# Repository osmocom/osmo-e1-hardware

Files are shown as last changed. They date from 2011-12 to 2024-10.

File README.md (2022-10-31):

osmo-e1-hardware - Collection of various E1/TDM hardware projects
=================================================================

This repository contains a variety of different projects related to
E1/TDM hardware interfaces

* `icE1usb` (fully-fledged USB E1 interface adapter)
* `osmo-e1-tracer` (fully integrated passive raw bitstream tracer)
* `osmo-e1-tap` (passive high-impedance E1/T1 tap)
* `osmo-e1-xcvr` (E1 LIU + magnetics)
  https://osmocom.org/projects/e1-t1-adapter/wiki/Osmo-e1-xcvr

icE1usb
-------

The Osmocom icE1usb project is an open source hardware, gateware and firmware
project implementing a USB-attached interface for E1 circuits.  Use this
if you want to implement a system speaking to an E1 circuit, such as
* a GSM BSC (using [OsmoBSC](https://osmocom.org/projects/osmobsc/wiki)) talking Abis/E1 to a GSM Base station,
* using [osmo-gbproxy](https://osmocom.org/projects/osmo-gbproxy/wiki/Osmo-gbproxy) to convert classing Gb/E1 to Gb/IP
* talking to legacy ISDN PRI equipment such as PBX, RAS servers, etc.
* connecting legacy ISDN PRI equipment such as PBX, RAS servers, etc. to
  the [OCTOI comminity TDMoIP network](https://osmocom.org/projects/octoi/wiki)

Depending on your USB host controller, it supports one or two E1
circuits. Most host controllers can only support one E1 circuit.

In order to provide a stable E1 clock reference, it contains a GPS disciplined oscillator.

See <https://osmocom.org/projects/e1-t1-adapter/wiki/IcE1usb> for more details.

Fully assembled units can be purchased at the [sysmocom
webshop](https://shop.sysmocom.de/Osmocom-icE1usb-E1-interface-for-USB/icE1usb-kit)

Check the `hardware/icE1usb`, `firmware/ice40-riscv/icE1usb` directories in this repository.

The host software is provided either
* via [osmo-e1d](https://osmocom.org/projects/osmo-e1d/wiki), or
* via the [icE1usb DAHDI driver](https://gitea.osmocom.org/retronetworking/dahdi-linux)

osmo-e1-tracer
--------------

This is a fully integrated design that allows you to obtain bi-directional high-impedance
bitstream E1 traces.  It features an iCE40 FPGA with USB + E1 cores from Sylvain Munaut,
as well as two E1 LIUs.

See <https://osmocom.org/projects/e1-t1-adapter/wiki/E1_tracer> for more details.

Fully assembled units can be purchased made-to-order from
[sysmocom](https://sysmocom.de).

Check the `hardware/e1-tracer`, `firmware/ice40-riscv/e1-tracer` and `software/e1-tracer`
directories in this repository.

osmo-e1-xcvr
------------

This was  a simple hardware project that aims to generate a reusable module
for interfacing E1/T1/J1 lines from various custom FPGA/CPLD/microcontroller
projects.  Consider it part of an earlier R&D setup before icE1usb and
osmo-e1-tracer were around.

The board contains transformers, the analog circuitry, the LIU (line interface
unit), an oscillator as well as an integrated transceiver chip.

It exposes the control interface (SPI) as well as the decoded synchronous
Rx/Tx bitstreams each on a 2x5pin header.

Framer, Multiplexer, HDLC decoder or anything like that is out-of-scope for
now.  The idea really is to provide an interface as low-level as possible.

One of the ideas is to create a "soft E1" interface, where the Rx/Tx bitstreams
are interfaced with the SSC of an AT91SAM3S and subsequently passed into a PC
via USB.  The 2Mbps signal is very low-bandwidth, so that a pure software
implementation should be absolutely no problem for todays computing power.

See <https://osmocom.org/projects/e1-t1-adapter/wiki/Osmo-e1-xcvr> for more details

Check the `hardware/e1-xcvr` directory in this repository.

osmo-e1-tap
-----------

This is a small passive board that allows you to perform high-impedance tracing on an E1
or T1 line.

Fully assembled units can be purchased at the [sysmocom
webshop](https://shop.sysmocom.de/E1-T1-tap-adapter/e1-tap).

Check the `hardware/e1-tap` directory in this repository.

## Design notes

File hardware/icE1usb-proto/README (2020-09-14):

icE1usb-proto: Early prototype (PMOD based)
===========================================

Files are hosted here for archival purposes only.

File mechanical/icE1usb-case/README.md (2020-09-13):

icE1usb case design
===================

The PCB has been specifically designed to fit into the SZOMK AK-C-B-37 with
silicone rings and custom end panels.

The design for the end panel can be found here in standard DXF format,
along with the various manufactured revisions and a change log.

Designs are (C) 2020 Sylvain Munaut and released under CC-BY-SA 4.0.

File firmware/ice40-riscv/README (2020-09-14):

Firmware for iCE40 based board
==============================

The icE1usb, icE1usb-proto and e1-tracer boards are running very similar
gateware, all based around a PicoRV32 RISC-V softcore supported by custom
hardware cores to deal with USB and E1.

License
-------

Files in here are licended either under GPLv3 or LGPLv3 depending on the
specific file. Refer to the notice at the top of each file.

Full text for both licenses is included next to this README.

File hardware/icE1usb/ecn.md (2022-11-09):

Electrical Engineering Change Notes
===================================

Revision 0.0
------------

### Description

First revision

### Manufactured

Boards ordered from Aisler on August 12th 2020.
Gerbers used are in the repo.

### Issues noticed

* The E1 TX pulse were very weak. Probably would have worked but to rise the pulse amplitude
  to 1.5 V, the series resistance were lowered to 27R. (Original iCEbreaker proto had 33R on
  the icebreaker + 47R on the PMOD. The bitsy proto only had the 47R)

### Notes

* Kicad files were not kept since it's the same schematic and layout as rev 0.1
  with some value changed and all boards were either built with new values or reworked.

Revision 0.1
------------

### Description

This revision is mostly just to keep a record of the changes that were applied
directly on the r0.0 prototypes and how they were assembled.

### Changes compared to previous revisions

* E1 TX side resistors changed to 27R (from 82R)

* Consequently all other uses of 82R were updated
    * PLL filter switched to use 120R
    * Series resistor for clock switched to 27R (which is probably better)

* Connection from GND to USB shield changed to 91k (from 1k5)

* All 47R networks were swapped for 33R. 
    * New value was picked so that including the UP5k drive impedance (~20R),
      it matches 50R more closely for USB
    * Other places where it's used don't matter much.
    * E1 LED current is dominated by 595 output impedance anyway.
    * 33R is just as fine for serial termination/EMI isolation for GPS signals.

* Some silkscreen label was added on the PCB

### Manufactured

Rev 0.0 PCBs were used and assembled / reworked to match this revision.
Two boards in total: one for @LaF0rge and one for @tnt.

### Issues noticed / remaining

* Flash footprint is wrong. The selected flash is not using the "wide" variant of SO8.

* The NT/TE selection pin-header is completely wrong

* The lightpipe is a bit loose. Turns out the holes came out 10% oversized out of Aisler :/
  Dimensions left as the manufacturer ones and hope that the prod are closer to nominal.

* The E1 bias configuration should probably have been reversed with the `bias_fixed`
  assigned to the `_n` side. This way the variable bias would have been lower and the common
  mode voltage closer to what the comparator expect for LVDS.

  This however would break compatibility with the proto which is a waste and has no real-world
  impact. The common-mode voltage change is minimal and comparator work fine where it is. And
  even if it was an issue we could put the variable bias lower and flip the input polarity in
  the bitstream.

Revision 1.0
------------

### Description

Production version, sent to manufacturer for production.

### Changes compared to previous revisions

* Silkscreen updated

* Flash footprint updated to narrow SO8 (150mil)

* Rewired the NT/TE header properly

* Changed RF trackwidth to 0.175 mm to account for production stackup

* Changed board outline to cater to connectors being more outward
    * Extended by 0.5 mm on front/back but only in the center part of the PCB
      to avoid interfering wih the silicone ring
    * Reworked the 'tabs'
    * Adjusted the expected end panel position lines to account for 1 mm silicone thickness

* Adjust positions of connectors / ... 
    * Moved RGB led & lightpipe outward by 500u
    * Moved Serial connector outward by 500u
    * Moved USB outward by 500u
    * Moved GPIO RJ45 outward by 500u
    * Moved dual-RJ45 outward by 500u
    * Moved button outward by 750u

* As a result of those moves some minor adjustments were made
    * Copper fills extended by 500u on the left side + reworked upper corner
    * Copper fills extended by 500u on the right side
    * To avoid the small protrusions in the planes, vias in the RX CT bias were moved inward

* Rerouted 1v2 on the bottom to add more distance from GND vias. Also widened the
  T junction to one of the via to 0.6 mm

### Manufactured

* 52 units ( 26 panels ) were manufactured in Aug/Sep 2020 and all came back in perfect working
  order.

### Issues noticed

* PCB is slightly loose in the case because the case we used were slightly over size.
    * The "side tabs" could be made slightly larger (and possibly slight round curve) to
      have a bit more friction.
    * The "front/back" edge part that touches the silicone ring could be made a bit longer
      to compress the silicone a bit.
    * Those 2 would be very slight changes, like ~ 0.1mm on each side, still have to account
      for possible tolerance in the cases that could be smaller than nominal !

* The I2C connection to the GPS conflicts with usage for the extension port. Turns out the
  chinese GPS module act as a master on those lines.
  See https://projects.osmocom.org/issues/5664 for details of the issue.

### Notes

* Adding series resistor for `gps_reset_n` and `gps_pps` was considered, but deemed not necessary.
    * Traces are short, always close to ground plane and we have no strong RF/EMI emitter onboard.
    * `gps_pps` is generated by the module itself, so any fast edge is coming from the module.
    * `gps_reset_n` is static.

* Adding a capacitor between `tx_hi` and `tx_lo` (after the series resistor) was also an option.
  Testing showed it didn't really change / improve the pulse shape and simulation showed increased
  peak current (and thus stress on the UP5k drivers). I considered adding a DNP footprint but area
  was a bit cramped and some more work would have been needed for something that would most likely
  stay unpopulated.

* A thought that occured to me to improve pulse shape is to use an external buffered gate (those
  sot-23/sc-67 single/double gate buffer ICs) and possibly putting it in parallel :

```
From  -----,----------,--\/\/\/--->  To TX
FPGA        \        /     R         Magnetics
             \__|\__/
	        |/
```

  This would take strain off the FPGA driver, provide more current and the  delay of the gate
  might actually help make the pulse shape more correct.

Revision 1.1
------------

### Description

Updated production version with minor fixes and a few adaptations for further production runs
by sysmocom.

### Changes compared to previous revisions

* Updated to kicad 6 format
* Renumbered schematic pages
* Added NO jumpers on the I2C lines to GPS module
* Added fiducials
* Silkscreen updated

### Manufactured

* 105 units manufactured by sysmocom at the end of 2022.

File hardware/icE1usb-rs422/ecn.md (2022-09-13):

Electrical Engineering Change Notes
===================================

Revision 0.1
------------

### Description

First revision

### Manufactured

Boards ordered from Aisler on August 15th 2022.
Sent directly the Kicad files. See r0.1/ directory.

### Issues noticed

* Missing I2C pull-ups on the isolated side.

* The pinout for the external RJ45 is completely wrong.

* The 1k across 12V dissipates 144 mW. It's above the rating for
  the jelly-bean 0603 resistors I originally used and it also
  gets quite warm.

* The 120R termination resistors also can dissipate quite a bit
  of power. Technicaly up to 6V across leading to 300 mW !
  In our case, it's more like 3V so it's only 75 mW but still,
  some margin would be nice.

* The linear 5V reg does heat up a bit. Nothing critical, but
  could be improved.

### Notes

* All boards have been reworked to fix most pressing issues :
    * 3k3 pullups added on the isolated side.
    * Cut & manually rewired the external RJ45 pinout.
    * 1k across 12V switched to high power 250mW part.
    * 120R termination switched to high power 250mW part.

* Boards location:
    * One remained with tnt.
    * Two sent to LaF0rge. One will be installed in the datacenter
      to be used with the OCTOI hub, the other will remain for testing.

Revision 0.2
------------

### Description

Potential future version, if ever done ...

### TODO

* Add I2C pull ups on the isolated side.

* Fix the external RJ45 pinout.

* Use switchmode converter for supply. AP3211 looks like a good candidate.

* Replace the 1k resistor across 12V with a resistor + zener + depletion n-mos
  so that it appears as 1k when supply is < ~4V but currents limit above that.

* Use 0805 termination resistors maybe ? Or at least spec those as high power
  variants.

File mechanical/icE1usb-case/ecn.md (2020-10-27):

Mechanical Engineering Change Notes
===================================

Revision 0.0
------------

### Description

Original design

### Manufactured

* Two pairs of front/back panels were ordered at [Schaeffer](https://www.schaeffer-ag.de/en/) in
  1.5 mm thickness since 1.2 mm is not available.

* Back panel was cut at Makilab by @tnt .

### Issues noticed

After trying to fit the back panel, it became obvious that the calculations were off and the
height of the PCB (1.6 mm) was not properly accounted for, resulting in openings that were all
1.6 mm too low.

### Notes

* DXF files were not kept.
* Feeds & Speeds in the FreeCAD toolpaths were completely off and were overriden manually.

Revision 0.1
------------

### Description

First revision done after the 1.6 mm offset error was noticed. It was done even before the
rev 0.0 panels were back from Schaeffer.

### Changes compared to previous revision

* Moved all opening 1.6 mm up.
* Size of the 'mouse ears' (for square holes) has been reduced to 2 mm diameter.
* Also made sure each square opening is a single poly-line in the DXF.

### Manufactured

* Cut two pairs of front/back panels at Makilab for the two proto cases. One of the back
  panel was the previously 'bad' one (rev 0.0) and so the opening is now too wide and not
  looking great, but it fits and is functional.

### Issues noticed

* The SMA hole height is too low. Nominal height above PCB was 6.4mm but that's for the
  TE-Connectivity part. The SMA we're using is more like 6.85mm above the surface. To fix
  this, the hole will be changed to be taller than wide to accomodate both parts.

* All the square opening (single RJ45, dual RJ45, USB) have their excess located at the top
  and have their bottom flush with the expected pcb height. This is different from the circular
  opening which are aligned on their center. So change the positions so the excess clearance is
  evenly distributed top/bottom of the expected position.

# Notes

* Although new FrontPanelDesigner files were made for this revision, they were never
  submitted / manufactured.

Revision 1.0
------------

### Description

Production version, sent to manufacturer for production.

### Changes compared to previous revision

* Converted the SMA opening from a pure-circle to two half circles connected by lines.
  The upper half circle is 0.5 mm above the previous center

* Moved USB, 1xRJ45 and 2xRJ45 opening 0.2 mm down

### Manufactured

* A run of 55 cases has been done, with end panels cut by the manufacturer.

### Issues noticed

* The cases are nominally 85 mm long, however seems all of them (both from prototype and
  production were slightly longer by about 0.2-0.4mm). This might be a result of the surface
  processing.

* The SMA hole is very close to the chamfer of the screw hole, leaving very little material
  between the two and on a couple of panels, it was ripped out or slightly bent by the end-mill
  during manufacturing. Most panels were fine and some slightly bent one could be corrected,
  but something to keep in mind.

* Also as a consequence of that we can't put a nut on the SMA on the inside (to grab panel by
  both side). Although I'm not sure it'd be good anyway. The SMA is the only element fixed to
  the panel (and thus the case), so all the forces of plugging connector are transfered through
  the PCB, through the SMA to the case. (because the PCB is slightly loose in the case to account
  for possible tolerances, see also comments in the PCB ECN).

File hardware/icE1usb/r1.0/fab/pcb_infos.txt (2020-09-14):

PCB material: FR-4
Board thickness: 1.6MM
Copper thickness: 1oz
Stackup:
	* L1-L2 is 0.1MM
	* 50R traces 6.5mil
Surface finishing: ENIG
Solder mask: Green
Silkscreen: White

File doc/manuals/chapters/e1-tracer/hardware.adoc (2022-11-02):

[[hardware]]
== e1-tracer Hardware

The e1-tracer Hardware consists of a single circuit board, mechanically
either assembled into a desktop enclosure (KOH variant) or into a 3U component
carrier module (BGT variant).

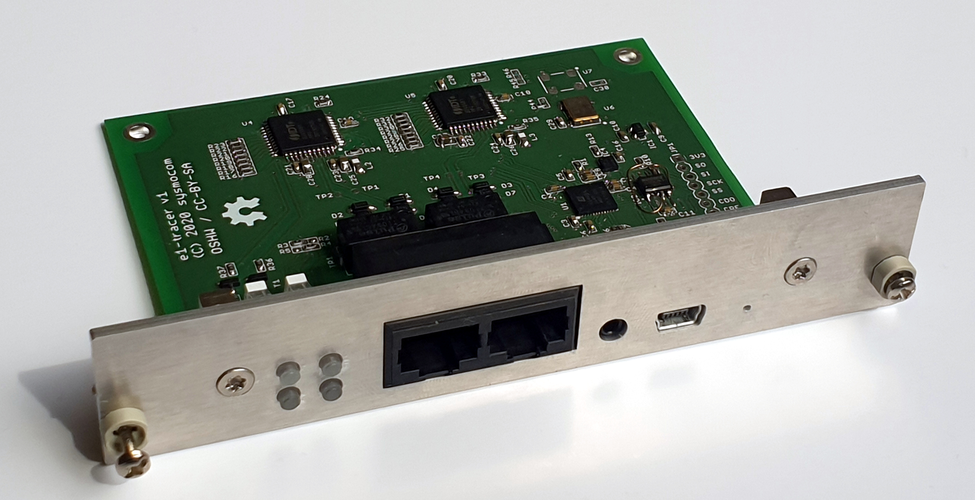
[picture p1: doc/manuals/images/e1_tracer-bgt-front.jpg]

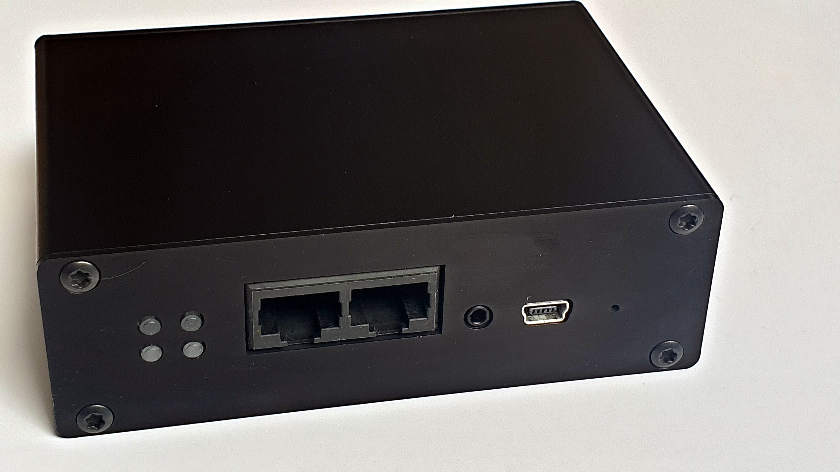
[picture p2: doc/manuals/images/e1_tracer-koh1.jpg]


It's main building blocks are:

* an iCE40 FPGA
* two E1 Line Interface Unit ICs
* two E1 line interface analog (transformers, biasing networks and ESD protection)

=== Schematics / Board Layout

As e1-tracer is an OSHW (Open Source Hardware) project, the full schematics
and design files are publicly available.

The design files in EAGLE format are available at https://git.osmocom.org/osmo-e1-hardware/tree/hardware/e1-tracer

PDF rendered schematics are available at https://gitea.osmocom.org/retronetworking/osmo-e1-hardware/raw/branch/master/hardware/e1-tracer/e1-tracer_sch.pdf

=== Connectors / LEDs

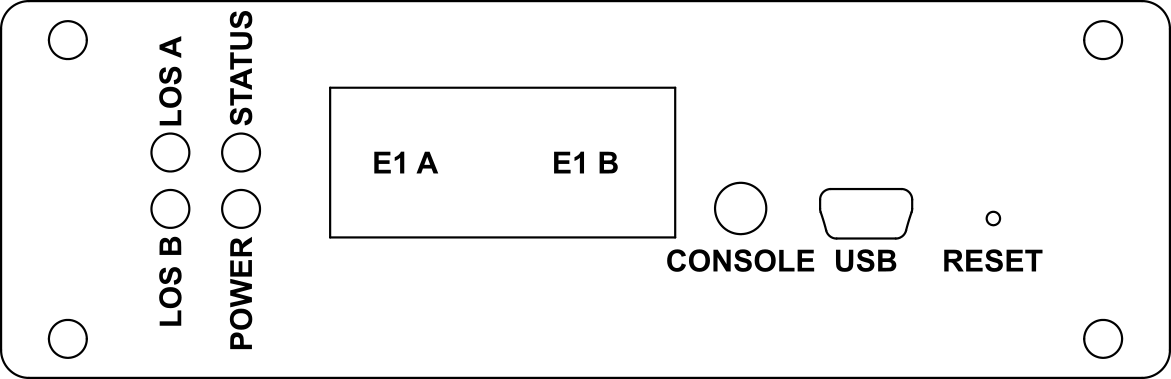
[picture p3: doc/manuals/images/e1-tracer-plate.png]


From left to right, there are the following LED indcators, connectors and buttons:

* LED block with 4 LED's
* Primary E1 Port (E1 A)
* Secondary E1 Port (E1 B)
* Serial Console Connector
* USB Connector
* Bootloader Button

==== LEDs

The left-most column of LEDs consists of two red *LOS LEDs*.
They indicate a LOS (Loss Of Signal) condition for the respective E1 direction.  It is normal for the LEDs to be illuminated even in presence of a valid E1 signal until the host software has fully initialized the firmware for the first time after power-up.

The right column of LEDs consists of two further LEDs:

* a multi-color *STATUS LED* on the top
* a green *POWER LED* on the bottom

The *STATUS LED* is used by the firmware to indicate a variety of status
information.  Pleas see the firmware documentation in <<firmware>>.

The green *POWER LED* is illuminated as soon as the device has DC power.

==== J1A and J1B: E1 Interface Connectors

There are two RJ45 connectors next to each other.

Those are the connections for your symmetric 120 Ohms E1 interface
circuit.  You insert the e1-tracer into your E1 link.  The two ports are
internally wired straight-through, so you can insert the e1-tracer into
your E1 link.

The actual tracing functionality is implemented via a high-impedance
tap, which will not disturb the normal E1 communications link. The link
remains unaffected even if the e1-tracer is unpowered.

.Pin-out of RJ45 E1 connectors
[options="header"]
|===
| Pin | Function (TE) | Function (NT Mode)
| 1   | Pair A        | Pair A
| 2   | Pair A        | Pair A
| 3   | not used      | not used
| 4   | Pair B        | Pair B
| 5   | Pair B        | Pair B
| 7   | not used      | not used
| 8   | not used      | not used
|===

NOTE: E1 cables use RJ45 like Ethernet, but Ethernet cables have a
different pin-out.  Particularly, you cannot use an Ethernet cross-over
cable as an E1 cross-over!

==== X1: USB Connector

The USB connector is a USB Mini B connector.   The e1-tracer uses
USB 1.1 full-speed signals.  As the e1-tracer is a bus-powered device,
5V DC power is also sourced from this connector.

==== X2: Serial Console Connector

The serial console is used for development and debugging.  It uses an
Osmocom-style 2.5mm stereo TRS jack.

The serial console uses 3.3V CMOS logic levels

The serial console uses a rate of 1000000 bps.

The pin-out is as follows:

* Tip: Tx output from PC (Rx input of e1-tracer)
* Ring: Rx input of PC (Tx output of e1-tracer)
* Shield: GND

A compatible cable can be sourced from the sysmocom web-shop at
http://shop.sysmocom.de/.

Note that CP2102 based cables require special programming to support
the baud rate of 1000000 (as opposed to the more standard 921600).

[[hw-pushbutton]]
=== Bootloader Button

There is a push-button next to the _USB B connector_.   It is recessed
to protect against accidental use.   You will need to use a paper clip,
pen tip or other similar object to push it.

The button, when pressed while power-up, can be used to force booting
into the DFU loader in order to recover from a broken firmware
installation.

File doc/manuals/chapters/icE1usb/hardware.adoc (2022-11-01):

[[hardware]]
== icE1usb Hardware

The icE1usb Hardware consists of a single circuit board (in an optional
enclosure).

It's main building blocks are:

* an iCE40 FPGA
* Two E1 line interface (transformers, biasing networks and ESD protection) footnote:[Second interface requires firmware >= 0.2 and OHCI/OHCI/EHCI host controller]
* a GPS receiver module with 1PPS output to the FPGA footnote:[Requires firmware >= 0.2]

=== Schematics

As icE1usb is an OSHW (Open Source Hardware) project, the full schematics
and design files are publicly available.

The design files in KiCAD format are available at https://git.osmocom.org/osmo-e1-hardware/tree/hardware/icE1usb

PDF rendered schematics are available at https://git.osmocom.org/osmo-e1-hardware/plain/hardware/icE1usb/r1.0/icE1usb.pdf

=== Connectors on E1 side

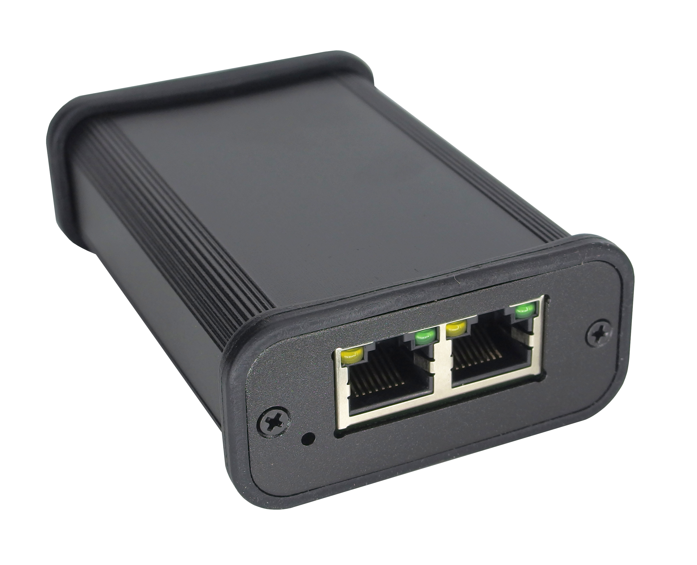
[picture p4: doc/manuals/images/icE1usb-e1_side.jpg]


From left to right, there are the following connectors:

* X5A: Primary E1 Port
* X5B: Secondary E1 Port

==== X5A and X5B: E1 Interface Connectors

On one side of the PCB there are two RJ45 connectors next to each other.

Those are the two E1 line interfaces.  The interfaces are of symmetric
120 Ohms type.

Assuming the board is oriented with the tab of the RJ45 connectors facing
up:

* Interface 0 is on the right side
* Interface 1 is on the left side (next to the button)

The pin-out of the connectors can be swapped between TE and NT mode using
the J4 and J5 jumper blocks on the circuit board.

The factory default setting of the jumpers is TE-mode.

In case you're using the icE1usb with user-side equipment such as a GSM BTS,
a PBX, a Router or the like which traditionally was attached to the public
network, those devices all implement TE mode.  In such situations you need
to either switch the icE1usb to NT mode (and use straight wiring), or use
an E1 cross-over cable.

.Pin-out of RJ45 E1 connectors
[options="header"]
|===
| Pin | Function (TE) | Function (NT Mode)
| 1   | Rx            | Tx
| 2   | Rx            | Tx
| 3   | not used      | not used
| 4   | Tx            | Rx
| 5   | Tx            | Rx
| 7   | not used      | not used
| 8   | not used      | not used
|===

NOTE: E1 cables use RJ45 like Ethernet, but Ethernet cables have a
different pin-out.  Particularly, you cannot use an Ethernet cross-over
cable as an E1 cross-over!

==== Switching between TE/NT mode

To change the mode, unscrew the 2 PH0 screws on the side with the 2 RJ45 jacks. You'll also need to unscrew the nut on the SMA jack on the other side.
After that, the cover plate and rubber gasket around the 2 RJ45 jacks can be removed. The PCB can be slid out of the case.

[frame="none"]
[grid="none"]
|===
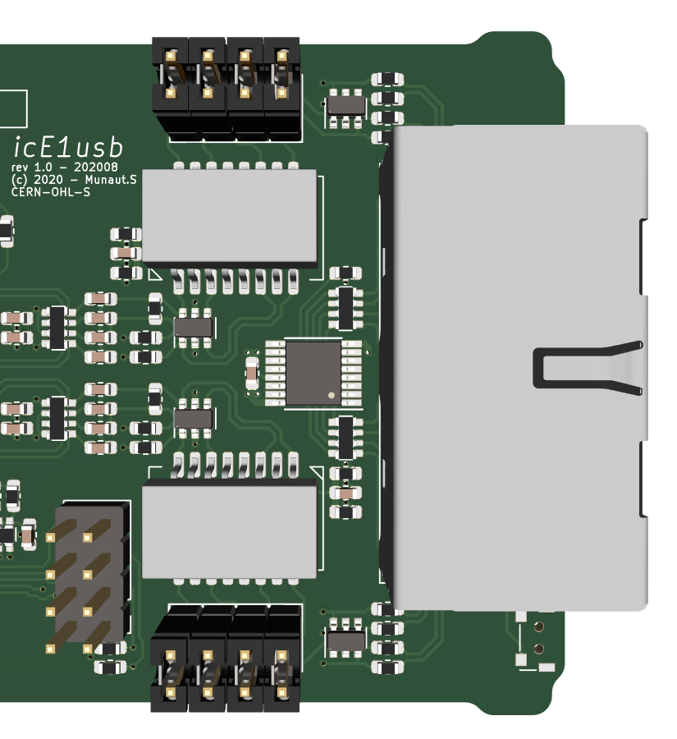
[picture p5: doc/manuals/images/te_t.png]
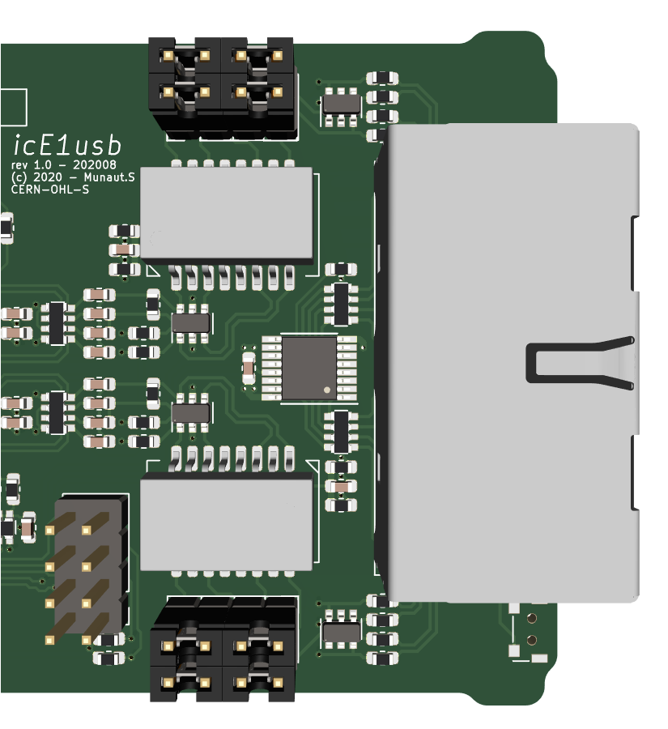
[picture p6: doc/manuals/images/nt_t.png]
| |
| *TE mode* (default)  | *NT mode*  |
|===

Each 2x4 jumper block is connected to the nearest RJ45 connector.

=== Connectors on USB side

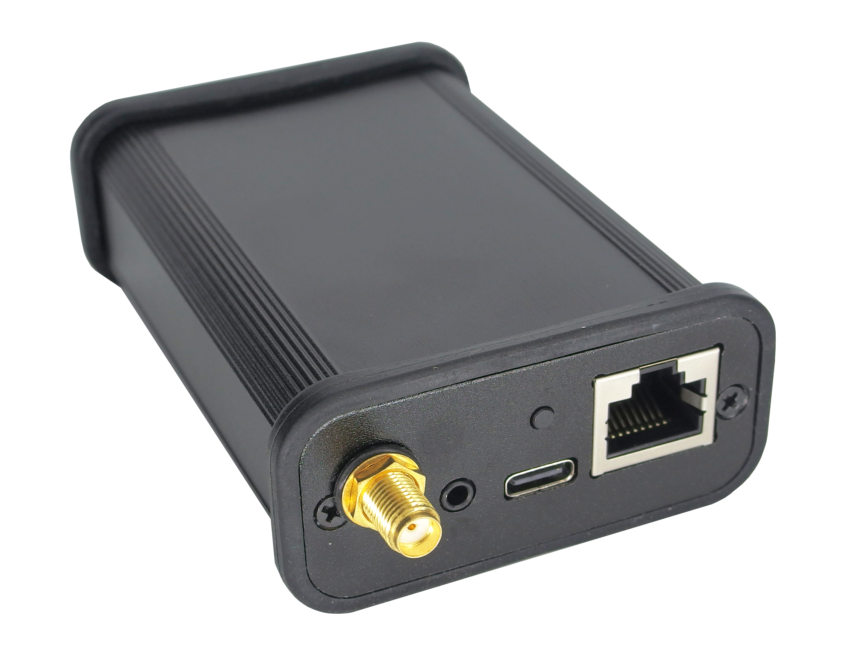
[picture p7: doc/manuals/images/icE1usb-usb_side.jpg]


From left to right, there are the following connectors:

* X1: GPS Antenna Connector
* X2: Serial Console Connector
* X4: USB Connector
* X3: GPIO / Extension Connector

==== X4: USB Connector

The USB connector is a USB Type C connector.   However, it only carries
USB 1.1 full-speed signals.  5V DC power is also sourced from this
connector.

==== X2: Serial Console Connector

The serial console is used for development and debugging.  It uses an
Osmocom-style 2.5mm stereo TRS jack.

The serial console uses 3.3V CMOS logic levels

The serial console uses a rate of 1000000 bps.

The pin-out is as follows:

* Tip: Tx output from PC (Rx input of icE1usb)
* Ring: Rx input of PC (Tx output of icE1usb)
* Shield: GND

A compatible cable can be sourced from the sysmocom web-shop at
http://shop.sysmocom.de/.

==== X1: GPS Antenna Connector

The GPS antenna connector is a female SMA connector.

You can connect most standard active GPS antennas with built-in LNA.

icE1us provide phantom voltage.

The use of a GPS antenna is only required when you need a high precision
clock reference for the 2.048 MHz E1 bit clock, e.g. to provide a clock
reference to a cellular base station on the A-bis interface.

==== X3: GPIO / Extension Connector

This is a RJ45 connector adjacent to the USB connector.

It is currently unused and reserved for future use.

[[hw-pushbutton]]
=== Pushbutton

This is a push-button next to the _E1 interface '1'_.   It is recessed
to protect against accidental use.   You will need to use a paper clip,
pen tip or other similar object to push it.

The button can be used to force booting into the DFU loader in order to
recover from a broken firmware installation.

=== Multi-Color LED

Above the USB-C connector, there is a multi-color RGB LED.

This LED is used by the firmware to indicate a variety of status
information.  Pleas see the firmware documentation in <<firmware>>.

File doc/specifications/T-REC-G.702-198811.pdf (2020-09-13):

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

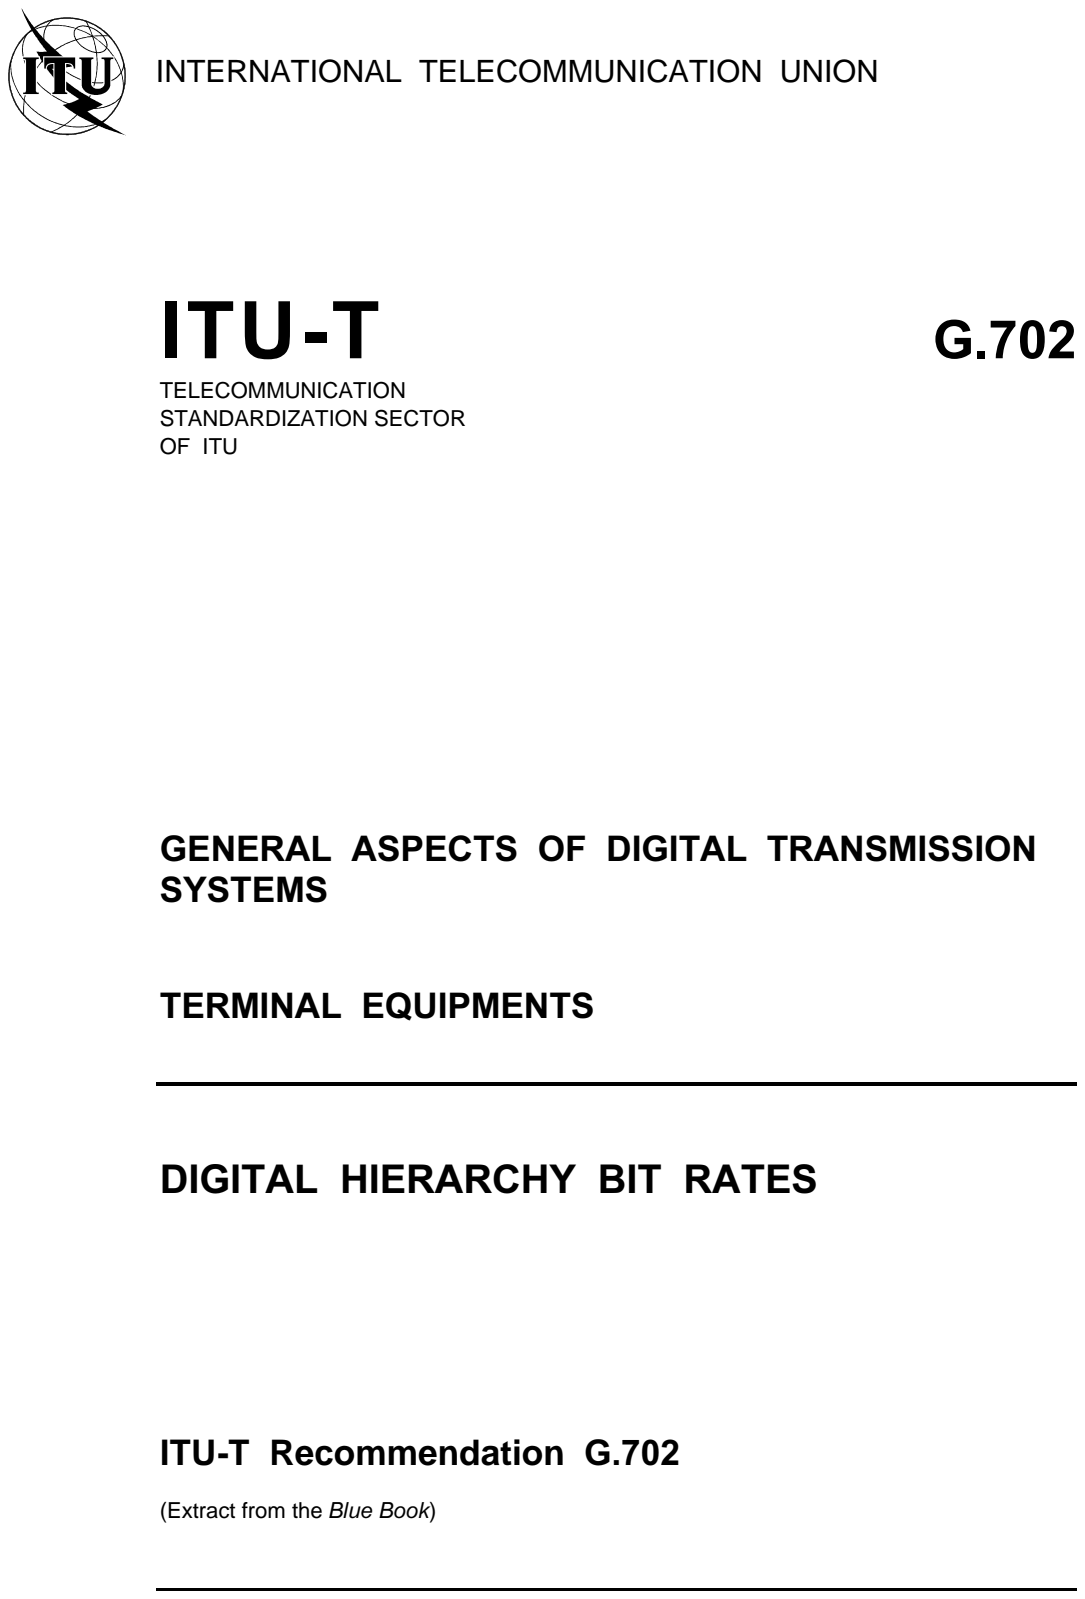
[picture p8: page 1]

NOTES

1 | ITU-T Recommendation G.702 was published in Fascicle III.4 of the Blue Book. This file is an extract from
the Blue Book. While the presentation and layout of the text might be slightly different from the Blue Book version, the contents of the file are identical to the Blue Book version and copyright conditions remain unchanged (see below).
2 | In this Recommendation, the expression “Administration” is used for conciseness to indicate both a
telecommunication administration and a recognized operating agency.
- ITU 1988, 1993

All rights reserved. No part of this publication may be reproduced or utilized in any form or by any means, electronic or mechanical, including photocopying and microfilm, without permission in writing from the ITU.

Fascicle III.4 - Rec. G.702 | 1

Recommendation G.702

Fascicle III.4 - Rec. G.702

DIGITAL HIERARCHY BIT RATES

(Malaga-Torremolinos, 1984; amended at Melbourne, 1988)

The CCITT,

considering

(a) that digital hierarchy bit rates are those bit rates which are or will be used as the basis for higher digital hierarchy levels if such levels exist (see Recommendation G.701, definition 4003);
(b) that the specification of hierarchical bit rates is necessary to prevent the proliferation of interface standards used in digital networks;
(c) that international interconnections of digital network components are preferably carried out at hierarchical bit rates;
(d) that when determining hierarchical bit rates a number of factors relating to services, transmission media and networking need to be taken into account, for example:
- characteristics of and suitable coding method for analogue source signals;
- bit rates of digital source signals;
- use of available transmission media;
- compatibility with analogue multiplex systems;
- modularity and flexibility in assembling and routing groups of source signals,

recommends

that the following bit rates should be used as hierarchical bit rates in digital networks:

Figure 1/G.702 and Figure 2/G.702 show the recommended hierarchical bit rates only, including references to related Recommendations on network interfaces, multiplex equipments, digital sections/systems.

Recommendations on the following may also exist, but are not identified in Figure 1/G.702 and Figure 2/G.702:

- multiplex equipments operating between non-adjacent levels of the digital hierarchy;
- network interfaces, multiplex equipments and digital sections/systems at non-hierarchical bit rates.

Annex A to this Recommendation provides guidelines on usable bits available for services.

Digital Hierarchy Level | Hierarchical bit rates (kbit/s) for networks with the digital hierarchy based on a first level bit rate of
1 2 3 4 | 64 1544 6312 | 64 2 048 8 448 139 264
1544 kbit/s | 2048 kbit/s

32 064

97 728

44 736 | 34 368

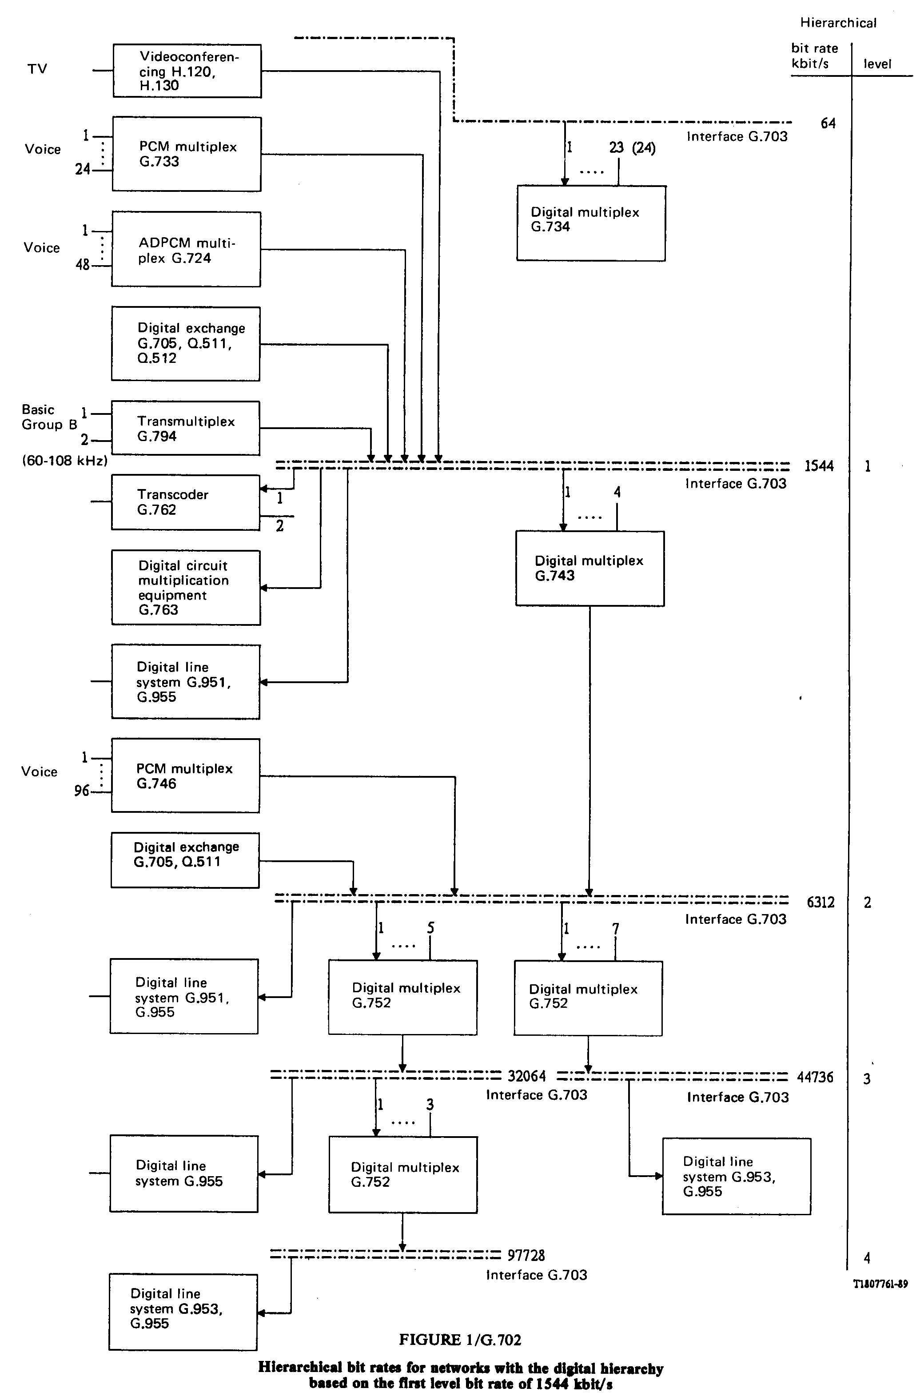
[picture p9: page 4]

2 | Fascicle III.4 - Rec. G.702

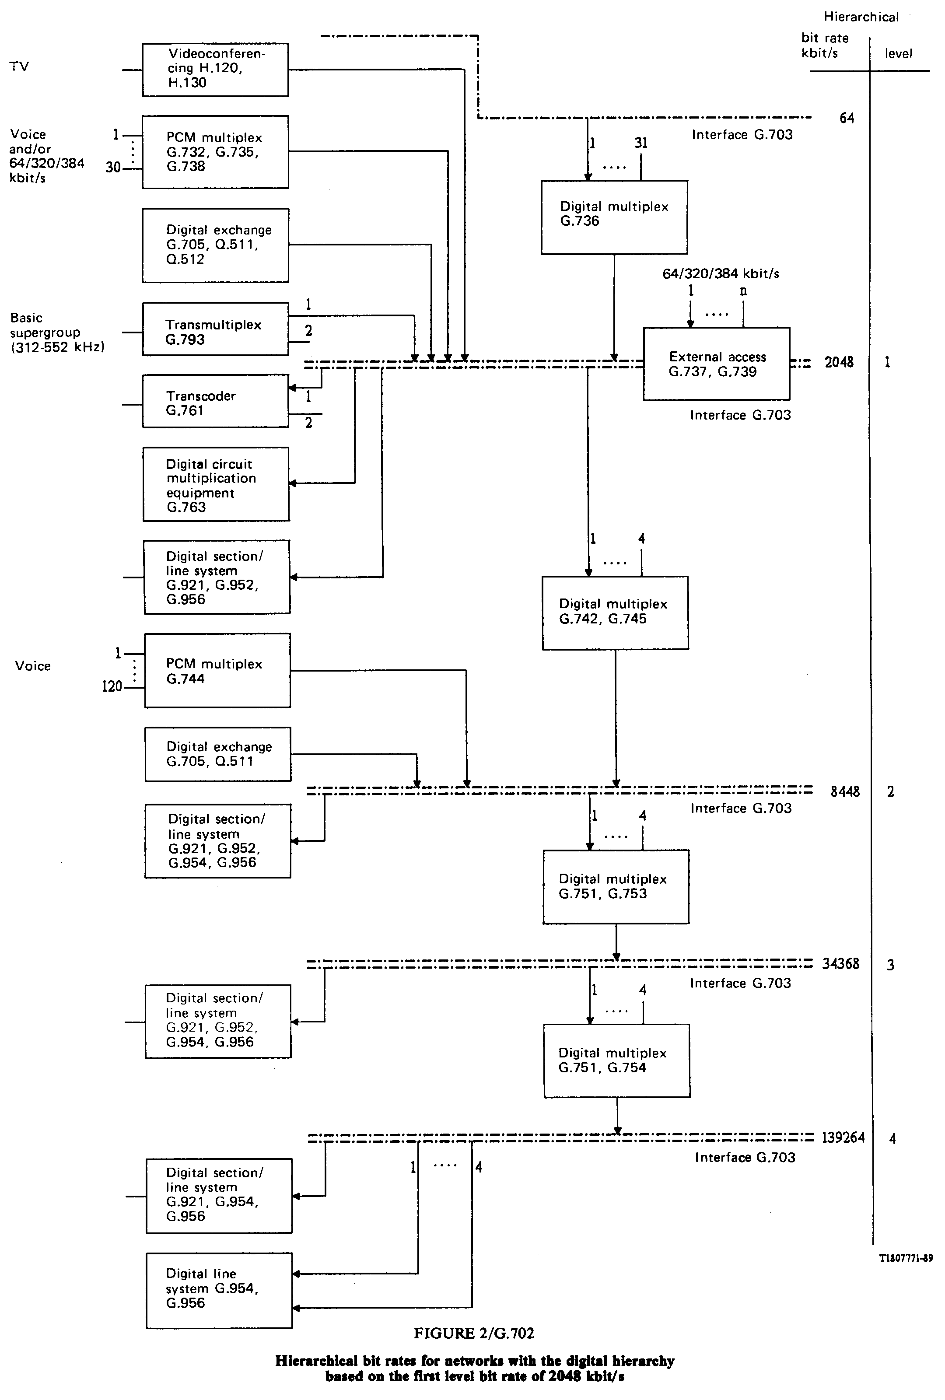
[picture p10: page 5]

Fascicle III.4 - Rec. G.702 | 3

4 | Fascicle III.4 - Rec. G.702

ANNEX A

(to Recommendation G.702)

Usable bit rates available for services

In the case of access to the ISDN for broadband services, bit rates up to the primary hierarchy level are specified in the I.200 series of Recommendations.

In general, with regard to bit rates available for transport of service signals, the following guidelines apply:

A.1 For the hierarchies based on the 1544 kbit/s primary rate, the principle has been established that some bits in the frame should be reserved, in particular to perform quality control of the digital paths when several digital sections in tandem are involved. Table A-1/G.702 provides the necessary information.

TABLE A-1/G.702

Bit rates available for services and frame structures required at hierarchical interfaces

a) The use of the F-bit for purposes additional to framing is under study.
b) In networks with asynchronous operation.
c) In networks with synchronous operation.
d) In some applications, the C-bits (Cj1 Cj2 and Cj3

) may also need to be reserved. In this case, the bit rate available for services becomes 44 209 kbit/s.

A.2 In case of networks using 2048 kbit/s based hierarchy there is in principle no basic restriction on the use of full capacity of the digital path. However, it is recognized that compatibility with recommended frame structures at the various levels of the 2 Mbit/s hierarchy (e.g. the use of the same frame alignment pattern) could be a preferred solution since it offers the following advantages:

- use of the same framing devices for switched and non-switched applications;
- end-to-end quality control performed in a unique way by the network when the maintenance entity that
| terminates the service (e.g. the encoding device) does not belong to the network;
- possibility of performing additional network management functions that could be required, depending on
| the applications.
| The preference for compatibility with recommended frame structures could be reconsidered for the applications
where significant restrictions on the efficient use of the digital path capability can be identified.
Hierarchy bit rate (kbit/s) | Frame structure as per Recommendations | Reserved bits | Bit rate available for services (kbit/s)
1 544 | G. 704 | F a) | 1 536
6 312 b) | Not applicable | None | 6 312
6 312 c) | G.704 | F bits and bits in time slots 97 and 98 | 6 144
44 736 | G.752 | d) Mj F0, F11, F12 | 44 407 d)
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

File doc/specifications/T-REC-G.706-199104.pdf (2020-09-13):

## INTERNATIONAL TELECOMMUNICATION UNION

CCITT | G.706

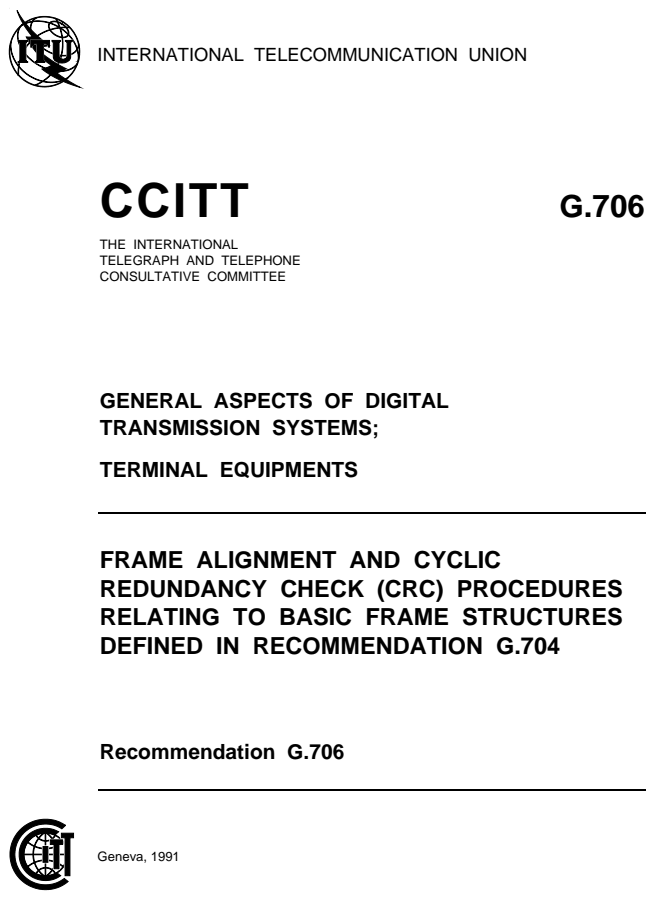
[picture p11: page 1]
Recommendation G.706; Geneva, 1991

THE INTERNATIONAL
TELEGRAPH AND TELEPHONE
CONSULTATIVE COMMITTEE

GENERAL ASPECTS OF DIGITAL
TRANSMISSION SYSTEMS;
TERMINAL EQUIPMENTS

FRAME ALIGNMENT AND CYCLIC
REDUNDANCY CHECK (CRC) PROCEDURES
RELATING TO BASIC FRAME STRUCTURES
DEFINED IN RECOMMENDATION G.704

FOREWORD

The CCITT (the International Telegraph and Telephone Consultative Committee) is a permanent organ of the International Telecommunication Union (ITU). CCITT is responsible for studying technical, operating and tariff questions and issuing Recommendations on them with a view to standardizing telecommunications on a worldwide basis.

The Plenary Assembly of CCITT which meets every four years, establishes the topics for study and approves Recommendations prepared by its Study Groups. The approval of Recommendations by the members of CCITT between Plenary Assemblies is covered by the procedure laid down in CCITT Resolution No. 2 (Melbourne, 1988).

Recommendation G.706 was prepared by Study Group XVIII and was approved under the Resolution No. 2 procedure on the 5th of April 1991.

___________________

CCITT NOTES

1) In this Recommendation, the expression “Administration” is used for conciseness to indicate both a telecommunication Administration and a recognized private operating agency.
2) A list of abbreviations used in this Recommendation can be found in Annex D.
- ITU 1991

All rights reserved. No part of this publication may be reproduced or utilized in any form or by any means, electronic or mechanical, including photocopying and microfilm, without permission in writing from the ITU.

Recommendation G.706 | 1

Recommendation G.706

Recommendation G.706

FRAME ALIGNMENT AND CYCLIC REDUNDANCY CHECK (CRC) PROCEDURES RELATING TO BASIC FRAME STRUCTURES DEFINED IN RECOMMENDATION G.704

(Melbourne, 1988, revised 1990)

### 1 General

This Recommendation relates to equipment which receives signals with basic frame structures as defined in Recommendation G.704. It defines the frame alignment, the cyclic redundancy check (CRC) multiframe alignment and CRC bit error monitoring procedures to be used by such equipment. Annex A contains background information about the use of the CRC procedures and their limitations.

Annex B gives details of a modified CRC-4 multiframe alignment algorithm which allows automatic interworking between equipment with and without a CRC-4 capability. Annex C gives details regarding the updating of CRC-4 information when an intermediate equipment (i.e. between true path terminating equipments) has a write-access to a message-based data-link facility (see Recommendation G.704, § 2.3.3.5.4).

### 2 Frame alignment and CRC procedures at l544 kbit/s interface

2.1 Loss and recovery of frame alignment There are two alternative multiframe structures at the 1544 kbit/s interface:

a) 24-frame multiframe, and
b) 12-frame multiframe.

2.1.1 Loss of frame alignment The frame alignment signal should be monitored to determine if frame alignment has been lost. Loss of frame

alignment should be detected within 12 ms. Loss of frame alignment must be confirmed over several frames to avoid the unnecessary initiation of the frame alignment recovery procedure due to transmission bit errors. The frame alignment recovery procedure should commence immediately once loss of frame alignment has been confirmed.

| Note – For the 12-frame multiframe described in Recommendation G.704, loss of multiframe alignment is
deemed to occur when loss of frame alignment occurs.
2.1.2 | Recovery of frame alignment
2.1.2.1 | Frame alignment recovery time The frame alignment recovery time is specified in terms of the maximum average reframe time in the absence

of errors. The maximum average reframe time is the average time to reframe when the maximum number of bit positions must be examined for locating the frame alignment signal.

a) 24-frame multiframe
| The maximum average reframe time should not exceed 15 ms. Note – Some existing designs of equipment were designed to a limit of 50 ms.

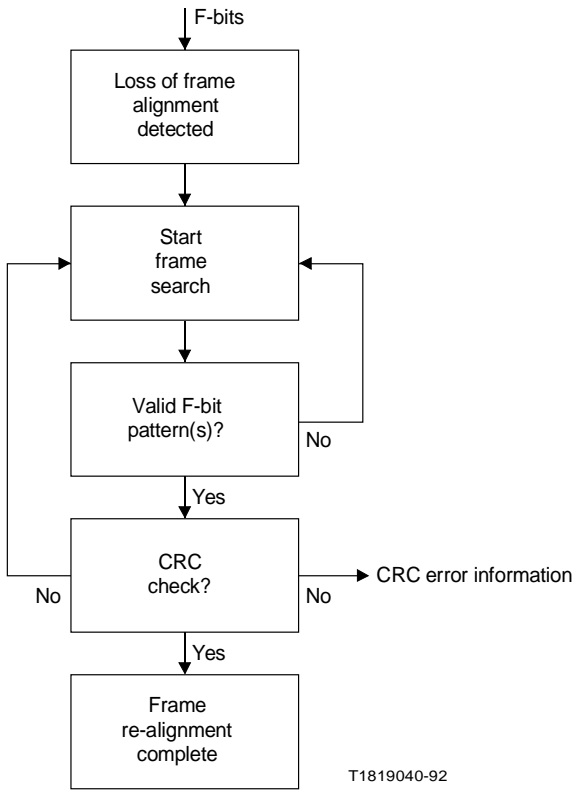
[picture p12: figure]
Loss of frame alignment detected; Start frame search; Valid F-bit pattern(s)?; CRC check?; Frame re-alignment complete; Yes; F-bits; CRC error information

### 2 Recommendation G.706

b) 12-frame multiframe

The maximum average reframe time should not exceed 50 ms.

Note – These times do not include the time required for the CRC procedure for false frame alignment verification defined in § 2.2.2.

2.1.2.2 Strategy for frame alignment recovery

a) 24-frame multiframe
| Frame alignment should be recovered by detecting the valid frame alignment signal. When the CRC-6 code is utilized for error performance monitoring (see § 2.2.3), the CRC-6 information may be coupled with the framing algorithm to ensure that a valid frame alignment signal contained within the 24 F-bits is the only pattern onto which the reframe circuit can permanently lock. This procedure is illustrated in

Figure 1/G.706.

b) 12-frame multiframe
| Overall frame alignment should be recovered by way of simultaneous detection of the frame alignment signal and the multiframe alignment signal, or of frame alignment followed by multiframe alignment.

FIGURE 1/G.706
False frame alignment protection using a cyclic redundancy check (CRC) (1544 and 6312 kbit/s)

Recommendation G.706 | 3
2.2 | CRC bit monitoring
| Error monitoring by CRC-6 assumes a signal quality sufficient for frame alignment to be established so that
CRC-6 bits can be correctly accessed.

2.2.1 Monitoring procedure

i) A received CRC message block (CMB) is acted upon by the multiplication/division process defined in
| Recommendation G.704 after having its F-bits replaced by binary 1s. ii) The remainder resulting from the division process is then stored and compared on a bit-by-bit basis with the CRC bits received in the next CMB. iii) If the remainder exactly corresponds to the CRC bits contained in the next CMB of the received signal, it is assumed that the checked CMB is error-free.
2.2.2 | Monitoring for false frame alignment (see § A.1.1)
| In the case of the 24-frame multiframe, when the CRC-6 code is utilized for error performance monitoring, it
may also be used to provide immunity against spurious frame alignment signals. The procedure described in § 2.1.2.2 a) should be followed.
2.2.3 | Error performance monitoring using CRC-6 (see § A.1.2)
| For the purpose of error performance monitoring, it should be possible to obtain indications of each CRC
message block which is received in error. The consequent error information should be used in accordance with the requirements to be defined in respective equipment Recommendations.

### 3 Frame alignment and CRC procedures at 6312 kbit/s interface

3.1 | Loss and recovery of frame alignment
| For the 6312 kbit/s hierarchical level, the term “frame alignment” is synonymous of “multiframe alignment”.
The last five bits of the 789-bit frame are designated as the F-bits (see Recommendation G.704) and are time-shared as a frame alignment signal and for other purposes.
3.1.1 | Loss of frame alignment
| The frame alignment signal should be monitored to determine if frame alignment has been lost. The loss of
frame alignment is declared when seven consecutive incorrect frame alignment signals have been received.
| The recovery of frame alignment procedure should start immediately once loss of frame alignment has been
confirmed.

### 4 Recommendation G.706

3.1.2 | Recovery of frame alignment
3.1.2.1 | Frame alignment recovery time The frame alignment recovery time is specified in terms of the maximum average reframe time in the absence

of errors. The maximum average reframe time is the average time to reframe when the maximum number of bit positions must be examined for locating the frame alignment signal.

| The maximum average reframe time should be less than 5 ms.
3.1.2.2 | Strategy for frame alignment recovery Frame alignment should be recovered by detecting three consecutive correct frame alignment signals. In

addition to this, the CRC-5 code (see § 3.2) should be coupled with the framing algorithm to ensure that a valid frame alignment signal contained within the F-bits is the only pattern onto which the reframe circuit can permanently lock. This procedure is illustrated in Figure 1/G.706.

3.2 CRC bit monitoring Error monitoring by CRC-5 assumes a signal quality sufficient for frame alignment to be established so that

the CRC-5 bits can be correctly accessed.

3.2.1 Monitoring procedure

i) A received sequence of 3156 serial bits (i.e. 3151 bits of CMB and 5 CRC bits) is divided by the
| generator polynomial defined in Recommendation G.704. ii) If the remainder resulting from the division process is 00000, it is assumed that the checked CMB is error-free.
3.2.2 | Monitoring for false frame alignment (see § A.1.1) The procedure in § 3.1.2.2 should be followed when the CRC-5 code is used to provide immunity against false

frame alignment signal.

| Using the CRC-5 code, it should be possible to detect false frame alignment within 1 second and with greater
than 0.99 probability. On detection of such an event, a research for correct frame alignment should be initiated.
| With a random error ratio of 10⁻⁴, the mean time between two events of falsely initiating a search for frame
alignment due to an excessive number of errored CRC message blocks should be more than one year.
| Note 1 – With a random error ratio of approximately 10⁻³, it is almost impossible to distinguish whether CRC
errors are caused by the false frame alignment or by transmission bit errors.
| Note 2 – To achieve the probability bounds stated above, one method is to count the errored CRC-5 message
blocks with the understanding that a count of 32 consecutive errored CRC-5 blocks indicates false frame alignment.

3.2.3 Error performance monitoring using CRC-5 (see § A.1.2) For the purpose of error performance monitoring, it should be possible to obtain indications for each CRC

message block which is received in error. The consequent error information should be used in accordance with the requirements to be defined in the respective equipment Recommendations.

Recommendation G.706 | 5

### 4 Frame alignment and CRC procedures at 2048 kbit/s interface

4.1 | Loss and recovery of frame alignment
4.1.1 | Loss of frame alignment

Frame alignment will be assumed to have been lost when three consecutive incorrect frame alignment signals have been received.

Note 1 – In addition to the preceding, in order to limit the effect of spurious frame alignment signals, the following procedure may be used:

Frame alignment will be assumed to have been lost when bit 2 in time slot 0 in frames not containing the frame alignment signal has been received with an error on three consecutive occasions.

Note 2 – Loss of frame alignment can also be invoked by an inability to achieve CRC multiframe alignment in accordance with § 4.2, or by exceeding a specified count of errored CRC message blocks as indicated in § 4.3.2.

4.1.2 Strategy for frame alignment recovery

Frame alignment will be assumed to have been recovered when the following sequence is detected:

– | for the first time, the presence of the correct frame alignment signal;
– | the absence of the frame alignment signal in the following frame detected by verifying that bit 2 of the
basic frame is a 1;

– for the second time, the presence of the correct frame alignment signal in the next frame.

Note – To avoid the possibility of a state in which no frame alignment can be achieved due to the presence of a spurious frame alignment signal, the following procedure may be used:

When a valid frame alignment signal is detected in frame n, a check should be made to ensure that a frame alignment signal does not exist in frame n + 1, and also that a frame alignment signal exists in frame n + 2. Failure to meet one or both of these requirements should cause a new search to be initiated in frame n + 2.

4.2 CRC multiframe alignment using information in bit 1 of the basic frame

If a condition of assumed frame alignment has been achieved, CRC multiframe alignment should be deemed to have occurred if at least two valid CRC multiframe alignment signals can be located within 8 ms, the time separating two CRC multiframe alignment signals being 2 ms or a multiple of 2 ms. The search for the CRC multiframe alignment signal should be made only in basic frames not containing the frame alignment signal.

If multiframe alignment cannot be achieved within 8 ms, it should be assumed that frame alignment is due to a spurious frame alignment signal and a research for frame alignment should be initiated.

Note 1 – The research for frame alignment should be started at a point just after the location of the assumed spurious frame alignment signal. This will usually avoid realignment onto the spurious frame alignment signal.

Note 2 – Consequent actions taken as a result of loss of frame alignment should no longer be applied once frame alignment has been recovered. However, if CRC multiframe alignment cannot be achieved within a time limit in the range of 100 ms to 500 ms, e.g. owing to the CRC procedure not being implemented at the transmitting side, consequent actions should be taken equivalent to those specified for loss of frame alignment.

### 6 Recommendation G.706

Note 3 – Equipment incorporating the CRC-4 procedure should be designed to be capable of interworking with equipment which does not incorporate the CRC-4 procedure; that is, an ability to continue to provide service (traffic) between equipments with and without a CRC-4 capability. This can be achieved either manually (e.g. by straps) or automatically.

– For the manual case, the equipment incorporating the CRC-4 procedure should be capable of fixing bit-1 of the frame to the binary “1” (see Table 4a/G.704 Note 1).

– | For the automatic case, this can be achieved at the equipment having the CRC-4 capability either:
– | as a “higher-layer” function under the control of a network management facility (e.g. a TMN) – the
details are for futher study; or

– as a “lower-layer” function using a modified CRC-4 multiframe alignment algorithm as described in Annex B.

4.3 CRC bit monitoring If frame and CRC multiframe alignment have been achieved, the monitoring of the CRC bits in each

sub-multiframe should commence.

4.3.1 Monitoring procedure

i) A received CRC sub-multiframe (SMF) is acted upon by the multiplication/division process defined in
| Recommendation G.704 after having its CRC bits extracted and replaced by 0s. ii) The remainder resulting from the division process is then stored and subsequently compared on a bit-by-bit basis with the CRC bits received in the next SMF. iii) If the remainder exactly corresponds to the CRC bits contained in the next SMF of the received signal, it is assumed that the checked SMF is error-free.
4.3.2 | Monitoring for false frame alignment (see § A.1.1) It should be possible to detect a condition of false frame alignment within 1 second and with a probability

greater than 0.99. On detection of such an event, a research for frame alignment should be initiated.

| With a random error ratio of 10⁻³ the probability of falsely initiating a search for frame alignment due to an
excessive number of errored CRC blocks should be less than 10⁻⁴ over a 1 second period.

Figure 2/G.706 shows an illustration of the procedure to be followed in passing from the frame alignment search to error monitoring using CRC.

| Note 1 – The research for frame alignment should be started at a point just after the location of the assumed
spurious frame alignment signal. This will usually avoid realignment onto the spurious frame alignment signal.
| Note 2 – To achieve the probability bounds stated above, a preferred threshold count is 915 errored CRC
blocks out of 1000, with the understanding that a count of ≥ 915 errored CRC blocks indicates false frame alignment.

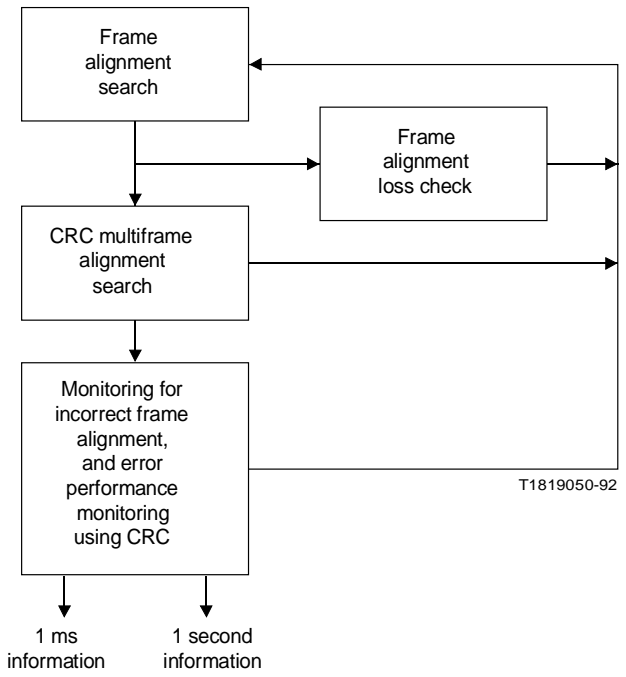
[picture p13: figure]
Frame alignment search; CRC multiframe alignment search; Monitoring for incorrect frame alignment, and error performance monitoring using CRC; Frame alignment loss check; 1 ms information; 1 second information

Recommendation G.706 | 7

FIGURE 2/G.706
Procedure to be followed in passing from the frame alignment search to error monitoring using a cyclic redundancy check (CRC) (2048 kbit/s)
4.3.3 | Error performance monitoring using CRC-4 (see § A.1.2)
| Information on the status of the CRC processing should be made available in two forms:
a) Direct information
| Every time a CRC block is detected in error, it will be necessary to indicate this condition.
b) Integrated information
| In consecutive 1 second periods, the number of errored CRC blocks should be made available. This number will be in the range 0 to 1000 (decimal).

### 5 Frame alignment and CRC procedures at 8448 kbit/s interface

For further study.

### 8 Recommendation G.706

ANNEX A

(to Recommendation G.706)

Background information on the use of cyclic redundancy check (CRC) procedures

A.1 | Reasons for application of CRC
| CRC procedures can be used for both protection against false frame alignment and for bit error monitoring.
A.1.1 | Protection against false frame alignment
| The CRC procedures are used to protect against false frame alignment of receivers of multiplex signals. For
example, false frame alignment could occur in an ISDN if a user imitates a frame alignment signal in his non-voice terminal. However, since a user is not controlling the composition of a multiplex frame, the addition of CRC bits, and evaluation of these bits in the receiver, leads to detection of the false frame alignment.
A.1.2 | Bit error monitoring
| The CRC procedure is also used for improved bit error ratio monitoring if low values of error ratio (e.g. 10⁻⁶)
are to be considered. CRC monitoring (like monitoring of the frame alignment signal) takes account of the entire digital link between the source and sink of a multiplex signal, as opposed to code violation monitoring (e.g. monitoring of AMI, HDB3 or B8ZS violations) which concerns only the digital line section nearest to the receiver, or in many cases only an interface line [e.g. between a digital multiplexer and an exchange terminal (ET)].
A.2 | Limitations of CRC procedures
A.2.1 | Probability of undetected bit errors
| It can be estimated [1] that for CRC-n, and long message/check blocks, the probability that an error remains
undetected approaches 2⁻n even with a high bit error ratio; with a low bit error ratio, the probability is lower. The resulting inaccuracy (at most, with CRC-4, about 6% of blocks with undetected errors; similarly, with CRC-6, 1.6%) is tolerable for the required purpose.
A.2.2 | Limitation of application to bit error ratio measurement
| The CRC monitoring procedure is not well suited to measure values of bit error ratio that are so high that on
average every message/check block contains at least one bit error (i.e. for BER = 10⁻³ or higher).

Recommendation G.706 | 9

ANNEX B

(to Recommendation G.706)

Modified CRC-4 multiframe alignment algorithm to allow automatic interworking between equipments with and without a CRC-4 capability

B.1 General

Situations are envisaged when it may be necessary to allow automatic interworking between equipments with and without CRC-4 capability, e.g. in a switched/managed 2048 kbit/s network. Two methods of achieving automatic interworking are:

– | method 1: Using a “lower-layer” approach based on a modified CRC-4 multiframe alignment algorithm.
– | method 2: Using a "higher-layer" approach based on remote control via a network management facility.

This annex details an implementation using method 1. Method 2 is for further study.

B.2 | Modified CRC-4 multiframe alignment algorithm
B.2.1 | Overview of algorithm
| The modified CRC-4 multiframe alignment algorithm is based on the following strategy:
| If a valid basic frame alignment signal is consistently present but CRC-4 multiframe alignment is not achieved
by the end of the total CRC-4 multiframe alignment search period, it is assumed that the distant end is a Non-CRC-4 equipment.
B.2.2 | Consequent actions for CRC-4-to-Non-CRC-4 equipment interworking
| Under these circumstances, the following consequent actions apply at the equipment having the CRC-4
capability:
a) provide an indication (not necessarily an alarm) that there is “no incoming CRC-4 multiframe alignment
| signal”;
b) inhibit CRC-4 processing on the receive 2048 kbit/s signal;
c) continue to transmit CRC-4 data to the distant end with both “E” bits (see Table 4b/G.704) set to zero.
| Note – This allows, as explained in § B.2.5, the identification of failure of CRC-4 multiframe alignment
generation/detection, but with correct basic framing, when interworking between equipments each having the modified CRC-4 multiframe alignment algorithm.
| The algorithm is robust against spurious basic frame alignment and there are no interworking problems with
equipment having a manually selectable CRC-4 capability.

### 10 Recommendation G.706

B.2.3 | Details of the alignment algorithm
| Figure B-1/G.706 depicts a block-schematic flow diagram of the alignment algorithm.
| A 400 ms CRC-4 multiframe alignment search period ensures that correct basic and CRC-4 multiframe
alignment is possible for up to about 40 spurious simulations of the basic frame alignment sequence present between two real basic frame alignment signal locations.
| The 400 ms timer is triggered on the initial (i.e. primary) recovery of basic frame alignment. Once the 400 ms
timer is triggered, it is not reset unless the criteria for “loss of (primary) basic frame alignment” occurs (see § 4.1.1): The “loss of (primary) basic frame alignment” checking process runs continuously irrespective of the state of the CRC-4 multiframe alignment process below it.
| A research for basic frame alignment initiated if CRC-4 multiframe alignment cannot be achieved in 8 ms (as
required in § 4.2) should not reset the 400 ms timer or invoke consequent actions associated with loss of primary basic frame alignment, that is, in this particular section of the alignment flow diagram, all searches for basic frame alignment are carried out in parallel with, and hence independent of, the primary basic frame loss checking process (see Figure B-1/G.706). All subsequent searches for CRC-4 multiframe alignment are associated with each basic framing sequence found during the parallel search.
| In order that the algorithm does not introduce a disturbance (of 400 ms maximum duration) to traffic during
the search for CRC-4 multiframe alignment, traffic should be allowed through upon, and synchronized to, the initially determined primary basic frame alignment sequence.
| If a CRC-4 multiframe alignment signal is found before the 400 ms timer elapses, then the basic frame
alignment sequence associated with the CRC-4 multiframe alignment signal should be the one chosen, i.e. if necessary, the primary basic frame alignment position should be amended accordingly. CRC-4 processing would then determine if this was truly the valid alignment location (in accordance with § 4.3.2). However, if a CRC-4 multiframe alignment sequence cannot be found before the 400 ms timer elapses, it should be concluded that a condition of interworking between equipments with and without a CRC-4 capability exists; in this case traffic should be maintained to the initially determined primary basic frame alignment signal location and the consequent actions given in § B.2.2 invoked.
| If the 2048 kbit/s path is reconfigured at any time, then it is assumed that the (new) pair of path terminating
equipments will need to re-establish the complete framing process, i.e. the algorithm is reset.

B.2.4 Setting of the “E” bits during and after alignment

CRC-4 equipment using the modified CRC-4 multiframe alignment algorithm should always set the return CRC-4 data in the E bits to zero until the equipment interworking relationship has been established at the end of the complete framing sequence. At this time the following consequent actions should apply:

– If CRC-4-to-CRC-4 equipment interworking is established, then normal CRC-4 processing of errored CRC-4 block data should commence, e.g. setting the E bits in accordance with Recommendation G.704, § 2.3.3.4.

– If CRC-4-to-Non-CRC-4 equipment interworking is established, the E bits should remain at 0 (this being of no consequence to the Non-CRC-4 equipment).

Recommendation G.706 | 11
B.2.5 | Detection of CRC-4 multiframe generator/detector failure (basic framing correct) in equipments using the modified CRC-4 multiframe algorithm
| The reception of a permanent state of E bits set to 0 signifies that the distant equipment is unable to achieve
CRC-4 multiframe alignment.
| Note – If the A (remote alarm indication (RAI)) bit is not set to 1 in TS0 then the distant end is assumed to
have achieved basic frame alignment.
| The inability to gain CRC-4 multiframe alignment at the distant end should not result in an alarm at the distant
end, but only an indication of the condition. It would then be up to maintenance personnel at the local and distant ends to identify if the CRC-4 multiframe alignment generator or detector had failed.
| The integration period and threshold value for determining this failure mode should be a count of more
than 990 errored CRC-4 blocks, as determined from the E bit data, in each second (i.e. out of a 1000 CRC-4 check blocks) for five consecutive seconds. These values have been chosen since they are almost inconceivable as a result of any error distribution which did cause some other effect, e.g. either local loss of frame alignment, or distant loss of frame alignment signified by the reception of the A (RAI) bit set in TS0.

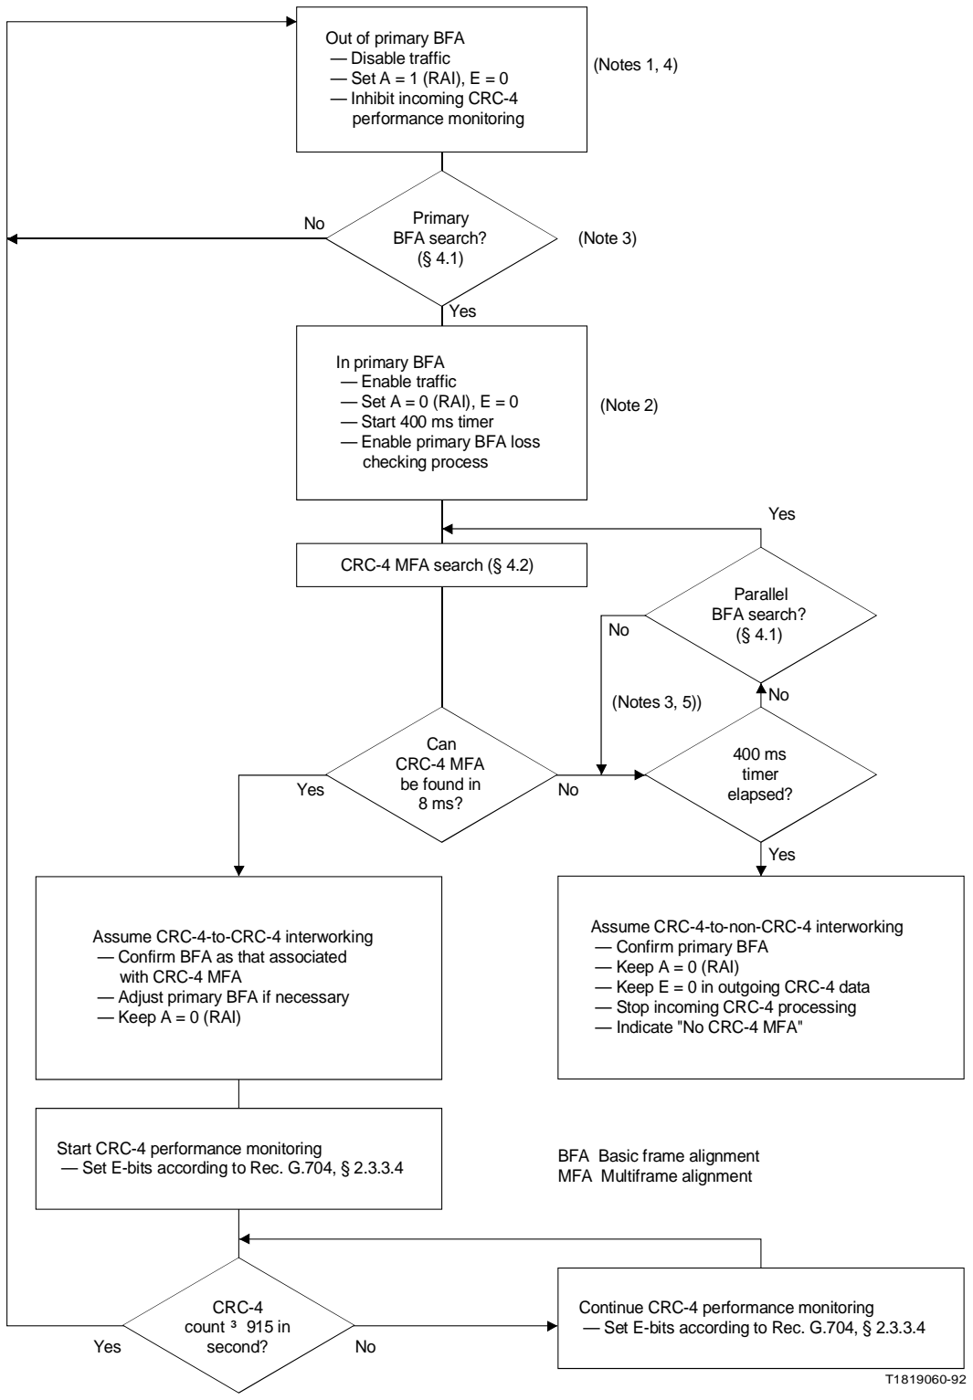
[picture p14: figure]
Out of primary BFA — Disable traffic — Set A = 1 (RAI), E = 0 — Inhibit incoming CRC-4 performance monitoring; In primary BFA — Enable traffic — Set A = 0 (RAI), E = 0 — Start 400 ms timer — Enable primary BFA loss checking process; CRC-4 MFA search (§ 4.2); Parallel BFA search? (§ 4.1); 400 ms timer elapsed?; Assume CRC-4-to-non-CRC-4 interworking — Confirm primary BFA — Keep A = 0 (RAI) — Keep E = 0 in outgoing CRC-4 data — Stop incoming CRC-4 processing — Indicate "No CRC-4 MFA"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

### 12 Recommendation G.706

— Set E-bits according to Rec. G.704, § 2.3.3.4

— Set E-bits according to Rec. G.704, § 2.3.3.4

FIGURE B-1/G.706
Block schematic framing algorithm for automatic, CRC-4/Non-CRC-4 equipment interworking

Recommendation G.706 | 13

Notes to Figure B-1/G.706

Note 1 – Until primary basic frame alignment is established the A (RAI) bit should be set to one and the E bits set to zero. When primary basic frame alignment is established, both the A (RAI) and E bits should be set to zero.

If CRC-4 multiframe alignment is subsequently achieved within the 400 ms search window, primary basic frame alignment should be confirmed to that associated with the CRC-4 multiframe alignment position. CRC-4 performance monitoring should then start (see §
4.3.1) with the E bits set in accordance with Recommendation G.704 § 2.3.3.4. If however, CRC-4 multiframe alignment cannot be achieved within the 400 ms search window but a state of primary basic frame alignment has been consistently present, then incoming CRC-4 processing should remain inhibited and both the A (RAI) and E bits should remain set to zero. The information provided by the A and E bits (taken together) allows the possibility of identifying failure of the CRC-4 multiframe alignment signal generator/receiver when primary basic frame alignment is consistently present (see § B.2.5).

Note 2 – Once the initial primary basic frame alignment is established, a primary basic frame alignment loss checking process is enabled; this now runs continuously as a background process, i.e. a loss of primary basic frame alignment at any time should reset the algorithm.

In practice the 400 ms timer could be a suitably calibrated counter.

Note 3 – As already observed in Note 1 to §§ 4.2 and 4.3.2, during any search for parallel basic frame alignment, the search should commence at a point just after any previous alignment position. When taken in conjunction with the 400 ms timer, the strategy can avoid about 40 independent spurious framing sequences between true framing sequences.

Note 4 – It is assumed that any reconfiguration of the 2048 kbit/s path (e.g. due to a management request in a switched 2048 kbit/s network) results in a loss of primary basic framing between the (new) pair of path termination equipments, i.e. the algorithm is completely reset.

Note 5 – It is not considered necessary to associate a “time-out” with each parallel basic frame alignment search since:

– it is intended that the 400 ms timer be continuously referenced during the parallel basic frame alignment search, such that if the 400 ms timer elapses the parallel basic frame alignment search terminates and the state of “CRC-4 to Non-CRC-4 interworking” is entered;

– in practice, even if no spurious simulations of the basic frame alignment are present, it is likely that a parallel basic frame alignment search state will be entered/exited several times during the 400 ms CRC-4 multiframe alignment search window due to the parallel search repeatedly discovering the primary basic frame alignment position.

ANNEX C

(to Recommendation G.706)

CRC-4 checksum updating procedure at intermediate path points in a message-based data-link application

C.1 General

The Sa4 bit may be used as a message-based data-link within 2048 kbit/s paths (see Note 4 to Table 4a/G.704). Situations are envisaged where access to this data-link could be required at points on the path between the true path termination points, e.g. reporting of error performance data from intermediate sites along the path. In such situations it is important that the logical path termination role of CRC-4 is not invalidated or impaired. Hence, any changes to the Sa4 bits within a SMF at an intermediate path point does not imply a recalculation of the CRC-4 bits over the whole SMF, but rather their update as a linear re-coding function in respect of specific deterministic binary changes of the Sa4 bits only.

This annex gives:

– | a mathematical proof of the validity of the updating procedure, and
– | an example of the conceptual basis for implementation – including the principle by which the updating
procedure can be extended, if required, to include all the spare bits, i.e. Sa4 to Sa8.

### 14 Recommendation G.706

C.2 Mathematical proof of validity of updating procedure

The complete bit pattern of a SMF can be represented as a data polynomial, D(x), of degree 2047 in x by:

D(x) = a2047x²⁰⁴⁷ + a2046x²⁰⁴⁶ + . . . + a2x² + a1x¹ + a0 | (C-1)

where

ai = 0 or 1, and the degree of x represents the bit position within the SMF.

The CRC-4 checksum for D(x) is the remainder, R(x), resulting from the modulo 2 division of x⁴D(x) by the CRC-4 generator polynomial G(x), that is

x⁴D(x)/G(x) = Q(x) + R(x)/G(x) | (C-2)

where

G(x) = x⁴ + x + 1

Q(x) = Quotient polynomial, having the same degree as D(x)

The polynomial representation of the Sa4 bit positions of the SMF is a specific form of equation (C-1), viz:

Sa4(x) = a1788x¹⁷⁸⁸ + a1276x¹²⁷⁶ + a764x⁷⁶⁴ + a252x²⁵² | (C-3)

If we let the polynomial Sa4 diff (x) represent the desired changes in the Sa4 bit positions of the SMF, then:

Dnew(x) = D(x) + Sa4 diff (x) | (C-4)

That is, Sa4 diff (x) has “1s” only in the positions where the “new” Sa4 bit does not match that already present in D(x).

Applying the general form of equation (C-2) to equation (C-4), we get:

=> x⁴Dnew(x)/G(x) = Qnew(x) + Rnew(x)/G(x)

=> x⁴{D(x) + Sa4 diff (x)}/G(x) = Qnew(x) + Rnew(x)/G(x)

=> x⁴D(x)/G(x) + x⁴Sa4 diff (x)/G(x) = Qnew(x) + Rnew(x)/G(x)

=> Q(x) + R(x)/G(x) + Qdiff (x) + Rdiff (x)/G(x) = Qnew(x) + Rnew(x)/G(x) | (C-5)

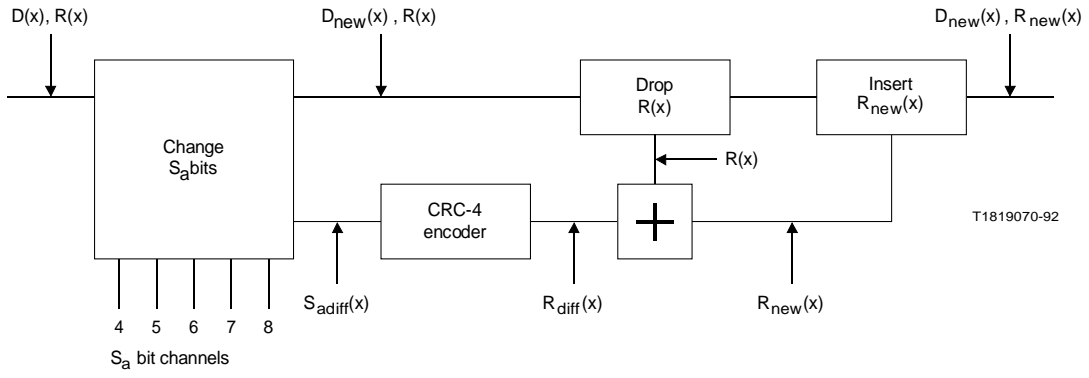
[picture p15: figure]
Sa bit channels; Change S bits a; Drop R(x); CRC-4 encoder; , R(x) Dnew(x); , R new(x) Dnew(x); Insert Rnew(x); Rnew(x) diff S; (x) adiff(x)

Recommendation G.706 | 15

Rearranging and collecting like-terms in equation (C-5) yields:

{Q(x) + Qdiff} + {R(x) + Rdiff (x)}/G(x) = Qnew(x) + Rnew(x)/G(x) | (C-6)

Equation (C-6) shows that the required (i.e. updated) CRC-4 checksum, Rnew(x), is simply the modulo 2 sum of the original CRC-4 checksum, R(x), and the remainder, Rdiff (x), from applying the CRC-4 encoding process to the polynomial representation of the desired Sa4 bit changes in the SMF. That is:

Rnew(x) = R(x) + Rdiff (x) | (C-7)

Note that the above process is based only on deterministic changes to the bit structure of D(x), i.e. the SMF. Any errors present in D(x) or its associated CRC-4 checksum, R(x), are not known to the updating process. Hence, the true end-to-end path error detection property of the CRC-4 procedure is preserved.

Clearly the updating process can be applied to any deterministic changes to the bit structure of D(x), e.g. the other Sa bits.

C.3 | An example of a conceptual basis for implementing the updating process
| Figure C-1/G.706 shows a conceptual basis for implementing the CRC-4 updating process which takes any
combination of the Sa bits into account; the example is not intended to constrain actual methods of practical implementation.

FIGURE C-1/G.706
Example of conceptual implementation of CRC-4 updating process

### 16 Recommendation G.706

ANNEX D
(to Recommendation G.706)

Alphabetical list of abbreviations used in this Recommendation

BFA | Basic frame alignment
CMB | CRC message bloc
CRC | Cyclic redundancy check
ET | Exchange terminal
MFA | Multiframe alignment
RAI | Remote alarm indication
SMF | Sub-multiframe

Bibliography

[1] LEUNG (C.) and WITZKE (K.A).: A comparison of some error detecting CRC code standards, IEEE Trans., Vol. COM-33, pp. 996-998, 1985.

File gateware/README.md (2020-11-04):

E1 related gateware
===================

This directory contains the iCE40 gateware for various boards hosted
in this repository.

Licensing
---------

Most of the cores/HDL in here is licensed under one of the CERN OHL 2.0
license. See the `doc/` subdirectory for the full license texts and refer
to each file header to know the license applicable to each file.

Some files have been imported from other projects with compatible licenses.
Refer to each file header for the proper copyright and license information.

The repository also includes submodules which have their own licensing
and copyright terms.

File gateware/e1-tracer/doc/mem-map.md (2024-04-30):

e1-tracer SoC Memory Map
========================

Overview
--------

| Base | Size | Description | IP Core doc
|---|---|---|---
|`0x00000000` | `0x00400` (1k) | Boot ROM |
|`0x00020000` | `0x10000` (64k)  | Main SRAM |
|`0x80000000` | | Flash SPI | [`no2ice40/ice40_spi_wb`](../../cores/no2ice40/doc/ice40_spi_wb.md)
|`0x81000000` | | Debug UART | [`no2misc/uart_wb`](../../cores/no2misc/doc/uart_wb.md)
|`0x82000000` | | RGB LED | [`no2ice40/ice40_rgb_wb`](../../cores/no2ice40/doc/ice40_rgb_wb.md)
|`0x83000000` | | USB core | [`no2usb`](../../cores/no2usb/doc/mem-map.md)
|`0x84000000` | `0x01000` (4k) | USB data buffer |
|`0x85000000` | `0x10000` (64k)  | E1 data buffer  |
|`0x86000000` | | DMA | See below
|`0x87000000` | | E1 core | [`no2e1`](../../cores/no2e1/doc/mem-map.md). See notes below.
|`0x88000000` | | Misc | See below
|`0x89000000` | | LIU SPI | [`no2ice40/ice40_spi_wb`](../../cores/no2ice40/doc/ice40_spi_wb.md)

Memory
------

### `0x00000000`: Boot ROM

This memory zone is initialized directly in the FPGA bitstream itself.
It contains the bootstrap program that will load the main firmware from
flash into the main SRAM and jump to it.

### `0x00020000`: Main SRAM

The main SoC SRAM, implemented using the UP5k SPRAMs. It can't be initialized
in the FPGA bitstream directly, hence the need for the Boot ROM zone.

### `0x84000000`: USB data buffer

This 4k zone actually correspond to 8k of SRAM inside the USB core.
The RX and TX buffer for the USB are distinct and are accessed independently
depending if read or write access are made to this zone. (RX buffer can only
be read, TX buffer can only be written). All accesses must also be 32 bit
wide !

### `0x85000000`: E1 data buffer

This 64k buffer is reserved for E1 data and is what is used by the E1 core.

Address mapping is :

```text
,---------------------------------------------------------------,
| f | e | d | c | b | a | 9 | 8 | 7 | 6 | 5 | 4 | 3 | 2 | 1 | 0 |
|---------------------------------------------------------------|
|        multi-frame        |     frame     |    timeslot       |
'---------------------------------------------------------------'
```

and the `multi-frame` number is what is exchanged in the E1 core buffer
descriptors.

Custom Peripherals
------------------

### `0x86000000`: DMA

Very simple DMA core allowing direct copy of data between the USB and E1 data
buffers.

#### Status (Read Only, addr `0x00`)

```text
,-----------------------------------------------------------------------------------------------,
|31|30|29|28|27|26|25|24|23|22|21|20|19|18|17|16|15|14|13|12|11|10| 9| 8| 7| 6| 5| 4| 3| 2| 1| 0|
|-----------------------------------------------------------------------------------------------|
|                             /                 | b| d| /|               len                    |
'-----------------------------------------------------------------------------------------------'

 * [   15] - b   : Busy flag
 * [   14] - d   : Direction ( 0=E1 to USB, 1=USB to E1 )
 * [12: 0] - len : Remaining length of the in-progress transfer ( -1 = done )
```

#### Transfer start/direction/length (Write Only, addr `0x00`)

Write to this register initiate the transfer.

```text
,-----------------------------------------------------------------------------------------------,
|31|30|29|28|27|26|25|24|23|22|21|20|19|18|17|16|15|14|13|12|11|10| 9| 8| 7| 6| 5| 4| 3| 2| 1| 0|
|-----------------------------------------------------------------------------------------------|
|                             /                    | d|  /  |             len                   |
'-----------------------------------------------------------------------------------------------'

 * [   14] - d   : Direction ( 0=E1 to USB, 1=USB to E1 )
 * [11: 0] - len : Transfer length ( Number of Words - 2 )
```

#### E1 buffer offset (Write Only, addr `0x08`)

```text
,-----------------------------------------------------------------------------------------------,
|31|30|29|28|27|26|25|24|23|22|21|20|19|18|17|16|15|14|13|12|11|10| 9| 8| 7| 6| 5| 4| 3| 2| 1| 0|
|-----------------------------------------------------------------------------------------------|
|                     /                               |           e1_ofs                        |
'-----------------------------------------------------------------------------------------------'

 * [13:0] - e1_ofs
```

Word offset inside the E1 data buffer where the next transfer will start

#### USB buffer offset (Write Only, addr `0x0C`)

```text
,-----------------------------------------------------------------------------------------------,
|31|30|29|28|27|26|25|24|23|22|21|20|19|18|17|16|15|14|13|12|11|10| 9| 8| 7| 6| 5| 4| 3| 2| 1| 0|
|-----------------------------------------------------------------------------------------------|
|                              /                                  |        usb_ofs              |
'-----------------------------------------------------------------------------------------------'

 * [9:0] - usb_ofs
```

Word offset inside the USB End Point buffer where the next transfer will start

### `0x87000000`: E1 core

Refer to the [`no2e1` core documentation](../../cores/no2e1/doc/mem-map.md)
for register description.

The core instanciated here has a 2 channels with only RX units present.

### `0x88000000`: Misc

Collection of small auxiliary peripherals.

#### Boot (Write Only, addr `0x00`)

```text
,-----------------------------------------------------------------------------------------------,
|31|30|29|28|27|26|25|24|23|22|21|20|19|18|17|16|15|14|13|12|11|10| 9| 8| 7| 6| 5| 4| 3| 2| 1| 0|
|-----------------------------------------------------------------------------------------------|
|                                         /                                            | x| sel |
'-----------------------------------------------------------------------------------------------'

 * [   2] - d   : boot eXecute
 * [11:0] - sel : boot select
```

Write to this register with bit 2 set will trigger a FPGA reload of the selected image.

#### E1 tick source select (Write Only, addr `0x04`)

```text
,-----------------------------------------------------------------------------------------------,
|31|30|29|28|27|26|25|24|23|22|21|20|19|18|17|16|15|14|13|12|11|10| 9| 8| 7| 6| 5| 4| 3| 2| 1| 0|
|-----------------------------------------------------------------------------------------------|
|                     /                   |ts[1]|                   /                     |ts[0]|
'-----------------------------------------------------------------------------------------------'

 * [17:16] - ts[1] : Tick Source for channel 1
 * [ 1: 0] - ts[0] : Tick Source for channel 0
```

Selects the tick source for the counters below for each E1 channel.
Available sources are :

* `0`: (reserved)
* `1`: (reserved)
* `2`: RX Sample, for every bit received
* `3`: RX One, for every `1` bit received

#### E1 tick counters (Read Only, addr `0x04`)

```text
,-----------------------------------------------------------------------------------------------,
|31|30|29|28|27|26|25|24|23|22|21|20|19|18|17|16|15|14|13|12|11|10| 9| 8| 7| 6| 5| 4| 3| 2| 1| 0|
|-----------------------------------------------------------------------------------------------|
|                  chan[1]                      |                   chan[0]                     |
'-----------------------------------------------------------------------------------------------'

 * [31:16] - chan[1] : Tick counter for channel 1
 * [15: 0] - chan[0] : Tick counter for channel 0
```

An internal counter is incremented at every E1 tick (tick source selected above) for each E1
channel. That counter value is then captured at every USB Start-of-Frame packet and the last
captured value made available here.

#### Time (Read Only, addr `0x07`)

```text
,-----------------------------------------------------------------------------------------------,
|31|30|29|28|27|26|25|24|23|22|21|20|19|18|17|16|15|14|13|12|11|10| 9| 8| 7| 6| 5| 4| 3| 2| 1| 0|
|-----------------------------------------------------------------------------------------------|
|                                             time                                              |
'-----------------------------------------------------------------------------------------------'

 * [31:0] - time
```

32 bit counter incremented at the system clock rate ( 24 MHz )

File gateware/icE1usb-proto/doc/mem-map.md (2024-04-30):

icE1usb-proto SoC Memory Map
============================

Overview
--------

| Base | Size | Description | IP Core doc
|---|---|---|---
|`0x00000000` | `0x00400` (1k) | Boot ROM |
|`0x00020000` | `0x10000` (64k)  | Main SRAM |
|`0x80000000` | | Flash SPI | [`no2ice40/ice40_spi_wb`](../../cores/no2ice40/doc/ice40_spi_wb.md)
|`0x81000000` | | Debug UART | [`no2misc/uart_wb`](../../cores/no2misc/doc/uart_wb.md)
|`0x82000000` | | RGB LED | [`no2ice40/ice40_rgb_wb`](../../cores/no2ice40/doc/ice40_rgb_wb.md)
|`0x83000000` | | USB core | [`no2usb`](../../cores/no2usb/doc/mem-map.md)
|`0x84000000` | `0x01000` (4k) | USB data buffer |
|`0x85000000` | `0x10000` (64k)  | E1 data buffer  |
|`0x86000000` | | DMA | See below
|`0x87000000` | | E1 core | [`no2e1`](../../cores/no2e1/doc/mem-map.md). See notes below.
|`0x88000000` | | Misc | See below

Memory
------

### `0x00000000`: Boot ROM

This memory zone is initialized directly in the FPGA bitstream itself.
It contains the bootstrap program that will load the main firmware from
flash into the main SRAM and jump to it.

### `0x00020000`: Main SRAM

The main SoC SRAM, implemented using the UP5k SPRAMs. It can't be initialized
in the FPGA bitstream directly, hence the need for the Boot ROM zone.

### `0x84000000`: USB data buffer

This 4k zone actually correspond to 8k of SRAM inside the USB core.
The RX and TX buffer for the USB are distinct and are accessed independently
depending if read or write access are made to this zone. (RX buffer can only
be read, TX buffer can only be written). All accesses must also be 32 bit
wide !

### `0x85000000`: E1 data buffer

This 64k buffer is reserved for E1 data and is what is used by the E1 core.

Address mapping is :

```text
,---------------------------------------------------------------,
| f | e | d | c | b | a | 9 | 8 | 7 | 6 | 5 | 4 | 3 | 2 | 1 | 0 |
|---------------------------------------------------------------|
|        multi-frame        |     frame     |    timeslot       |
'---------------------------------------------------------------'
```

and the `multi-frame` number is what is exchanged in the E1 core buffer
descriptors.

Custom Peripherals
------------------

### `0x86000000`: DMA

Very simple DMA core allowing direct copy of data between the USB and E1 data
buffers.

#### Status (Read Only, addr `0x00`)

```text
,-----------------------------------------------------------------------------------------------,
|31|30|29|28|27|26|25|24|23|22|21|20|19|18|17|16|15|14|13|12|11|10| 9| 8| 7| 6| 5| 4| 3| 2| 1| 0|
|-----------------------------------------------------------------------------------------------|
|                             /                 | b| d| /|               len                    |
'-----------------------------------------------------------------------------------------------'

 * [   15] - b   : Busy flag
 * [   14] - d   : Direction ( 0=E1 to USB, 1=USB to E1 )
 * [12: 0] - len : Remaining length of the in-progress transfer ( -1 = done )
```

#### Transfer start/direction/length (Write Only, addr `0x00`)

Write to this register initiate the transfer.

```text
,-----------------------------------------------------------------------------------------------,
|31|30|29|28|27|26|25|24|23|22|21|20|19|18|17|16|15|14|13|12|11|10| 9| 8| 7| 6| 5| 4| 3| 2| 1| 0|
|-----------------------------------------------------------------------------------------------|
|                             /                    | d|  /  |             len                   |
'-----------------------------------------------------------------------------------------------'

 * [   14] - d   : Direction ( 0=E1 to USB, 1=USB to E1 )
 * [11: 0] - len : Transfer length ( Number of Words - 2 )
```

#### E1 buffer offset (Write Only, addr `0x08`)

```text
,-----------------------------------------------------------------------------------------------,
|31|30|29|28|27|26|25|24|23|22|21|20|19|18|17|16|15|14|13|12|11|10| 9| 8| 7| 6| 5| 4| 3| 2| 1| 0|
|-----------------------------------------------------------------------------------------------|
|                     /                               |           e1_ofs                        |
'-----------------------------------------------------------------------------------------------'

 * [13:0] - e1_ofs
```

Word offset inside the E1 data buffer where the next transfer will start

#### USB buffer offset (Write Only, addr `0x0C`)

```text
,-----------------------------------------------------------------------------------------------,
|31|30|29|28|27|26|25|24|23|22|21|20|19|18|17|16|15|14|13|12|11|10| 9| 8| 7| 6| 5| 4| 3| 2| 1| 0|
|-----------------------------------------------------------------------------------------------|
|                              /                                  |        usb_ofs              |
'-----------------------------------------------------------------------------------------------'

 * [9:0] - usb_ofs
```

Word offset inside the USB End Point buffer where the next transfer will start

### `0x87000000`: E1 core

Refer to the [`no2e1` core documentation](../../cores/no2e1/doc/mem-map.md)
for register description.

The core instanciated here has a 1 single channel containing both
RX and TX units.

### `0x88000000`: Misc

Collection of small auxiliary peripherals.

#### Boot (Write Only, addr `0x00`)

```text
,-----------------------------------------------------------------------------------------------,
|31|30|29|28|27|26|25|24|23|22|21|20|19|18|17|16|15|14|13|12|11|10| 9| 8| 7| 6| 5| 4| 3| 2| 1| 0|
|-----------------------------------------------------------------------------------------------|
|                                         /                                            | x| sel |
'-----------------------------------------------------------------------------------------------'

 * [   2] - d   : boot eXecute
 * [11:0] - sel : boot select
```

Write to this register with bit 2 set will trigger a FPGA reload of the selected image.

#### E1 tick source select (Write Only, addr `0x04`)

```text
,-----------------------------------------------------------------------------------------------,
|31|30|29|28|27|26|25|24|23|22|21|20|19|18|17|16|15|14|13|12|11|10| 9| 8| 7| 6| 5| 4| 3| 2| 1| 0|
|-----------------------------------------------------------------------------------------------|
|                                        /                                                | tss |
'-----------------------------------------------------------------------------------------------'

 * [ 1: 0] - tss : Tick Source Select
```

Selects the tick source for the counters below.
Available sources are :

* `0`: TX tick, for every bit sent
* `1`: RX Pulse, for every detected pulse on the input
* `2`: RX Sample, for every bit received
* `3`: RX One, for every `1` bit received

#### E1 tick counters (Read Only, addr `0x04`)

```text
,-----------------------------------------------------------------------------------------------,
|31|30|29|28|27|26|25|24|23|22|21|20|19|18|17|16|15|14|13|12|11|10| 9| 8| 7| 6| 5| 4| 3| 2| 1| 0|
|-----------------------------------------------------------------------------------------------|
|                     /                         |                   tick_cnt                    |
'-----------------------------------------------------------------------------------------------'

 * [15: 0] - tick_cnt : Tick counter value
```

An internal counter is incremented at every E1 tick (tick source selected above) for each E1
channel. That counter value is then captured at every USB Start-of-Frame packet and the last
captured value made available here.

#### Time (Read Only, addr `0x07`)

```text
,-----------------------------------------------------------------------------------------------,
|31|30|29|28|27|26|25|24|23|22|21|20|19|18|17|16|15|14|13|12|11|10| 9| 8| 7| 6| 5| 4| 3| 2| 1| 0|
|-----------------------------------------------------------------------------------------------|
|                                             time                                              |
'-----------------------------------------------------------------------------------------------'

 * [31:0] - time
```

32 bit counter incremented at the system clock rate ( 30.72 MHz )

#### PDM (Write Only, addr `0x08-0x0f`)

This exposes configurable voltages ( DACs ). Some channels are 12 bits, some are 8 bits.

```text
12 bits:

,-----------------------------------------------------------------------------------------------,
|31|30|29|28|27|26|25|24|23|22|21|20|19|18|17|16|15|14|13|12|11|10| 9| 8| 7| 6| 5| 4| 3| 2| 1| 0|
|-----------------------------------------------------------------------------------------------|
|en|                        /                               |            value                  |
'-----------------------------------------------------------------------------------------------'

 * [31  ] - enable (output tristated if 0)
 * [11:0] - value

 8 bits:

,-----------------------------------------------------------------------------------------------,
|31|30|29|28|27|26|25|24|23|22|21|20|19|18|17|16|15|14|13|12|11|10| 9| 8| 7| 6| 5| 4| 3| 2| 1| 0|
|-----------------------------------------------------------------------------------------------|
|en|                               /                                    |      value            |
'-----------------------------------------------------------------------------------------------'

 * [31  ] - enable (output tristated if 0)
 * [11:0] - value
```

Channels :

  * `0`: Clock tune ( low ) [ 12 bits ]
  * `1`: Clock tune ( high ) [ 12 bits ]
  * `2`: E1 RX Negative bias [ 8 bits ]
  * `3`: E1 RX Positive bias [ 8 bits ]
  * `4`: E1 RX Center Tap bias [ 8 bits ]

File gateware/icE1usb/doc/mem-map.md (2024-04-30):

icE1usb-proto SoC Memory Map
============================

Overview
--------

| Base | Size | Description | IP Core doc
|---|---|---|---
|`0x00000000` | `0x00400` (1k) | Boot ROM |
|`0x00020000` | `0x10000` (64k)  | Main SRAM |
|`0x80000000` | | Flash SPI | [`no2ice40/ice40_spi_wb`](../../cores/no2ice40/doc/ice40_spi_wb.md)
|`0x81000000` | | Debug UART | [`no2misc/uart_wb`](../../cores/no2misc/doc/uart_wb.md)
|`0x82000000` | | RGB LED | [`no2ice40/ice40_rgb_wb`](../../cores/no2ice40/doc/ice40_rgb_wb.md)
|`0x83000000` | | USB core | [`no2usb`](../../cores/no2usb/doc/mem-map.md)
|`0x84000000` | `0x01000` (4k) | USB data buffer |
|`0x85000000` | `0x10000` (64k)  | E1 data buffer  |
|`0x86000000` | | DMA | See below
|`0x87000000` | | E1 core | [`no2e1`](../../cores/no2e1/doc/mem-map.md). See notes below.
|`0x88000000` | | Misc | See below
|`0x89000000` | | GPS UART | [`no2misc/uart_wb`](../../cores/no2misc/doc/uart_wb.md)
|`0x8a000000` | | I2C (\*) | See below
|`0x8a000000` | | I2C (\*) | [`no2ice40/ice40_i2c_wb`](../../cores/no2ice40/doc/ice40_i2c_wb.md)

Memory
------

### `0x00000000`: Boot ROM

This memory zone is initialized directly in the FPGA bitstream itself.
It contains the bootstrap program that will load the main firmware from
flash into the main SRAM and jump to it.

### `0x00020000`: Main SRAM

The main SoC SRAM, implemented using the UP5k SPRAMs. It can't be initialized
in the FPGA bitstream directly, hence the need for the Boot ROM zone.

### `0x84000000`: USB data buffer

This 4k zone actually correspond to 8k of SRAM inside the USB core.
The RX and TX buffer for the USB are distinct and are accessed independently
depending if read or write access are made to this zone. (RX buffer can only
be read, TX buffer can only be written). All accesses must also be 32 bit
wide !

### `0x85000000`: E1 data buffer

This 64k buffer is reserved for E1 data and is what is used by the E1 core.

Address mapping is :

```text
,---------------------------------------------------------------,
| f | e | d | c | b | a | 9 | 8 | 7 | 6 | 5 | 4 | 3 | 2 | 1 | 0 |
|---------------------------------------------------------------|
|        multi-frame        |     frame     |    timeslot       |
'---------------------------------------------------------------'
```

and the `multi-frame` number is what is exchanged in the E1 core buffer
descriptors.

Custom Peripherals
------------------

### `0x86000000`: DMA

Very simple DMA core allowing direct copy of data between the USB and E1 data
buffers.

#### Status (Read Only, addr `0x00`)

```text
,-----------------------------------------------------------------------------------------------,
|31|30|29|28|27|26|25|24|23|22|21|20|19|18|17|16|15|14|13|12|11|10| 9| 8| 7| 6| 5| 4| 3| 2| 1| 0|
|-----------------------------------------------------------------------------------------------|
|                             /                 | b| d| /|               len                    |
'-----------------------------------------------------------------------------------------------'

 * [   15] - b   : Busy flag
 * [   14] - d   : Direction ( 0=E1 to USB, 1=USB to E1 )
 * [12: 0] - len : Remaining length of the in-progress transfer ( -1 = done )
```

#### Transfer start/direction/length (Write Only, addr `0x00`)

Write to this register initiate the transfer.

```text
,-----------------------------------------------------------------------------------------------,
|31|30|29|28|27|26|25|24|23|22|21|20|19|18|17|16|15|14|13|12|11|10| 9| 8| 7| 6| 5| 4| 3| 2| 1| 0|
|-----------------------------------------------------------------------------------------------|
|                             /                    | d|  /  |             len                   |
'-----------------------------------------------------------------------------------------------'

 * [   14] - d   : Direction ( 0=E1 to USB, 1=USB to E1 )
 * [11: 0] - len : Transfer length ( Number of Words - 2 )
```

#### E1 buffer offset (Write Only, addr `0x08`)

```text
,-----------------------------------------------------------------------------------------------,
|31|30|29|28|27|26|25|24|23|22|21|20|19|18|17|16|15|14|13|12|11|10| 9| 8| 7| 6| 5| 4| 3| 2| 1| 0|
|-----------------------------------------------------------------------------------------------|
|                     /                               |           e1_ofs                        |
'-----------------------------------------------------------------------------------------------'

 * [13:0] - e1_ofs
```

Word offset inside the E1 data buffer where the next transfer will start

#### USB buffer offset (Write Only, addr `0x0C`)

```text
,-----------------------------------------------------------------------------------------------,
|31|30|29|28|27|26|25|24|23|22|21|20|19|18|17|16|15|14|13|12|11|10| 9| 8| 7| 6| 5| 4| 3| 2| 1| 0|
|-----------------------------------------------------------------------------------------------|
|                              /                                  |        usb_ofs              |
'-----------------------------------------------------------------------------------------------'

 * [9:0] - usb_ofs
```

Word offset inside the USB End Point buffer where the next transfer will start

### `0x87000000`: E1 core

Refer to the [`no2e1` core documentation](../../cores/no2e1/doc/mem-map.md)
for register description.

The core instanciated here has a 1 single channel containing both
RX and TX units.

### `0x88000000`: Misc

Collection of small auxiliary peripherals.

#### Boot (Write Only, addr `0x00`)

```text
,-----------------------------------------------------------------------------------------------,
|31|30|29|28|27|26|25|24|23|22|21|20|19|18|17|16|15|14|13|12|11|10| 9| 8| 7| 6| 5| 4| 3| 2| 1| 0|
|-----------------------------------------------------------------------------------------------|
|                                         /                                            | x| sel |
'-----------------------------------------------------------------------------------------------'

 * [   2] - d   : boot eXecute
 * [11:0] - sel : boot select
```

Write to this register with bit 2 set will trigger a FPGA reload of the selected image.

#### GPIO (Read/Write, addr `0x01`)

```text
,-----------------------------------------------------------------------------------------------,
|31|30|29|28|27|26|25|24|23|22|21|20|19|18|17|16|15|14|13|12|11|10| 9| 8| 7| 6| 5| 4| 3| 2| 1| 0|
|-----------------------------------------------------------------------------------------------|
|                 /                 |  gpio_in  |     /     |  gpio_oe  |     /     |  gpio_out |
'-----------------------------------------------------------------------------------------------'

 * [19:16] - gpio_in  : Input
 * [11: 8] - gpio_oe  : Output Enable (0=Input, 1=Output)
 * [ 3: 0] - gpio_out : Output
```

Note that `gpio[3]` is the `gps_reset_n` signal.

#### E1 connector LEDs (Read/Write, addr `0x02`)

```text
,-----------------------------------------------------------------------------------------------,
|31|30|29|28|27|26|25|24|23|22|21|20|19|18|17|16|15|14|13|12|11|10| 9| 8| 7| 6| 5| 4| 3| 2| 1| 0|
|-----------------------------------------------------------------------------------------------|
|                             /                                   |ac|rn| yl1 | gn1 | yl0 | gn0 |
'-----------------------------------------------------------------------------------------------'

 * [0]   - ac  : Refresh cycle active
 * [8]   - rn  : Run refresh cycle
 * [7:6] - yl1 : Chan 1 yellow led
 * [5:4] - gn1 : Chan 1 green led
 * [3:2] - yl0 : Chan 0 yellow led
 * [1:0] - gn0 : Chan 0 green led
```

This register controls the unit that constantly refreshed the LED and also
polls the push button.

Note that because the pins are shared with flash SPI, this units need to be
disabled before any SPI access to flash ! To do so, set `rn` bit to `0`, then
wait for `ac` to clear, do the SPI access, and finally set `rn` back to `1`.

Each LED can have 4 mode :

 * `00`: Off
 * `01`: On
 * `10`: Slow blink
 * `11`: Fast blink

#### E1 tick source select (Write Only, addr `0x04`)

```text
,-----------------------------------------------------------------------------------------------,
|31|30|29|28|27|26|25|24|23|22|21|20|19|18|17|16|15|14|13|12|11|10| 9| 8| 7| 6| 5| 4| 3| 2| 1| 0|
|-----------------------------------------------------------------------------------------------|
|                     /                   |ts[1]|                   /                     |ts[0]|
'-----------------------------------------------------------------------------------------------'

 * [17:16] - ts[1] : Tick Source for channel 1
 * [ 1: 0] - ts[0] : Tick Source for channel 0
```

Selects the tick source for the counters below for each E1 channel.
Available sources are :

* `0`: TX tick, for every bit sent
* `1`: RX Pulse, for every detected pulse on the input
* `2`: RX Sample, for every bit received
* `3`: RX One, for every `1` bit received

#### E1 tick counters (Read Only, addr `0x04`)

```text
,-----------------------------------------------------------------------------------------------,
|31|30|29|28|27|26|25|24|23|22|21|20|19|18|17|16|15|14|13|12|11|10| 9| 8| 7| 6| 5| 4| 3| 2| 1| 0|
|-----------------------------------------------------------------------------------------------|
|                  chan[1]                      |                   chan[0]                     |
'-----------------------------------------------------------------------------------------------'

 * [31:16] - chan[1] : Tick counter for channel 1
 * [15: 0] - chan[0] : Tick counter for channel 0
```

An internal counter is incremented at every E1 tick (tick source selected above) for each E1
channel. That counter value is then captured at every USB Start-of-Frame packet and the last
captured value made available here.

#### GPS PPS Time (Read Only, addr `0x06`)

```text
,-----------------------------------------------------------------------------------------------,
|31|30|29|28|27|26|25|24|23|22|21|20|19|18|17|16|15|14|13|12|11|10| 9| 8| 7| 6| 5| 4| 3| 2| 1| 0|
|-----------------------------------------------------------------------------------------------|
|                                           pps_time                                            |
'-----------------------------------------------------------------------------------------------'

 * [31:0] - pps_time
```

Time register value (see below) captured at the previous PPS rising edge.

#### Time (Read Only, addr `0x07`)

```text
,-----------------------------------------------------------------------------------------------,
|31|30|29|28|27|26|25|24|23|22|21|20|19|18|17|16|15|14|13|12|11|10| 9| 8| 7| 6| 5| 4| 3| 2| 1| 0|
|-----------------------------------------------------------------------------------------------|
|                                             time                                              |
'-----------------------------------------------------------------------------------------------'

 * [31:0] - time
```

32 bit counter incremented at the system clock rate ( 30.72 MHz )

#### PDM (Write Only, addr `0x08-0x0f`)

This exposes configurable voltages ( DACs ). Some channels are 12 bits, some are 8 bits.

```text
12 bits:

,-----------------------------------------------------------------------------------------------,
|31|30|29|28|27|26|25|24|23|22|21|20|19|18|17|16|15|14|13|12|11|10| 9| 8| 7| 6| 5| 4| 3| 2| 1| 0|
|-----------------------------------------------------------------------------------------------|
|en|                        /                               |            value                  |
'-----------------------------------------------------------------------------------------------'

 * [31  ] - enable (output tristated if 0)
 * [11:0] - value

 8 bits:

,-----------------------------------------------------------------------------------------------,
|31|30|29|28|27|26|25|24|23|22|21|20|19|18|17|16|15|14|13|12|11|10| 9| 8| 7| 6| 5| 4| 3| 2| 1| 0|
|-----------------------------------------------------------------------------------------------|
|en|                               /                                    |      value            |
'-----------------------------------------------------------------------------------------------'

 * [31  ] - enable (output tristated if 0)
 * [11:0] - value
```

Channels :

  * `0`: Clock tune ( low ) [ 12 bits ]
  * `1`: Clock tune ( high ) [ 12 bits ]
  * `2`: E1 RX Negative bias [ 8 bits ]
  * `3`: E1 RX Positive bias [ 8 bits ]
  * `4`: E1 RX Center Tap bias [ 8 bits ]

### `0x8a000000`: I2C

Very simple I2C core.

Note: This is only one of the possible build option. Alternatively the bitstream can be built
using a `SB_I2C` wrapper for I2C support. In which case, refer to the lattice documentation.

#### Command (Write Only, addr `0x00`)

```text
,-----------------------------------------------------------------------------------------------,
|31|30|29|28|27|26|25|24|23|22|21|20|19|18|17|16|15|14|13|12|11|10| 9| 8| 7| 6| 5| 4| 3| 2| 1| 0|
|-----------------------------------------------------------------------------------------------|
|                               /                     | cmd |    /   |ak|      tx_data          |
'-----------------------------------------------------------------------------------------------'

 * [13:12] - cmd     : Command, see list below
 * [8]     - ak      : TX Ack. Bit to send as ACK for CMD_READ
 * [7:0]   - tx_data : TX Data. Byte to send for CMD_WRITE
```

Available commands :

  * `00: CMD_START`: Issue Start condition
  * `01: CMD_STOP`:  Issue Stop condition
  * `10: CMD_WRITE`: Writes 1 byte and reads the ack bit
  * `11: CMD_READ`:  Reads  1 byte and write the ack bit

#### Status (Read Only, addr `0x00`)

```text
,-----------------------------------------------------------------------------------------------,
|31|30|29|28|27|26|25|24|23|22|21|20|19|18|17|16|15|14|13|12|11|10| 9| 8| 7| 6| 5| 4| 3| 2| 1| 0|
|-----------------------------------------------------------------------------------------------|
|ry|                                /                            /   |ak|      rx_data          |
'-----------------------------------------------------------------------------------------------'

 * [32]  - ry      : Ready bit. If not set, core is busy and rest of data is invalid
 * [8]   - ak      : RX Ack. Bit received as ACK during previous CMD_WRITE
 * [7:0] - rx_data : RX Data. Byte read during previous CMD_READ
```

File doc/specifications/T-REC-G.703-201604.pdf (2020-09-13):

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

ITU-T | G.703

TELECOMMUNICATION
STANDARDIZATION SECTOR
OF ITU

(04/2016)

SERIES G: TRANSMISSION SYSTEMS AND MEDIA,

## DIGITAL SYSTEMS AND NETWORKS

## Digital terminal equipments – General

## Physical/electrical characteristics of hierarchical digital interfaces

## Recommendation ITU-T G.703

ITU-T G-SERIES RECOMMENDATIONS

TRANSMISSION SYSTEMS AND MEDIA, DIGITAL SYSTEMS AND NETWORKS

INTERNATIONAL TELEPHONE CONNECTIONS AND CIRCUITS | G.100–G.199
GENERAL CHARACTERISTICS COMMON TO ALL ANALOGUE CARRIER- TRANSMISSION SYSTEMS | G.200–G.299
INDIVIDUAL CHARACTERISTICS OF INTERNATIONAL CARRIER TELEPHONE SYSTEMS ON METALLIC LINES | G.300–G.399
GENERAL CHARACTERISTICS OF INTERNATIONAL CARRIER TELEPHONE SYSTEMS ON RADIO-RELAY OR SATELLITE LINKS AND INTERCONNECTION WITH METALLIC LINES | G.400–G.449
COORDINATION OF RADIOTELEPHONY AND LINE TELEPHONY | G.450–G.499
TRANSMISSION MEDIA AND OPTICAL SYSTEMS CHARACTERISTICS | G.600–G.699
DIGITAL TERMINAL EQUIPMENTS | G.700–G.799
General | G.700–G.709
Coding of voice and audio signals | G.710–G.729
Principal characteristics of primary multiplex equipment | G.730–G.739
Principal characteristics of second order multiplex equipment | G.740–G.749
Principal characteristics of higher order multiplex equipment | G.750–G.759
Principal characteristics of transcoder and digital multiplication equipment | G.760–G.769
Operations, administration and maintenance features of transmission equipment | G.770–G.779
Principal characteristics of multiplexing equipment for the synchronous digital hierarchy | G.780–G.789
Other terminal equipment | G.790–G.799
DIGITAL NETWORKS | G.800–G.899
DIGITAL SECTIONS AND DIGITAL LINE SYSTEM | G.900–G.999
MULTIMEDIA QUALITY OF SERVICE AND PERFORMANCE – GENERIC AND USER- RELATED ASPECTS | G.1000–G.1999
TRANSMISSION MEDIA CHARACTERISTICS | G.6000–G.6999
DATA OVER TRANSPORT – GENERIC ASPECTS | G.7000–G.7999
PACKET OVER TRANSPORT ASPECTS | G.8000–G.8999
ACCESS NETWORKS | G.9000–G.9999

For further details, please refer to the list of ITU-T Recommendations.

Rec. ITU-T G.703 (04/2016) | i

Recommendation ITU-T G.703

Physical/electrical characteristics of hierarchical digital interfaces

Summary

Recommendation ITU-T G.703 specifies the recommended physical and electrical characteristics of the interfaces at hierarchical bit rates as described in Recommendations ITU-T G.702 (PDH) and ITU-T G.707 (SDH). The interfaces are defined in terms of general characteristics, specifications at the output ports and input ports and/or cross-connect points, earthing of outer conductor or screen and coding rules.

History

Edition | Recommendation | Approval | Study Group | Unique ID*
1.0 | ITU-T G.703 | 1972-12-15 | | 11.1002/1000/11264 (http://handle.itu.int/11.1002/1000/11264)
2.0 | ITU-T G.703 | 1976-10-08 | | 11.1002/1000/9993 (http://handle.itu.int/11.1002/1000/9993)
3.0 | ITU-T G.703 | 1980-11-21 | | 11.1002/1000/7754 (http://handle.itu.int/11.1002/1000/7754)
4.0 | ITU-T G.703 | 1984-10-19 | | 11.1002/1000/3630 (http://handle.itu.int/11.1002/1000/3630)
5.0 | ITU-T G.703 | 1988-11-25 | | 11.1002/1000/894 (http://handle.itu.int/11.1002/1000/894)
6.0 | ITU-T G.703 | 1991-04-05 | XVIII | 11.1002/1000/895 (http://handle.itu.int/11.1002/1000/895)
7.0 | ITU-T G.703 | 1998-10-13 | 15 | 11.1002/1000/4514 (http://handle.itu.int/11.1002/1000/4514)
8.0 | ITU-T G.703 | 2001-11-29 | 15 | 11.1002/1000/5602 (http://handle.itu.int/11.1002/1000/5602)
8.1 | ITU-T G.703 (2001) Cor. 1 | 2008-03-29 | 15 | 11.1002/1000/9369 (http://handle.itu.int/11.1002/1000/9369)
8.2 | ITU-T G.703 (2001) Amd. 1 2013-08-29 | 15 | 11.1002/1000/11989 (http://handle.itu.int/11.1002/1000/11989)
9.0 | ITU-T G.703 | 2016-04-13 | 15 | 11.1002/1000/12788 (http://handle.itu.int/11.1002/1000/12788)

Keywords
Electrical interface, PDH, plesiochronous digital hierarchy, SDH, synchronous digital hierarchy, synchronization interface.

* To access the Recommendation, type the URL http://handle.itu.int/ in the address field of your web browser, followed by the Recommendation's unique ID. For example, http://handle.itu.int/11.1002/1000/11 830-en. (http://handle.itu.int/11.1002/1000/11830-en)

ii | Rec. ITU-T G.703 (04/2016)

FOREWORD

The International Telecommunication Union (ITU) is the United Nations specialized agency in the field of telecommunications, information and communication technologies (ICTs). The ITU Telecommunication Standardization Sector (ITU-T) is a permanent organ of ITU. ITU-T is responsible for studying technical, operating and tariff questions and issuing Recommendations on them with a view to standardizing telecommunications on a worldwide basis.

The World Telecommunication Standardization Assembly (WTSA), which meets every four years, establishes the topics for study by the ITU-T study groups which, in turn, produce Recommendations on these topics.

The approval of ITU-T Recommendations is covered by the procedure laid down in WTSA Resolution 1.

In some areas of information technology which fall within ITU-T's purview, the necessary standards are prepared on a collaborative basis with ISO and IEC.

NOTE

In this Recommendation, the expression "Administration" is used for conciseness to indicate both a telecommunication administration and a recognized operating agency.
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

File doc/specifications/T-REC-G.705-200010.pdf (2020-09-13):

ITU-T | G.705

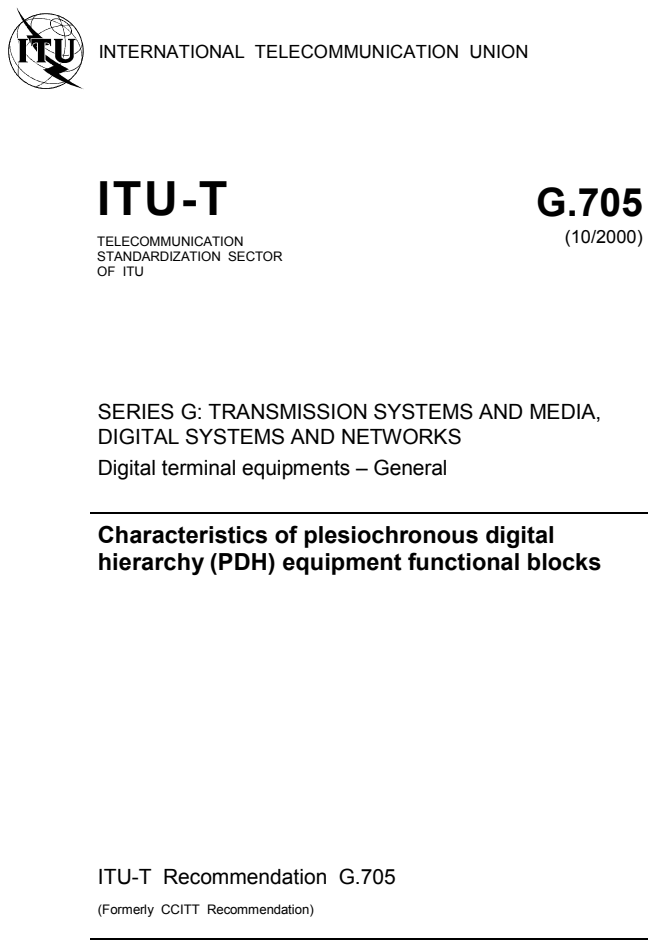
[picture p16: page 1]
TELECOMMUNICATION STANDARDIZATION SECTOR OF ITU; ITU-T Recommendation G.705

INTERNATIONAL TELECOMMUNICATION UNION

SERIES G: TRANSMISSION SYSTEMS AND MEDIA,
DIGITAL SYSTEMS AND NETWORKS
Digital terminal equipments ñ General

Characteristics of plesiochronous digital
hierarchy (PDH) equipment functional blocks

(Formerly CCITT Recommendation)
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

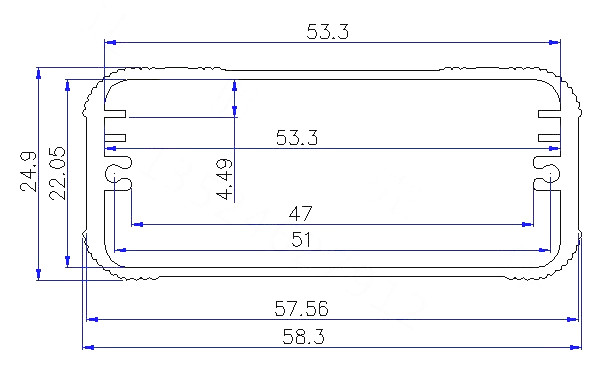
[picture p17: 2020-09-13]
mechanical/icE1usb-case/doc/SZOMK_AK-C-B-37.jpg

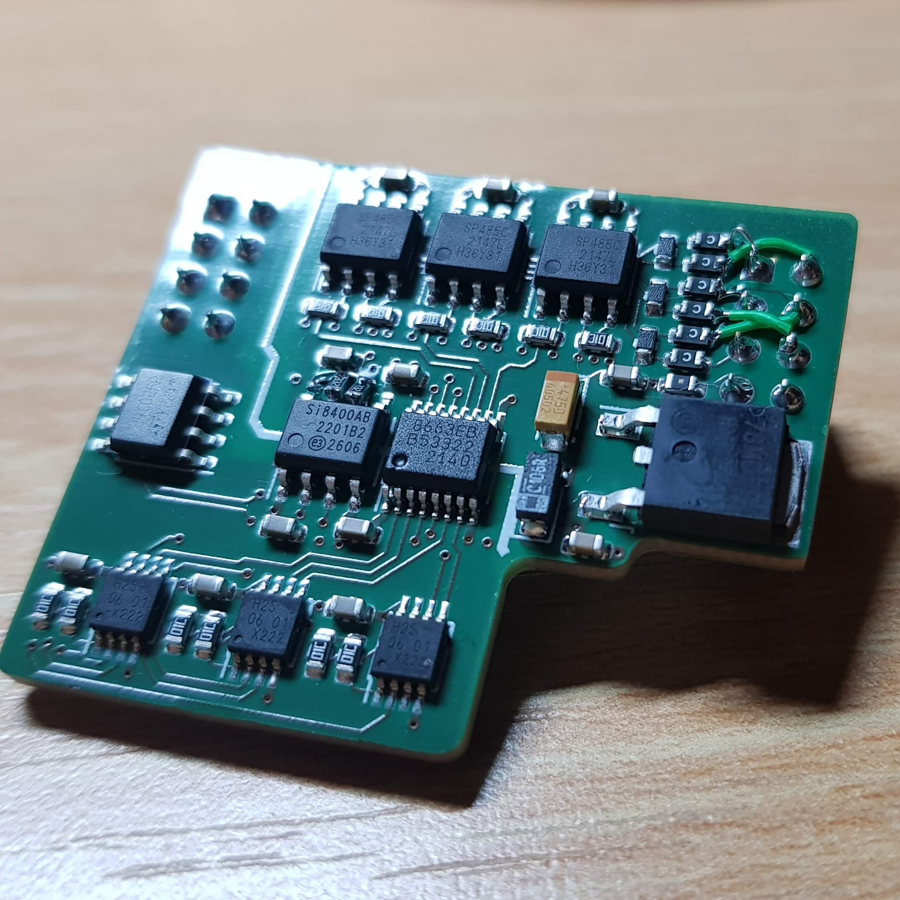
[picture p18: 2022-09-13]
hardware/icE1usb-rs422/r0.1/icE1usb-rs422-rework.jpg

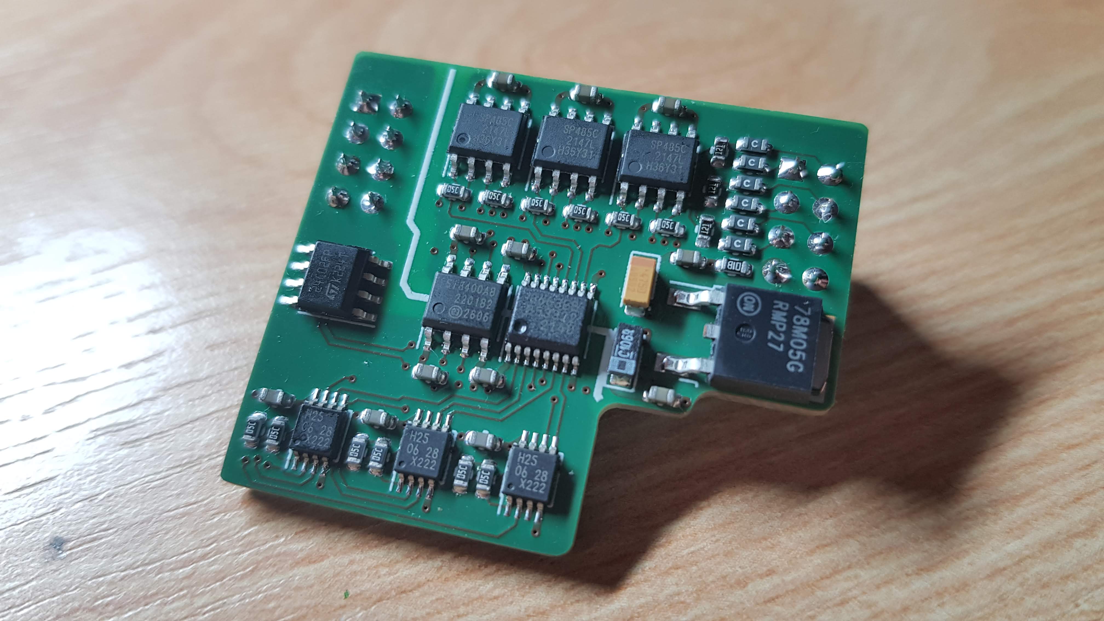
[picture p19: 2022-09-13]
hardware/icE1usb-rs422/r0.1/icE1usb-rs422-orig.jpg

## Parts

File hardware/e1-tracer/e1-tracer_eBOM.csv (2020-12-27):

 | e1-tracer.sch | 2020-12-20 21:02:07 |  | EAGLE Version 7.7.0 Copyright (c) 1988-2016 CadSoft
Qty | Name | Value | Package | Class | Supplier | Part Number | URL | Description | Populated | Beistellung
19 | C1, C2, C3, C4, C5, C6, C7, C11, C16, C17, C18, C19, C20, C21, C22, C23, C24, C29, C30 | 100n | _0603 | CAPACITOR | DIGIKEY | 1276-1005-1-ND | http://www.digikey.de/product-detail/de/foo/1276-1005-1-ND | CAP CER 0.1UF 16V 10% X7R 0603 | TRUE
4 | C8, C9, C10, C12 | 1u | _0603 | CAPACITOR | DIGIKEY | 1276-1182-1-ND | https://www.digikey.de/product-detail/de/samsung-electro-mechanics/CL10A105KP8NNNC/1276-1182-1-ND/3889268 | CAP CER 1UF 10V X5R 0603 | TRUE
2 | C13, C15 | 22u | 1206 | CAPACITOR | DIGIKEY | 1276-1287-1-ND | http://www.digikey.de/product-detail/de/foo/1276-1287-1-ND | CAP CER 22UF 10V 10% X5R 1206 | TRUE
1 | C14 | 10n | _0402 | CAPACITOR | DIGIKEY | 1276-1057-1-ND | https://www.digikey.de/product-detail/de/samsung-electro-mechanics/CL05B103KA5NNNC/1276-1057-1-ND/3889143 | CAP CER 10000PF 25V X7R 0402 | TRUE
4 | C25, C26, C27, C28 | 22u | _0805 | CAPACITOR | DIGIKEY | 399-4696-1-ND | https://www.digikey.de/product-detail/de/kemet/C0805C226M9PACTU/399-4696-1-ND | CAP CER 22UF 6.3V X5R 0805 | TRUE
1 | CDONE | BLUE | CHIPLED_0603 | LED | DIGIKEY | 160-1827-1-ND | https://www.digikey.de/product-detail/de/lite-on-inc/LTST-C193TBKT-5A/160-1827-1-ND | LED BLUE CLEAR CHIP SMD | TRUE
1 | LED1 |  | RGBLED_PLCC4 | LED | DIGIKEY | 365-1561-2-ND | https://www.digikey.de/product-detail/de/tt-electronics-optek-technology/OVSARGB4R8/365-1561-2-ND | LED RGB DIFFUSED 4PLCC SMD | TRUE
2 | LOS1, LOS2 | LEDPLCC2-MIN-red | PLCC2-MIN | LED | DIGIKEY | 475-2683-1-ND | https://www.digikey.de/product-detail/de/osram-opto-semiconductors-inc/LS-T676-R1S1-1-Z/475-2683-1-ND | LED RED CLEAR 2PLCC SMD | TRUE
1 | PWR | LEDPLCC2-MIN-green | PLCC2-MIN | LED | DIGIKEY | 511-1645-1-ND | https://www.digikey.de/product-detail/de/rohm-semiconductor/SML-Z14PTT86A/511-1645-1-ND | LED GREEN CLEAR 2PLCC SMD | TRUE
8 | D1, D2, D3, D4, D5, D6, D7, D8 | MBR0540T1 | SOD123 | DIODE | DIGIKEY | MBR0540T1GOSCT-ND | https://www.digikey.de/product-detail/de/on-semiconductor/MBR0540T1G/MBR0540T1GOSCT-ND | DIODE SCHOTTKY 40V 500MA SOD123 | TRUE
1 | IC1 | MCP1703T-1202E/CB | SOT23-3 | IC | DIGIKEY | MCP1703T-1202E/CBCT-ND | https://www.digikey.de/product-detail/de/microchip-technology/MCP1703T-1202E-CB/MCP1703T-1202E-CBCT-ND/1994670 | IC REG LIN 1.2V 200MA SOT23A-3 | TRUE
1 | IC2 | W25Q80DVSNIG | SO08COMBINED | IC | DIGIKEY | W25Q80DVSNIG-ND | https://www.digikey.de/product-detail/de/winbond-electronics/W25Q80DVSNIG/W25Q80DVSNIG-ND | IC FLASH 8M SPI 104MHZ 8SOIC | TRUE
1 | IC3 | TLV70233DBVR | SOT23-DBV | IC | DIGIKEY | 296-32415-1-ND | https://www.digikey.de/product-detail/de/texas-instruments/TLV70233DBVR/296-32415-1-ND | IC REG LINEAR 3.3V 300MA SOT23-5 | TRUE
1 | U1 | ICE40UP5K-SG48I | QFN48 | IC | DIGIKEY | 220-2212-1-ND | https://www.digikey.de/product-detail/de/lattice-semiconductor-corporation/ICE40UP5K-SG48I/220-2212-1-ND/ | IC FPGA 39 I/O 48QFN | TRUE
2 | U2, U3 | IP4234CZ6 | TSOP-6 | IC | DIGIKEY | 1727-4717-1-ND | https://www.digikey.de/product-detail/de/nexperia-usa-inc/IP4234CZ6125/1727-4717-1-ND/2531156 | TVS DIODE 5.5V 6TSOP | TRUE
2 | U4, U5 | IDT82V2081 | TQFP44 | IC | DIGIKEY | 800-2347-ND | https://www.digikey.de/product-detail/de/renesas-electronics-america-inc/82V2081PPG/800-2347-ND | IC TELECOM INTERFACE 44TQFP | TRUE
1 | IC4 | ASEMB-12.000MHZ-LC-T | TSX-3225 | IC / XTAL / XO | DIGIKEY | 535-11744-1-ND | https://www.digikey.de/product-detail/de/abracon-llc/ASEMB-12-000MHZ-LC-T/535-11744-1-ND | MEMS OSC XO 12.0000MHZ CMOS SMD | TRUE
1 | U6 | 2.048 Mhz | HC73 | IC / XTAL / XO | DIGIKEY | 631-1182-ND | https://www.digikey.de/product-detail/de/renesas-electronics-america-inc/XLH736002-048000I/631-1182-ND | XTAL OSC XO 2.0480MHZ HCMOS SMD | TRUE
1 | U7 | 1.544 MHz | HC73 | IC / XTAL / XO | UNKNOWN SOURCE | UNKNOWN SOURCE PART NUMBER | UNKNOWN LINK | NO DESCRIPTION | FALSE
1 | J1 | PASSTHROUGH | 557560-1 | CONNECTOR\JUMPER | DIGIKEY | A31449-ND | https://www.digikey.de/product-detail/de/te-connectivity-amp-connectors/5557560-1/A31449-ND | CONN MOD JACK 8P8C R/A UNSHLD | TRUE
1 | JP1 |  | 1X08_LOCK | CONNECTOR\JUMPER | UNKNOWN SOURCE | UNKNOWN SOURCE PART NUMBER | UNKNOWN LINK | NO DESCRIPTION | TRUE
1 | L1 | 744231091 | WE-CNSW_0805 | INDUCTOR | DIGIKEY | 732-3198-1-ND | https://www.digikey.de/product-detail/de/wurth-electronics-inc/744231091/732-3198-1-ND | CMC 370MA 2LN 90 OHM SMD | TRUE
2 | L2, L3 | 47nH | 0805 | INDUCTOR | DIGIKEY | CE201210-47NJCT-ND | https://www.digikey.de/product-detail/de/bourns-inc/CE201210-47NJ/CE201210-47NJCT-ND/3438045 | FIXED IND 47NH 300MA 700MOHM SMD | TRUE
2 | M1, M2 | MENTOR_12701001 | 1270.1001 | LIGHT GUIDE | UNKNOWN SOURCE | UNKNOWN SOURCE PART NUMBER | UNKNOWN LINK | NO DESCRIPTION | TRUE
1 | R1 | 100R | _0603 | RESISTOR | DIGIKEY | RMCF0603JT100RCT-ND | https://www.digikey.de/product-detail/de/stackpole-electronics-inc/RMCF0603JT100R/RMCF0603JT100RCT-ND | RES 100 OHM 5%% 1/10W 0603 | TRUE
7 | R2, R3, R4, R5, R44, R45, R46 | DNP | _0603 | RESISTOR | DIGIKEY | P0.0GCT-ND | https://www.digikey.de/product-detail/de/panasonic-electronic-components/ERJ-3GEY0R00V/P0-0GCT-ND/134711 | RES SMD 0 OHM JUMPER 1/10W 0603 | FALSE
2 | R6, R7 | 33 | _0402 | RESISTOR | DIGIKEY | 311-33.0LRCT-ND | https://www.digikey.de/product-detail/de/yageo/RC0402FR-0733RL/311-33-0LRCT-ND/729540 | RES SMD 33 OHM 1%% 1/16W 0402 | TRUE
23 | R8, R10, R13, R16, R17, R18, R19, R20, R21, R22, R23, R24, R25, R26, R27, R28, R29, R30, R31, R32, R33, R36, R37 | 10k | _0603 | RESISTOR | DIGIKEY | RMCF0603JT10K0CT-ND | https://www.digikey.de/product-detail/de/stackpole-electronics-inc/RMCF0603JT10K0/RMCF0603JT10K0CT-ND | RES 10K OHM 5%% 1/10W 0603 | TRUE
1 | R9 | 1k5 | _0603 | RESISTOR | DIGIKEY | RMCF0603JT1K50CT-ND | https://www.digikey.de/product-detail/de/stackpole-electronics-inc/RMCF0603JT1K50/RMCF0603JT1K50CT-ND | RES 1.5K OHM 5%% 1/10W 0603 | TRUE
2 | R11, R12 | 100k | _0603 | RESISTOR | DIGIKEY | 311-100KGRCT-ND | https://www.digikey.de/product-detail/de/yageo/RC0603JR-07100KL/311-100KGRCT-ND/729645 | RES SMD 100K OHM 5%% 1/10W 0603 | TRUE
1 | R14 | 2.2k | _0603 | RESISTOR | DIGIKEY | RMCF0603JT2K20CT-ND | https://www.digikey.de/product-detail/de/stackpole-electronics-inc/RMCF0603JT2K20/RMCF0603JT2K20CT-ND | RES 2.2K OHM 5%% 1/10W 0603 | TRUE
3 | R15, R40, R41 | 330 | _0603 | RESISTOR | DIGIKEY | 311-330HRCT-ND | https://www.digikey.de/product-detail/de/yageo/RC0603FR-07330RL/311-330HRCT-ND | RES SMD 330 OHM 1%% 1/10W 0603 | TRUE
2 | R34, R35 | 3k 1% | _0603 | RESISTOR | DIGIKEY | RMCF0603FT3K00CT-ND | https://www.digikey.de/product-detail/de/stackpole-electronics-inc/RMCF0603FT3K00/RMCF0603FT3K00CT-ND | RES 3K OHM 1%% 1/10W 0603 | TRUE
2 | R38, R39 | 120 | _0603 | RESISTOR | DIGIKEY | RMCF0603JT120RCT-ND | https://www.digikey.de/product-detail/de/stackpole-electronics-inc/RMCF0603JT120R/RMCF0603JT120RCT-ND | RES 120 OHM 5%% 1/10W 0603 | TRUE
2 | R42, R43 | 1k | _0603 | RESISTOR | DIGIKEY | RMCF0603JT1K00CT-ND | https://www.digikey.de/product-detail/de/stackpole-electronics-inc/RMCF0603JT1K00/RMCF0603JT1K00CT-ND/1943173 | RES 1K OHM 5%% 1/10W 0603 | TRUE
1 | SW1 | TACTSW-TL3340 | TL3340-ORIG | SWITCH | DIGIKEY | EG4627CT-ND | https://www.digikey.de/product-detail/de/e-switch/TL3340AF160QG/EG4627CT-ND/1885974 | SWITCH TACTILE SPST-NO 0.05A 12V | TRUE
2 | T1, T2 | BC847C | SOT23-BEC | TRANSISTOR | DIGIKEY | 1727-2924-1-ND | https://www.digikey.de/product-detail/de/nexperia-usa-inc/BC847C,215/1727-2924-1-ND | TRANS NPN 45V 0.1A SOT23 | TRUE
2 | TR1, TR2 | PULSE_T1094NL | PULSE_BH | TRANSFORMER | DIGIKEY | 553-1449-ND | https://www.digikey.de/product-detail/de/pulse-electronics-network/T1094NL/553-1449-ND | TRANSFORMER TELECOM DUAL T1/E2 | TRUE
1 | X1 | MINI-USB-SHIELD-UX60-MB-5ST | UX60-MB-5ST | CONNECTOR | DIGIKEY | H2961CT-ND | https://www.digikey.de/product-detail/de/hirose-electric-co-ltd/UX60A-MB-5ST/H2961CT-ND/597540 | CONN RCPT USB2.0 MINI B SMD R/A | TRUE
1 | X2 | JACK2.5_SJ-2523 | JACK2.5_SJ-2523 | CONNECTOR | DIGIKEY | CP-2523SJCT-ND | https://www.digikey.de/product-detail/de/cui-inc/SJ-2523-SMT-TR/CP-2523SJCT-ND/669702 | CONN JACK STEREO 2.5MM SMD R/A | TRUE

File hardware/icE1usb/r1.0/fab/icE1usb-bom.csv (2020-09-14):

BOM line | References | Quantity | Description | Value | Footprint | Manufacturer | MPN | Supplier | Supplier Reference
1 | C1 C2 C3 C4 C6 C7 C8 C9 C12 C13 C14 C15 C16 C17 C18 C19 C20 C22 C23 C25 C33 C34 C35 C36 C37 C38 C39 | 27 | MLCC Capacitor X7R/X5R >25V | 100n | SMD_0603 | Murata | GRM188R71H104KA93D | LCSC | C77055
2 | C5 C10 C11 C24 C26 C27 C28 C29 C30 C31 C32 | 11 | MLCC Capacitor X7R/X5R >25V | 1u | SMD_0603 | Murata | GRM188R61H105KAALD | LCSC | C77386
3 | R5 R7 R10 R11 | 4 | SMD Resistor 0603 1% 0.0625W | 1k5 | SMD_0603 | Uniroyal Elec | 0603WAF1501T5E | LCSC | C22843
4 | R4 R15 R26 | 3 | SMD Resistor 0603 1% 0.0625W | 120R | SMD_0603 | Uniroyal Elec | 0603WAF1200T5E | LCSC | C22787
5 | R2 R3 R6 R8 R13 R14 R24 R25 | 8 | SMD Resistor 0603 1% 0.0625W | 5k1 | SMD_0603 | Uniroyal Elec | 0603WAF5101T5E | LCSC | C23186
6 | R20 R22 | 2 | SMD Resistor 0603 1% 0.0625W | 0R | SMD_0603 | Uniroyal Elec | 0603WAF0000T5E | LCSC | C21189
7 | R12 R16 R17 R27 R28 | 5 | SMD Resistor 0603 1% 0.0625W | 27R | SMD_0603 | Uniroyal Elec | 0603WAF270JT5E | LCSC | C25190
8 | R1 R9 | 2 | SMD Resistor 0603 1% 0.0625W | 91k | SMD_0603 | Uniroyal Elec | 0603WAF9102T5E | LCSC | C23265
9 | RN1 RN2 RN3 RN6 | 4 | SMD Resistor Pack 4x0603 = 1206 5% 0.0625W | 33R | SMD_4x0603_1206 | Uniroyal Elec | 4D03WGF330JT5E | LCSC | C425214
10 | RN4 RN5 RN7 RN8 | 4 | SMD Resistor Pack 4x0603 = 1206 5% 0.0625W | 10k | SMD_4x0603_1206 | Uniroyal Elec | 4D03WGF1002T5E | LCSC | C109324
11 | L1 | 1 | SMD RF inductor wirewound | 47n | SMD_0402 | Murata | LQW15AN47NG00D | LCSC | C22334
12 | D1 | 1 | RGB LED |  | LED_2020 | Foshan NationStar Optoelectronics | FM-B2020RGBA-HG | LCSC | C108793
13 | D2 | 1 | Blue LED (high efficiency) | Blue | SMD_0603 | Foshan NationStar Optoelectronics | NCD0603B1 | LCSC | C84266
14 | D3 | 1 | RF ESD protection 0402 | PESD0402-140 | SMD_0402 | LittleFuse | PESD0402-140 | LCSC | C10662
15 | F2 F3 F4 F1 F6 F7 F8 F5 | 8 | Polyfuse PTC 300mA 0603 | 300mA | SMD_0603 | LittleFuse | 0603L010 | LCSC | C207010
16 | J1 J2 J3 J4 J5 | 5 | Pin Header Male Pin 2.54mm, 2x4 contacts |  | 2x4 pin header | MINTRON | MTP125-1204S1 | LCSC | C358693
17 | SW1 | 1 | Push button (side) |  |  | HYP (Hongyuan Precision) | 1TS003B-1600-3500A-CT | LCSC | C255808
18 | TR1 TR2 | 2 | Pulse transformer for E1 applications | T1094NL |  | Pulse Electronics Network | T1094NL | Digikey | 553-1449-ND
19 | U1 | 1 | FPGA | ICE40UP5K-SG48 | QFN 48 | Lattice | ICE40UP5K-SG48 | Digikey | 220-2212-1-ND
20 | U3 | 1 | Shift register | 74HC595 | TSSOP-16 | Nexperia | 74HC595PW,118 | LCSC | C5948
21 | U4 | 1 | VCXO 30.72 MHz | 30.72 MHz | 7mm x 5mm | SiTime | SIT3808AI-D2-33EE-30.720000T | Digikey | 1473-SIT3808AI-D2-33EE-30.720000T-ND
 |  |  |  |  |  | Taitien | VTEUALJANF-30.720000 | Digikey | 1664-1336-1-ND
22 | U5 | 1 | SPI Flash | SPI_FLASH_8P | SOIC-8 150mil | Winbond | W25Q80DVSNIG | LCSC | C401655
23 | U8 | 1 | GPS Module |  |  | ZHONGKEWEI | ATGM336H-5N31 | LCSC | C90770
 |  |  |  |  |  | ublox | MAX-M8W | Digikey | 672-MAX-M8W-0-10CT-ND
24 | U9 | 1 | LDO 1.2v with enable | MIC5504-1.2YM5 | SOT-23-5 | Microchip | MIC5504-1.2YM5-TR | Digikey | 576-4878-1-ND
25 | U10 | 1 | LDO 3.3v with enable | MIC5504-3.3YM5 | SOT-23-5 | Microchip | MIC5504-3.3YM5-TR | LCSC | C88419
26 | U2 U6 U7 U11 U12 | 5 | ESD protection | IP4220CZ6 | TSOP-6 | Nexperia | IP4220CZ6,125 | LCSC | C282546
27 | X1 | 1 | SMA right angle connector |  |  | Shenzhen Kinghelm Elec | KH-SMA-KWE17-G | LCSC | C530662
 |  |  |  |  |  | TE Connectivity | 619540-1 | Mouser | 571-619540-1
28 | X2 | 1 | 2.5mm jack SMD connector, 3 contacts |  |  | CUI | SJ-2523-SMT-TR | Digikey | CP-2523SJCT-ND
29 | X3 | 1 | RJ45 connector |  |  | CONNFLY Elec | DS1128-06-S8B0P-X | LCSC | C86575
 |  |  |  |  |  | Amphenol ICC | RJHSE-5080 | Digikey | RJHSE-5080-ND
30 | X4 | 1 | USB Type C socket |  |  | Korean Hroparts Elec | TYPE-C-31-M-12 | LCSC | C165948
31 | X5 | 1 | Dual RJ45 connector with leds |  |  | CONNFLY Elec | DS1129-04-S8B0P-X | LCSC | C86581
 |  |  |  |  |  | Amphenol ICC | RJHSE-5081-02 | Digikey | RJHSE508102-ND
32 | LP1 | 1 | Light pipe |  |  | Lumex | LPF-C011303S | Digikey | 67-2200-ND
33 | n/a | 8 | Pin header jumper |  |  | Boom Precision Elec | n/a | LCSC | C5305

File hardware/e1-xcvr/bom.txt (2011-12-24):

Partlist

Exported from e1_xcvr.sch at 24 Dec 2011 16:01:15

EAGLE Version 6.0.0 Copyright (c) 1988-2011 CadSoft

Assembly variant: 

Part     Value          Device               Package      Library         Sheet

C1       100nF          C-EUC0603            C0603        rcl             1
C2       100nF          C-EUC0603            C0603        rcl             1
C3       100nF          C-EUC0603            C0603        rcl             1
C4       100nF          C-EUC0603            C0603        rcl             1
C5                      C-EUC0603            C0603        rcl             1
C6       100nF          C-EUC0603            C0603        rcl             1
C7       100nF          C-EUC0603            C0603        rcl             1
C8       1nF            C-EUC0603            C0603        rcl             1
C9       68uF           C-EUC1206K           C1206K       rcl             1
C10      68uF (NC)      C-EUC1206K           C1206K       rcl             1
D1       MBR0540T1      D-FILL-SOD123        SOD123       semicon-smd-ipc 1
D2       MBR0540T1      D-FILL-SOD123        SOD123       semicon-smd-ipc 1
D3       MBR0540T1      D-FILL-SOD123        SOD123       semicon-smd-ipc 1
D4       MBR0540T1      D-FILL-SOD123        SOD123       semicon-smd-ipc 1
D5       MBR0540T1      D-FILL-SOD123        SOD123       semicon-smd-ipc 1
D6       MBR0540T1      D-FILL-SOD123        SOD123       semicon-smd-ipc 1
D7       MBR0540T1      D-FILL-SOD123        SOD123       semicon-smd-ipc 1
D8       MBR0540T1      D-FILL-SOD123        SOD123       semicon-smd-ipc 1
J2                      557560-1             557560-1     con-amp         1
JP1      SPI CONTROL    PINHD-2X5            2X05         pinhead         1
JP2      TDM            PINHD-2X5            2X05         pinhead         1
JP9      1544/2048      JP2E                 JP2          jumper          1
JP10     TCLK/MCLK      JP1E                 JP1          jumper          1
L1                      SM-1206              SM-1206      inductor-neosid 1
LED1     RED            LEDCHIPLED_0805      CHIPLED_0805 led             1
LED2     GREEN          LEDCHIPLED_0805      CHIPLED_0805 led             1
R1       3k 1%          R-EU_R0603           R0603        rcl             1
R2       10k            R-EU_R0603           R0603        rcl             1
R3       120            R-EU_R0603           R0603        rcl             1
R4       0              R-EU_R0603           R0603        rcl             1
R5       0              R-EU_R0603           R0603        rcl             1
R6       10k            R-EU_R0603           R0603        rcl             1
R7       68             R-EU_R0603           R0603        rcl             1
SJ1                     SJ                   SJ           jumper          1
SJ2                     SJ                   SJ           jumper          1
T1       BC847C         BC847C-NPN-SOT23-BEC SOT23-BEC    transistor      1
TP1      TPPAD1-13      TPPAD1-13            P1-13        testpad         1
TP2      TPPAD1-13      TPPAD1-13            P1-13        testpad         1
TP3      TPPAD1-13      TPPAD1-13            P1-13        testpad         1
TP4      TPPAD1-13      TPPAD1-13            P1-13        testpad         1
U$1      IDT82V2081     IDT82V2081           TQFP44       laforge         1
U$2      PULSE_T1094NL  PULSE_T1094NL        PULSE_BH     laforge         1
U$3      2.048 Mhz      FOX_FXO-HC73         HC73         laforge         1
U$4      1.544 MHz      FOX_FXO-HC73         HC73         laforge         1
U$5      MNR            MNR                  MNR35        laforge         1
U$6      TPS736XX       TPS736XX             SOT223-6     laforge         1

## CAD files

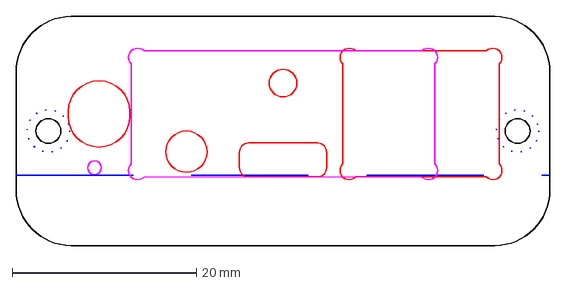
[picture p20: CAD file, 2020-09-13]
mechanical/icE1usb-case/icE1usb_end_panels.dxf
58.0 x 24.9 mm

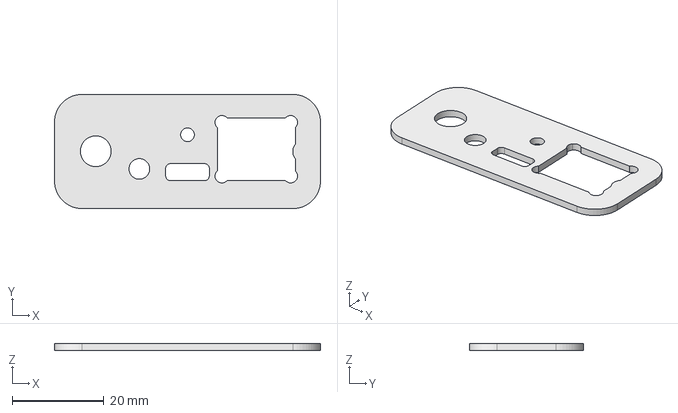
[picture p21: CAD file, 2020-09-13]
mechanical/icE1usb-case/r0.0/front_panel.FCStd
58.0 x 24.9 x 1.50 mm
Stock-Body

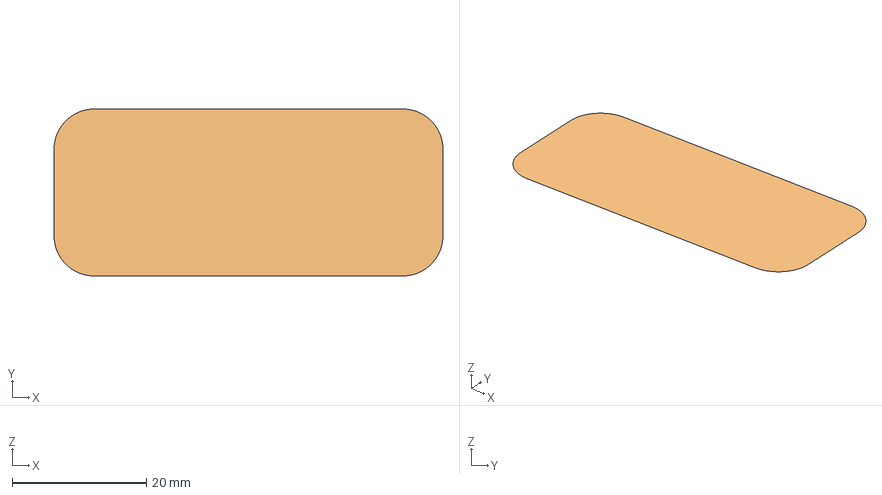
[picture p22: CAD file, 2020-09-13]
mechanical/icE1usb-case/r0.1/back_panel.FCStd
58.0 x 24.9 x 0 mm
Model-Back
Model-Outline
Model-PortE1

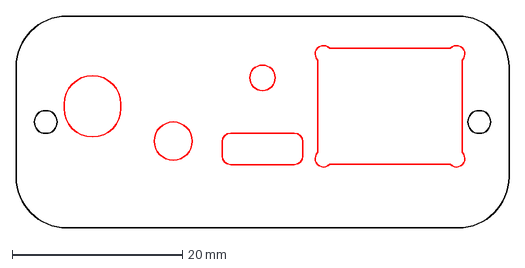
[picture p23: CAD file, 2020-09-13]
mechanical/icE1usb-case/r1.0/front_panel.dxf
58.0 x 24.9 mm

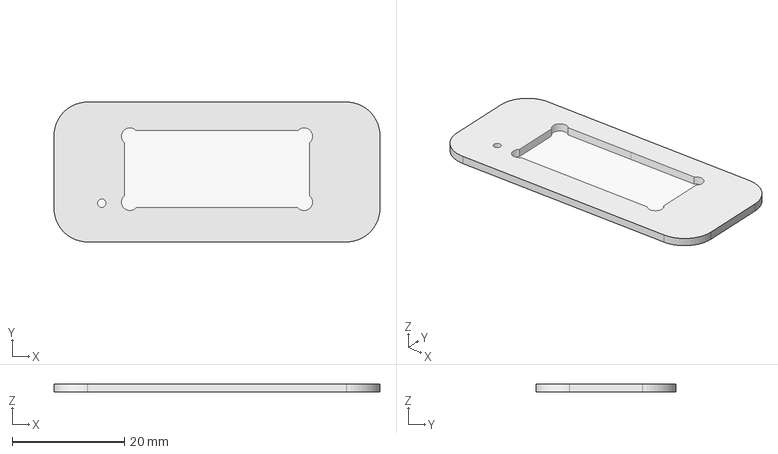
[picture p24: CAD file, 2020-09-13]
mechanical/icE1usb-case/r0.0/back_panel.FCStd
58.0 x 24.9 x 1.50 mm
Stock-PadOutline

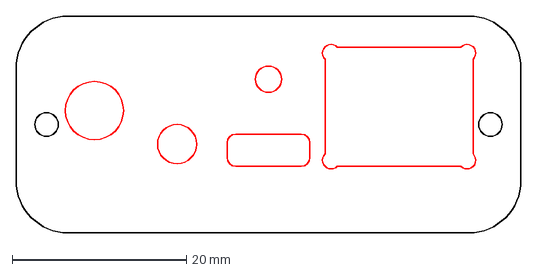
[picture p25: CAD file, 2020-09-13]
mechanical/icE1usb-case/r0.1/icE1usb_end_panels.dxf
58.0 x 24.9 mm

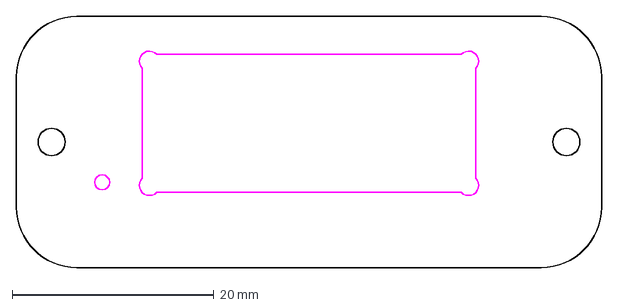
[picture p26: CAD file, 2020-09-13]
mechanical/icE1usb-case/r1.0/back_panel.dxf
58.0 x 24.9 mm

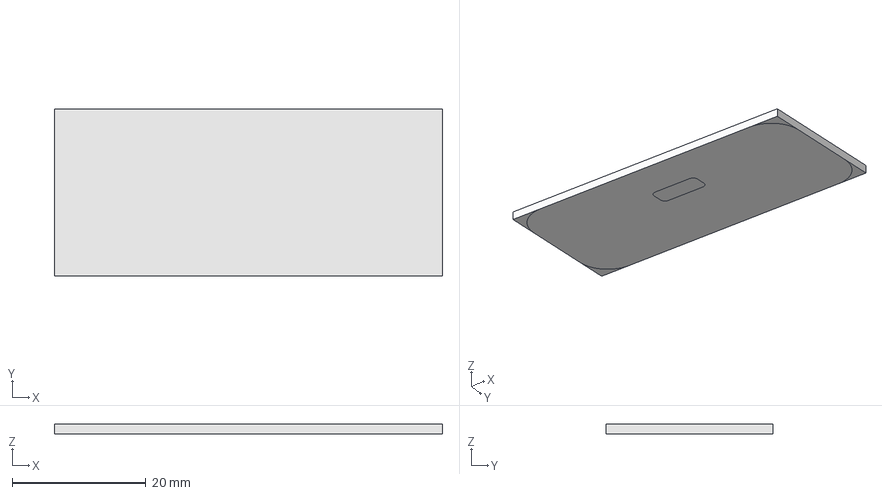
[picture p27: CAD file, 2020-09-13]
mechanical/icE1usb-case/r0.1/front_panel.FCStd
58.0 x 24.9 x 1.50 mm
Model-Front
Model-Outline
Model-PortRJ45
Model-PortUSB
Stock001

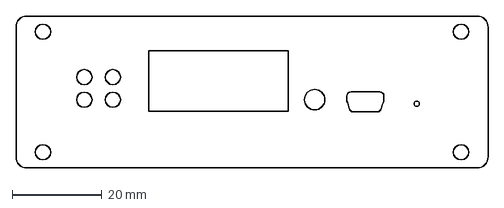
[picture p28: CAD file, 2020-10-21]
mechanical/e1-tracer-enclosure/e1-tracer-faceplate_export.dxf
105.0 x 33.8 mm

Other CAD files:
mechanical/icE1usb-case/doc/akg_55_24.dxf
mechanical/e1-tracer-enclosure/e1-tracer-faceplate_fischer_bgt_tfp_export.dxf
mechanical/e1-tracer-enclosure/e1-tracer-faceplate_contruction.dxf
mechanical/icE1usb-case/r0.1/back_panel.dxf
mechanical/icE1usb-case/r0.1/front_panel.dxf

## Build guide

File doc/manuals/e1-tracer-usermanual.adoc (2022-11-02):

:gfdl-enabled:

e1-tracer User Manual
===================
Harald Welte <hwelte@sysmocom.de>

include::./common/chapters/preface.adoc[]

include::./chapters/e1-tracer/hardware.adoc[]

include::./chapters/e1-tracer/gateware.adoc[]

include::./chapters/e1-tracer/firmware.adoc[]

include::./chapters/e1-tracer/host-software.adoc[]

include::./common/chapters/gfdl.adoc[]

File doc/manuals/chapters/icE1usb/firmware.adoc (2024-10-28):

[[firmware]]
== icE1usb Firmware

The icE1usb _firmware_ is a small amount of bare-iron software running
on the picoRISCV soft-core of the _gateware_.

It mainly consists of drivers for the no2e1 E1 Framer IP core and the
no2usb USB Device IP core which are part of the gateware described in
<<gateware>>.

=== Firmware Upgrade (DFU)

icE1usb contains support for the USB DFU (Device Firmware Upgrade)
standard.

As such, you can use any USB DFU compliant utility to upgrade the
firmware of the icE1usb device.

DFU mode can be entered in two ways:

1. by performing a DFU detach from the normal application firmware
   (obviously that requires a [still] working firmware present on the
   device).  To do so, please use `dfu-util -e`

2. by pushing the push-button (see <<hw-pushbutton>>) during power-up.
   Simply disconnect the USB cable, then push that button and keep it
   pushed while re-attaching the USB cable.

The icE1usb boot loader enumerates as VID:PID `1d50:6144`, while the
normal application firmware enumerates as `1d50:6145`,

You can for example use `lsusb` to check the VID:PID:

----
$ lsusb -d 1d50:
Bus 001 Device 042: ID 1d50:6145<1> OpenMoko, Inc. icE1usb
$ sudo dfu-util -d 1d50:6145 -e <2>
...
$ lsusb -d 1d50:
Bus 001 Device 043: ID 1d50:6144<3> OpenMoko, Inc. icE1usb (DFU)
----
<1> initially the device is in normal runtime mode
<2> we use `dfu-util -e` to switch to DFU mode
<3> we can see, the device is now in DFU mode

==== Obtaining firmware upgrades

The latest firmware can be found at
https://ftp.osmocom.org/binaries/icE1usb/firmware/latest/
a backlog of earlier builds can be found at
https://ftp.osmocom.org/binaries/icE1usb/firmware/all/

The latest gateware can currently only be found at the personal developer
directory of tnt at https://people.osmocom.org/tnt/ice1usb/icE1usb-202010-bd399e96.bin
A more official download location for the gateware will be provided shortly.

==== Upgrading the FPGA gateware

Gateware files are called `icE1usb-*.bin`. (without 'fw' in the name)

The gateware can be upgraded by accessing the DFU _altsetting 0_ using `dfu-util` *`-a 0`*

Assuming you already are in DFU mode, you would typically use a command
like `dfu-util -d 1d50:6144 -a 0 -D icE1usb-202010-bd3999e96.bin -R` to perform the upgrade.

NOTE: The `-R` will switch the device back to runtime mode after the
upgrade.   If you want to upgrade the firmware in the same session, skip
the `-R` in the above command.

==== Upgrading the picoRISCV firmware

Firmware files are called `icE1usb-fw*.bin`.

The firmware can be upgraded by accessing the DFU _altsetting 1_ using `dfu-util` *`-a 1`*

Assuming you already are in DFU mode, you would typically use a command
like `dfu-util -d 1d50:6144 -a 1 -D fw_app-202011-4d9a04e2.bin -R` to perform the upgrade.

.Typical output during upgrade of the firmware
----
$ sudo dfu-util -d 1d50:6144 -a 1 -D ./fw_app.bin -R
dfu-util 0.9

Copyright 2005-2009 Weston Schmidt, Harald Welte and OpenMoko Inc.
Copyright 2010-2016 Tormod Volden and Stefan Schmidt
This program is Free Software and has ABSOLUTELY NO WARRANTY
Please report bugs to http://sourceforge.net/p/dfu-util/tickets/

dfu-util: Invalid DFU suffix signature
dfu-util: A valid DFU suffix will be required in a future dfu-util release!!!
Opening DFU capable USB device...
ID 1d50:6144
Run-time device DFU version 0101
Claiming USB DFU Interface...
Setting Alternate Setting #1 ...
Determining device status: state = dfuIDLE, status = 0
dfuIDLE, continuing
DFU mode device DFU version 0101
Device returned transfer size 4096
Copying data from PC to DFU device
Download        [=========================] 100%        11256 bytes
Download done.
state(2) = dfuIDLE, status(0) = No error condition is present
Done!
Resetting USB to switch back to runtime mode
----

As the `-R` option was used, the device will reset and re-enumerate in
the newly programmed firmware.

You can verify this as follows:

----
$ lsusb -d 1d50:
Bus 001 Device 042: ID 1d50:6145 OpenMoko, Inc. icE1usb
----

or alternatively:

----
$ dfu-util -l -d 1d50:
dfu-util 0.9

Copyright 2005-2009 Weston Schmidt, Harald Welte and OpenMoko Inc.
Copyright 2010-2016 Tormod Volden and Stefan Schmidt
This program is Free Software and has ABSOLUTELY NO WARRANTY
Please report bugs to http://sourceforge.net/p/dfu-util/tickets/

Found Runtime: [1d50:6145] ver=0003, devnum=44, cfg=1, intf=1, path="1-2", alt=0, name="DFU runtime", serial="dc697407e7881531"
----

=== Use of the E1 Interface LEDs

Each E1 interface has two LEDs integrated into the RJ45 connector. They
are (starting to get) used by the firmware to indicate status
information to the user.

[options="header"]
|===
| Green LED | Yellow LED | Meaning
| Off       | Off        | Loss of Signal
| Blink     | Off        | Loss of Framing
| Blink     | On         | Loss of Framing, Receiving AIS
| On        | Off        | Aligned
| On        | On         | Aligned, Receiving RAI
|===

=== Use of the Multi-Color RGB LED

The led near the USB port is used to indicate general device status.

A blinking blue led indicates that the device is in bootloader mode.

A slow breathing indicates that at least one of the two port is
active, communicating over USB. The color of the led then indicates
the E1 link status. If all links are without issues, it will be
green, but if at least one of the enabled port has an issue,
it will show up as red.

=== Firmware <-> USB Host Interface

The icE1usb firmware provides a USB 1.1 full-speed (FS) device with

* one configuration
* 5 interfaces
** E1 port 0
** E1 port 1
** CDC-ACM (control + data)
** DFU (device firmware upgrade)

The interfaces have self-explanatory string descriptors like

----
      iInterface              6 E1 port 0
      iInterface              8 E1 port 1
      iInterface              9 GPS (CDC control)
      iInterface             10 GPS (CDC data)
      iInterface             11 DFU runtime
----

==== E1 ports

There are two physical E1 ports in the icE1usb.  Each is exposed via its own USB _interface_.

Each port (USB _interface_) contains two _altsettings_:

* one altsetting with no data endpoints (E1 disabled, this is the default)
* one altsetting with isochronous IN/OUT endpoints (E1 enabled)

In order to activate one E1 port, the driver must perform a USB standard
request to activate the _enabled_ altsetting.

NOTE:: Please note that on many XHCI host controllers there seem to be
implementation flaws in the XHCI host controller firmware preventing the
activation of both icE1usb ports simultaneously.  The XHCI controller
firmware erroneously claims that there is insufficient bus bandwidth.
However, the same icE1usb hardware/firmware works perfectly fine with
OHCI, UHCI and EHCI host controllers.  See
https://osmocom.org/projects/e1-t1-adapter/wiki/Isochronous_USB_Issues for a user-maintained list of USB hosts / controllers and whether or not they work with two E1 ports.

As most modern [PC] hardware has XHCI host controllers, you need to
choose your hardware carefully if concurrent operation of both icE1usb
ports is required in your application.

==== CDC-ACM with GPS NMEA

There's a CDC-ACM (virtual com port) interface available in the icE1usb.
This will be supported by the standard `cdc_acm` driver of your
operating system, and will expose a `/dev/ttyACMx` device on Linux.

The port provides read-only access to the GPS receiver on-board the
icE1usb.  You can use this to

* determine the GPS fix (and hence 1PPS frequency reference)
  availability
* obtain the GPS position of the device

NOTE:: Write access to the GPS receiver is not permitted as the icE1usb
firmware needs to control the GPS receiver for frequency reference
purposes.

==== DFU (Device Firmware Upgrade)

There's a DFU interface available in order to update the icE1usb
gateware and firmware.  For more information, see [[firmware]] above.

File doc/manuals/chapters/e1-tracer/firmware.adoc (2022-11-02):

[[firmware]]
== e1-tracer Firmware

The e1-tracer _firmware_ is a small amount of bare-iron software running
on the picoRISCV soft-core of the _gateware_.

It mainly consists of drivers for the no2e1 E1 Framer IP core and the
no2usb USB Device IP core which are part of the gateware described in
<<gateware>>.

=== Firmware Upgrade (DFU)

e1-tracer contains support for the USB DFU (Device Firmware Upgrade)
standard.

As such, you can use any USB DFU compliant utility to upgrade the
firmware of the e1-tracer device.

DFU mode can be entered in two ways:

1. by performing a DFU detach from the normal application firmware
   (obviously that requires a [still] working firmware present on the
   device).  To do so, please use `dfu-util -e`

2. by pushing the push-button (see <<hw-pushbutton>>) during power-up.
   Simply disconnect the USB cable, then push that button and keep it
   pushed while re-attaching the USB cable.

The e1-tracer boot loader enumerates as VID:PID `1d50:6150`, while the
normal application firmware enumerates as `1d50:6151`,

You can for example use `lsusb` to check the VID:PID:

.Example output of `dfu-util` on a system with e1-tracer attached
----
$ lsusb -d 1d50:
Bus 001 Device 042: ID 1d50:6151<1> OpenMoko, Inc. e1-tracer
$ sudo dfu-util -d 1d50:6151 -e <2>
...
$ lsusb -d 1d50:
Bus 001 Device 043: ID 1d50:6150<3> OpenMoko, Inc. e1-tracer (DFU)
----
<1> initially the device is in normal runtime mode
<2> we use `dfu-util -e` to switch to DFU mode
<3> we can see, the device is now in DFU mode

==== Obtaining firmware upgrades

The latest firmware can be found at
https://ftp.osmocom.org/binaries/e1-tracer/firmware/latest/
a backlog of earlier builds can be found at
https://ftp.osmocom.org/binaries/e1-tracer/firmware/all/

The latest gateware can currently only be found at the personal developer
directory of tnt at https://people.osmocom.org/tnt/e1-tracer/e1-tracer-gw-c7566442.bin
A more official download location for the gateware will be provided shortly.

==== Upgrading the FPGA gateware

Gateware files are called `e1-tracer-gw-*.bin`. (without 'fw' in the name)

The gateware can be upgraded by accessing the DFU _altsetting 0_ using `dfu-util` *`-a 0`*

Assuming you already are in DFU mode, you would typically use a command
like `dfu-util -d 1d50:6150 -a 0 -D e1-tracer-gw-c7566442.bin -R` to perform the upgrade.

NOTE: The `-R` will switch the device back to runtime mode after the
upgrade.   If you want to upgrade the firmware in the same session, skip
the `-R` in the above command.

==== Upgrading the picoRISCV firmware

Firmware files are called `e1_tracer-fw*.bin`.

The firmware can be upgraded by accessing the DFU _altsetting 1_ using `dfu-util` *`-a 1`*

Assuming you already are in DFU mode, you would typically use a command
like `dfu-util -d 1d50:6150 -a 1 -D e1_tracer-fw-0.1-132-ga0df047.bin -R` to perform the upgrade.

.Typical output during upgrade of the firmware
----
$ sudo dfu-util -d 1d50:6150 -a 1 -D e1_tracer-fw-0.1-132-ga0df047.bin -R
dfu-util 0.9

Copyright 2005-2009 Weston Schmidt, Harald Welte and OpenMoko Inc.
Copyright 2010-2016 Tormod Volden and Stefan Schmidt
This program is Free Software and has ABSOLUTELY NO WARRANTY
Please report bugs to http://sourceforge.net/p/dfu-util/tickets/

dfu-util: Invalid DFU suffix signature
dfu-util: A valid DFU suffix will be required in a future dfu-util release!!!
Opening DFU capable USB device...
ID 1d50:6150
Run-time device DFU version 0101
Claiming USB DFU Interface...
Setting Alternate Setting #1 ...
Determining device status: state = dfuIDLE, status = 0
dfuIDLE, continuing
DFU mode device DFU version 0101
Device returned transfer size 4096
Copying data from PC to DFU device
Download        [=========================] 100%        11256 bytes
Download done.
state(2) = dfuIDLE, status(0) = No error condition is present
Done!
Resetting USB to switch back to runtime mode
----

As the `-R` option was used, the device will reset and re-enumerate in
the newly programmed firmware.

You can verify this as follows:

----
$ lsusb -d 1d50:
Bus 001 Device 042: ID 1d50:6151 OpenMoko, Inc. e1-tracer
----

or alternatively:

----
$ dfu-util -l -d 1d50:
dfu-util 0.9

Copyright 2005-2009 Weston Schmidt, Harald Welte and OpenMoko Inc.
Copyright 2010-2016 Tormod Volden and Stefan Schmidt
This program is Free Software and has ABSOLUTELY NO WARRANTY
Please report bugs to http://sourceforge.net/p/dfu-util/tickets/

Found Runtime: [1d50:6151] ver=0003, devnum=44, cfg=1, intf=1, path="1-2", alt=0, name="DFU runtime", serial="dc697407e7881531"
----

=== Use of the LEDs

==== LOS LEDs

Each E1 channel has one red *LOS LED*.  They are red if either

* the E1 framer has not yet been initialized (done by starting host software)
* there is an actual LOS (Loss of Signal) condition in the respective direction

==== Multi-Color RGB STATUS LED

The multi-color RGB *STATUS LED* is used to indicate overall hardware/firmware status.

[options="header",cols="10,10,60"]
|===
|Color  | Pattern         | Meaning
|Red    | On              | E1 interface not active (no host software?)
|Red    | Blinking        | E1 interface active, but error status (CRC, alignment)
|Green  | On              | E1 Receiver B aligned
|Green  | Blinking        | E1 Receiver A attempting to align
|Blue   | On              | E1 Receiver B aligned
|Blue   | Blinking        | E1 Receiver B attempting to align
|Cyan   | On              | E1 Receiver A+B aligned
|Cyan   | Blinking        | E1 Receiver A+B attempting to align
|===

=== Firmware - USB Host Interface

The e1-tracer firmware provides a USB 1.1 full-speed (FS) device with two configurations

* legacy configuration (for use with `e1-tracer-record`)
** 2 interfaces
*** combined interface for both E1 directions
*** DFU (device firmware upgrade)
* `osmo-e1d` compatible configuration
* 2 interfaces
** E1 direction A->B
** E1 direction A<-B

The configurations and interfaces have self-explanatory string descriptors like

----
      iInterface              8 E1 Direction A
      iInterface              9 E1 Direction B
----

==== e1d compatible configuration: E1 ports

There are two physical E1 ports in the e1-tracer.  Each represents one direction
of the traced E1 circuit.  Each is exposed via its own USB _interface_.

Each port/direction (USB _interface_) contains two _altsettings_:

* one altsetting with no data endpoints (E1 tracing disabled, this is the default)
* one altsetting with isochronous IN/OUT endpoints (E1 tracing enabled)

In order to activate one E1 port, the driver must perform a USB standard
request to activate the _enabled_ altsetting.

==== DFU (Device Firmware Upgrade)

There's a DFU interface available in order to update the e1-tracer
gateware and firmware.  For more information, see above.

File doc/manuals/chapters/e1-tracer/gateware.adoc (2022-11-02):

[[gateware]]
== e1-tracer Gateware

The e1-tracer _gateware_ is where pretty much everything happens,
from the E1 Line Interface Unit to the E1 Framer/Deframer, the
picoRISCV soft-core running the [[firmware]] as well as the USB
device peripheral talking to the host PC.

The gateware is stored in binary form on the device-internal
non-volatile memory (SPI flash).  It is field-upgradeable via USB.

As an OSHW project, all of it is available in source code format
at https://git.osmocom.org/osmo-e1-hardware/tree/gateware/e1-tracer

Please use `git clone --recursive` when cloning the git repository
so you get all of the sub-modules for the various soft-cores.

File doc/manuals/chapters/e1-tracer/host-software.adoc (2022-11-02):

== Host Software

Host Software is software running on the USB host computer to which the
e1-tracer is attached.

At the time of this writing, there are two options:

* legcay tools from the `software/e1-tracer` sub-directory of the `osmo-e1-hardware.git` repository
* `osmo-e1d`

=== Legacy Software

The legacy software was the initial software developed for the
e1-tracer.  Its purpose was raw trace recording for later offline
analysis.

The source code of this software can be found in the
`software/e1-tracer` sub-directory of the `osmo-e1-hardware.git`
repository at https://gitea.osmocom.org/retronetworking/osmo-e1-hardware

==== e1-tracer-record

The `e1-tracer-record` program is used to create on-disk recordings of the
full E1 interface in both directions.

You can use `e1-trace-record` to obtain a raw recording using the osmo-e1-tracer.

Once the program is started, it will open the USB device (via libusb), enable it
and subsequently store all received E1 frames to a file on disk.  The disk file format
is a custom format containing chunks of data, each prefixed by a header containing
metadata such as the receive timestamp and the direction of the data.

The program supports the following command line arguments:

.Command line arguments of `e1-tracer-record` program
----
 `-o FILE`  the name of the output file to which the recording is to be stored.
 `-a`       append (instead of overwrite) the output file, if it already exists.
 `-m`       set the PHY into monitor (high-impedance) mode.  You should always enable this.
 `-r`       use SCHED_RR *realtime* scheduling to reduce the likelihood of lost data on overloaded systems
----

A typical invocation of the program would look like this:

 `e1-trace-record -o /tmp/my_recording.e1cap -m -r`

There are some additional low-level tuning parameters (`-n` and `-p`), but you should not need those
under normal operation.

==== e1cap file format

The recording file format consists of *chunks* of data. Each chunk contains a number of E1 frames in one
direction of the line.

The chunk header is prefixed with a 32bit magic value 0xE115600D, followed by two 64bit values as timestamp
(seconds and microseconds), followed by a 16bit length value and an 8 bit USB endpoint number.  The USB
endpoint number signifies the direction; it can be either 0x81 or 0x82.

.Definition of chunk header
----
struct e1_chunk_hdr {
        uint32_t magic;
        struct {
                uint64_t sec;
                uint64_t usec;
        } time;
        int16_t len;
        uint8_t ep;
} __attribute__((packed));
----

After the chunk header is a concatenation of multiple E1 frames, each 32bytes long (one byte for each timeslot
in the frame).

=== `osmo-e1d`

`osmo-e1d` was originally implemented as a host software stack for the
icE1usb E1 USB interface, which is _terminating_ an E1 link and allows
receive and transmit use by external software.

More recently, `osmo-e1d` and the e1-tracer firmware have been made
compatible.  This means that `osmo-e1d` can now be used by applications
to get raw trace data from individual E1 timeslots in real-time using
the same API/interface that was originally designed for icE1usb.

The e1-tracer appears to `osmo-e1d` as one _interface_ which two
_lines_.  Each _line_ represents one direction of the E1
traffic.

In theory, `osmo-e1d` should work on any operating system with libusb
support for isochronous transfers.  However, official support is limited
to GNU/Linux at this point.

More information about `osmo-e1d` can be found at its homepage
https://osmocom.org/projects/osmo-e1d/wiki

==== Example osmo-e1d configuration / start-up

.Sample config file (pass as `-c /path/to/my/osmo-e1d.cfg` when starting osmo-e1d)
----
log stderr
 logging filter all 1
 logging color 1
 logging print category-hex 0
 logging print category 1
 logging print level 1
 logging timestamp 0
 logging print file 1 last
 logging level e1d info
 logging level linp info
e1d
----

.Sample output of osmo-e1d starting with above config file and one e1-tracer attached to USB
----
DLGLOBAL NOTICE Available via telnet 127.0.0.1 4269 (telnet_interface.c:100)
DE1D NOTICE No configuration for e1-tracer serial 'dc696c80532f7d34' found, auto-generating it (usb.c:868)
DE1D NOTICE (I0) Created (intf_line.c:184)
DE1D NOTICE (I0:L0) Created (intf_line.c:285)
DE1D NOTICE (I0:L0) Activated (intf_line.c:319)
DE1D NOTICE (I0:L1) Created (intf_line.c:285)
DE1D NOTICE (I0:L1) Activated (intf_line.c:319)
----

This means that a single e1-tracer device was found, and that it has been designated *interface 0* with *line 0* and *line 1* within that interface.

You can introspect the `osmo-e1d` state using its VTY interface:

.Example VTY output when telnet-ing into the osmo-e1d VTY port 4269
----
$ telnet localhost 4269
Trying 127.0.0.1...
Connected to localhost.
Escape character is '^]'.
Welcome to the osmo-e1d VTY interface

(C) 2019-2022 by Sylvain Munaut, Harald Welte and contributors
osmo-e1d> show line <1>
Interface #0 (dc696c80532f7d34), Line #0, Mode CHANNELIZED:
 TS00: Mode off, FD -1, Peer PID -1
 TS01: Mode off, FD -1, Peer PID -1
 TS02: Mode off, FD -1, Peer PID -1
 TS03: Mode off, FD -1, Peer PID -1
 TS04: Mode off, FD -1, Peer PID -1
 TS05: Mode off, FD -1, Peer PID -1
 TS06: Mode off, FD -1, Peer PID -1
 TS07: Mode off, FD -1, Peer PID -1
 TS08: Mode off, FD -1, Peer PID -1
 TS09: Mode off, FD -1, Peer PID -1
 TS10: Mode off, FD -1, Peer PID -1
 TS11: Mode off, FD -1, Peer PID -1
 TS12: Mode off, FD -1, Peer PID -1
 TS13: Mode off, FD -1, Peer PID -1
 TS14: Mode off, FD -1, Peer PID -1
 TS15: Mode off, FD -1, Peer PID -1
 TS16: Mode off, FD -1, Peer PID -1
 TS17: Mode off, FD -1, Peer PID -1
 TS18: Mode off, FD -1, Peer PID -1
 TS19: Mode off, FD -1, Peer PID -1
 TS20: Mode off, FD -1, Peer PID -1
 TS21: Mode off, FD -1, Peer PID -1
 TS22: Mode off, FD -1, Peer PID -1
 TS23: Mode off, FD -1, Peer PID -1
 TS24: Mode off, FD -1, Peer PID -1
 TS25: Mode off, FD -1, Peer PID -1
 TS26: Mode off, FD -1, Peer PID -1
 TS27: Mode off, FD -1, Peer PID -1
 TS28: Mode off, FD -1, Peer PID -1
 TS29: Mode off, FD -1, Peer PID -1
 TS30: Mode off, FD -1, Peer PID -1
 TS31: Mode off, FD -1, Peer PID -1
 Counters for each line in e1d:
  Rx Signal Lost:        0 (0/s 0/m 0/h 0/d)
  Rx Alignment Lost:        0 (0/s 0/m 0/h 0/d)
  E1 Rx CRC Errors:        0 (0/s 0/m 0/h 0/d)
  E1 Rx Overflow:        0 (0/s 0/m 0/h 0/d)
  E1 Tx Underflow:        0 (0/s 0/m 0/h 0/d)
  Rx Frames Reporting Remote CRC Error:        0 (0/s 0/m 0/h 0/d)
  Rx Frames Reporting Remote Alarm:        0 (0/s 0/m 0/h 0/d)
  E1 Tx Frames multiplexed:        0 (0/s 0/m 0/h 0/d)
  E1 Rx Frames demultiplexed:   143680 (8000/s 142560/m 0/h 0/d)
Interface #0 (dc696c80532f7d34), Line #1, Mode CHANNELIZED:
 TS00: Mode off, FD -1, Peer PID -1
 TS01: Mode off, FD -1, Peer PID -1
 TS02: Mode off, FD -1, Peer PID -1
 TS03: Mode off, FD -1, Peer PID -1
 TS04: Mode off, FD -1, Peer PID -1
 TS05: Mode off, FD -1, Peer PID -1
 TS06: Mode off, FD -1, Peer PID -1
 TS07: Mode off, FD -1, Peer PID -1
 TS08: Mode off, FD -1, Peer PID -1
 TS09: Mode off, FD -1, Peer PID -1
 TS10: Mode off, FD -1, Peer PID -1
 TS11: Mode off, FD -1, Peer PID -1
 TS12: Mode off, FD -1, Peer PID -1
 TS13: Mode off, FD -1, Peer PID -1
 TS14: Mode off, FD -1, Peer PID -1
 TS15: Mode off, FD -1, Peer PID -1
 TS16: Mode off, FD -1, Peer PID -1
 TS17: Mode off, FD -1, Peer PID -1
 TS18: Mode off, FD -1, Peer PID -1
 TS19: Mode off, FD -1, Peer PID -1
 TS20: Mode off, FD -1, Peer PID -1
 TS21: Mode off, FD -1, Peer PID -1
 TS22: Mode off, FD -1, Peer PID -1
 TS23: Mode off, FD -1, Peer PID -1
 TS24: Mode off, FD -1, Peer PID -1
 TS25: Mode off, FD -1, Peer PID -1
 TS26: Mode off, FD -1, Peer PID -1
 TS27: Mode off, FD -1, Peer PID -1
 TS28: Mode off, FD -1, Peer PID -1
 TS29: Mode off, FD -1, Peer PID -1
 TS30: Mode off, FD -1, Peer PID -1
 TS31: Mode off, FD -1, Peer PID -1
 Counters for each line in e1d:
  Rx Signal Lost:        0 (0/s 0/m 0/h 0/d)
  Rx Alignment Lost:        0 (0/s 0/m 0/h 0/d)
  E1 Rx CRC Errors:        0 (0/s 0/m 0/h 0/d)
  E1 Rx Overflow:        0 (0/s 0/m 0/h 0/d)
  E1 Tx Underflow:        0 (0/s 0/m 0/h 0/d)
  Rx Frames Reporting Remote CRC Error:        0 (0/s 0/m 0/h 0/d)
  Rx Frames Reporting Remote Alarm:        0 (0/s 0/m 0/h 0/d)
  E1 Tx Frames multiplexed:        0 (0/s 0/m 0/h 0/d)
  E1 Rx Frames demultiplexed:   143648 (8000/s 142560/m 0/h 0/d)
----
<1> typing `show line` will produce the below output, indicating that all timeslots are currently _off_ and 8000 E1 frames per second are received from both lines (i.e. directions)

Other applications on the system can not connect to `osmo-e1d` and open individual timeslots either in _RAW_ or in _HDLC-FCS_ mode.

An example program is included, it is called `osmo-e1d-pipe`.  Using this program, you can get a raw output of an individual timeslot.

.Command line reference of `osmo-e1d-pipe` utility
----
$ ./osmo-e1d-pipe --help
 -h --help                     This help message
 -p --path PATH                Path of the osmo-e1d control socket
 -i --interface <0-255>        E1 Interface Number
 -l --line <0-255>             E1 Line Number
 -t --timeslot <0-31>          E1 Timeslot Number
 -m --mode (RAW|HDLC-FCS)      E1 Timeslot Mode
 -f --force                    Force open of the timeslot (may disconnect other client)
 -r --read FILE                Read from FILE instead of STDIN
----

.Sample output of one direction of a raw B-channel
----
$./osmo-e1d-pipe -i 0 -l 0 -t 3 -m RAW -r /dev/zero | hexdump -v
0000000 d5d5 d5d5 d5d5 d5d5 d5d5 d5d5 d5d5 d5d5
0000010 d5d5 d5d5 d5d5 d5d5 d5d5 d5d5 d5d5 d5d5
0000020 d5d5 d5d5 d5d5 d5d5 d5d5 d5d5 d5d5 d5d5
0000030 d5d5 d5d5 d5d5 d5d5 d5d5 d5d5 d5d5 d5d5
0000040 d5d5 d5d5 d5d5 d5d5 d5d5 d5d5 d5d5 d5d5
0000050 d5d5 d5d5 d5d5 d5d5 d5d5 d5d5 d5d5 d5d5
0000060 d5d5 d5d5 d5d5 d5d5 d5d5 d5d5 d5d5 d5d5
0000070 d5d5 d5d5 d5d5 d5d5 d5d5 d5d5 d5d5 d5d5
0000080 d5d5 d5d5 d5d5 d5d5 d5d5 d5d5 d5d5 d5d5
0000090 d5d5 d5d5 d5d5 d5d5 d5d5 d5d5 d5d5 d5d5
00000a0 d5d5 d5d5 d5d5 d5d5 d5d5 d5d5 d5d5 d5d5
...
----

.Sample output of one direction of a HDLC-FCS D-channel
----
$ ./osmo-e1d-pipe -i 0 -l 1 -t 16 -m hdlc-fcs -r /dev/zero | hexdump -v
0000000 0102 027f 7f01 0102 027f 7f01 0102 027f
0000010 7f01 0102 027f 7f01 0102 027f 7f01 0102
0000020 027f 7f01 0102 027f 7f01 0102 027f 7f01
0000030 0102 027f 7f01 0102 027f 7f01 0102 027f
0000040 7f01 0102 027f 7f01 0102 027f 7f01 0102
----

=== Other / 3rd party software

you can interface 3rd party applications with osmo-e1d in the following
mutually exclusive ways:

* by adding support for `osmo-e1d`, e.g. via `libosmo-e1d` to the
  respective application.  This way your application can receive traffic
  one a per-timeslot basis.
* by directly implementing the USB protocol exposed by e1-tracer in your
  software.  This is definitely more effort, as you have to parse the
  entire E1 frames, implement software HDLC decoders, etc. - all of
  which are already present in `osmo-e1d`
* by post-processing the raw disk recordings generated by the
  `e1-trace-recorder` program.

Should you require any related development/porting services, please do
not hesitate to reach out to sysmocom.

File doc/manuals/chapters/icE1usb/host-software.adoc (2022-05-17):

== Host Software

Host Software is software running on the USB host computer to which the
icE1usb is attached.

At the time of this writing, there are two options for icE1usb driver interfaces:
`osmo-e1d` and `DAHDI`.

=== `osmo-e1d`

`osmo-e1d` is a pure user-space driver, not requiring any specific Linux kernel,
kernel patches or out-of-tree kernel modules.  It utilizes `libusb` to
talk to the icE1usb hardware and offers a unix domain socket based
interface to application software.

In theory, `osmo-e1d` should work on any operating system with libusb
support for isochronous transfers.  However, official support is limited
to GNU/Linux at this point.

Software such as `osmo-bsc` and `osmo-mgw` can interface `osmo-e1d` via
the `libosmo-abis` support for `osmo-e1d`.

More information about `osmo-e1d` can be found at its homepage
https://osmocom.org/projects/osmo-e1d/wiki

=== DAHDI driver

DAHDI (Digium Asterisk Hardware Driver Interface) is an extremely
popular driver for a variety of POTS/PSTN and also TDM interface boards
by originally Zaptel, later Digium and now most recently Sangoma.

DAHDI is available only for Linux, and is provided as source code for a
set of out-of-tree kernel modules.  You must compile those modules for
each specific Linux kernel version you are using.  Keep this in mind
when performing kernel upgrades and the like.

DAHDI is supported by a wide range of open source PBX / softswitch software,
including Asterisk, FreeSWITCH and yate.

There is a DAHDI driver for the icE1usb available from
the `laforge/icE1usb` branch of the https://github.com/osmocom/dahdi-linux
git repository.

When using that DAHDI Linux kernel driver, there is no need for
osmo-e1d.  The USB interface is directly managed inside the kernel.

==== Installing DAHDI driver
Example installation steps, tested on Debian 11, for installing DAHDI Linux & DAHDI Tools.
Note: Plugging in the device prior to installing may lead to issues.

----
$ sudo apt-get install -y linux-headers-`uname -r` git dfu-util make gcc autoconf libtool libnewt-dev
$ git clone https://git.osmocom.org/dahdi-linux/
$ git clone https://github.com/asterisk/dahdi-tools
$ cd dahdi-linux
$ sudo make install
$ cd ../dahdi-tools
$ sudo autoreconf -i
$ ./configure
$ sudo make install
$ sudo make install-config
$ sudo modprobe icE1usb
$ sudo /etc/init.d/dahdi start
----

At this point you can plug in the icE1usb, which

* should make the icE1usb enumerate on USB (dmesg, lsusb)
* should and scan for it with `sudo dahdi_scan` which should list the two E1 ports on the iCE1usb.
* see a `/proc/dahdi/N` file (with N being the span number, typically 1 unless you have other spans)
* see the device listed in `dahdi_scan` or `dahdi_tool`

.Example `dmesg` output when icE1usb is plugged in
----
usb 2-1: new full-speed USB device number 5 using xhci_hcd
usb 2-1: New USB device found, idVendor=1d50, idProduct=6145, bcdDevice= 0.03
usb 2-1: New USB device strings: Mfr=2, Product=3, SerialNumber=1
usb 2-1: Product: icE1usb
usb 2-1: Manufacturer: osmocom
usb 2-1: SerialNumber: dc697407e7682731
----

.Example `lsusb` output after icE1usb is plugged in
----
$ lsusb -d 1d50:
Bus 002 Device 005: ID 1d50:6145 OpenMoko, Inc. icE1usb
----

=== Other software

you can interface 3rd party applications with osmo-e1d in the following
ways:

* by adding support for `osmo-e1d`, e.g. via `libosmo-e1d` to the
  respective application
* by directly implementing the USB interface exposed by icE1usb in your
  software

Should you require any related development/porting services, please do
not hesitate to reach out to sysmocom.

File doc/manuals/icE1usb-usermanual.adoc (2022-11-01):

:gfdl-enabled:

icE1usb User Manual
===================
Harald Welte <hwelte@sysmocom.de>

include::./common/chapters/preface.adoc[]

include::./chapters/icE1usb/hardware.adoc[]

include::./chapters/icE1usb/gateware.adoc[]

include::./chapters/icE1usb/firmware.adoc[]

include::./chapters/icE1usb/host-software.adoc[]

include::./common/chapters/gfdl.adoc[]

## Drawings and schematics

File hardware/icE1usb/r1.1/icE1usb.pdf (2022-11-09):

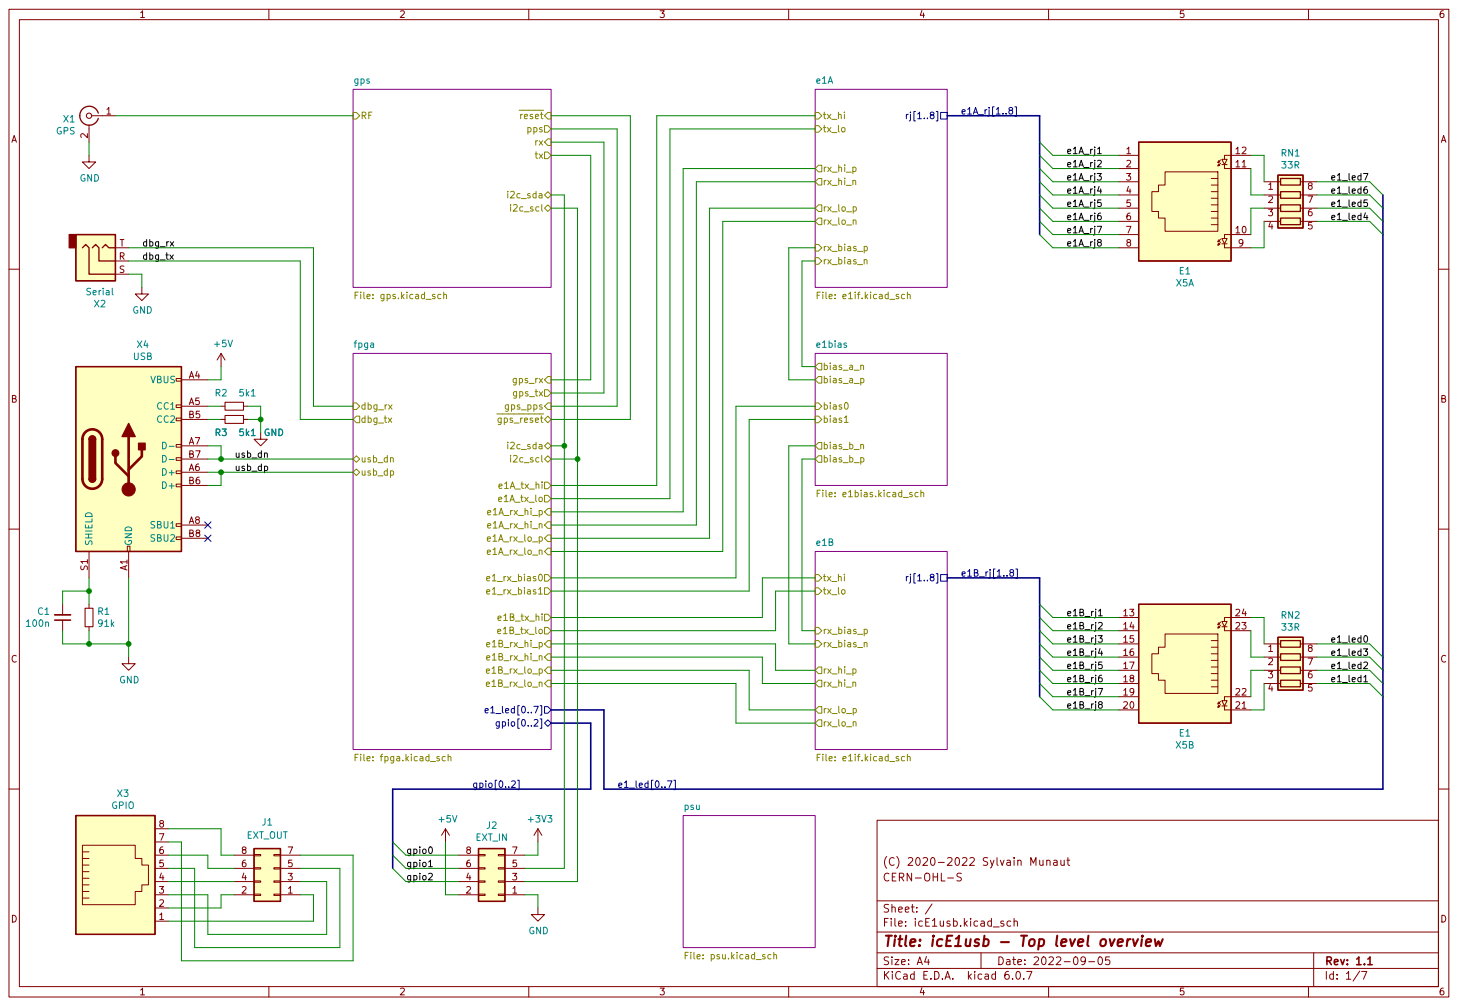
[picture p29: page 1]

(C) 2020-2022 Sylvain Munaut
File: icE1usb.kicad_sch Sheet: / CERN-OHL-S

Id: 1/7 Title: icE1usb - Top level overview

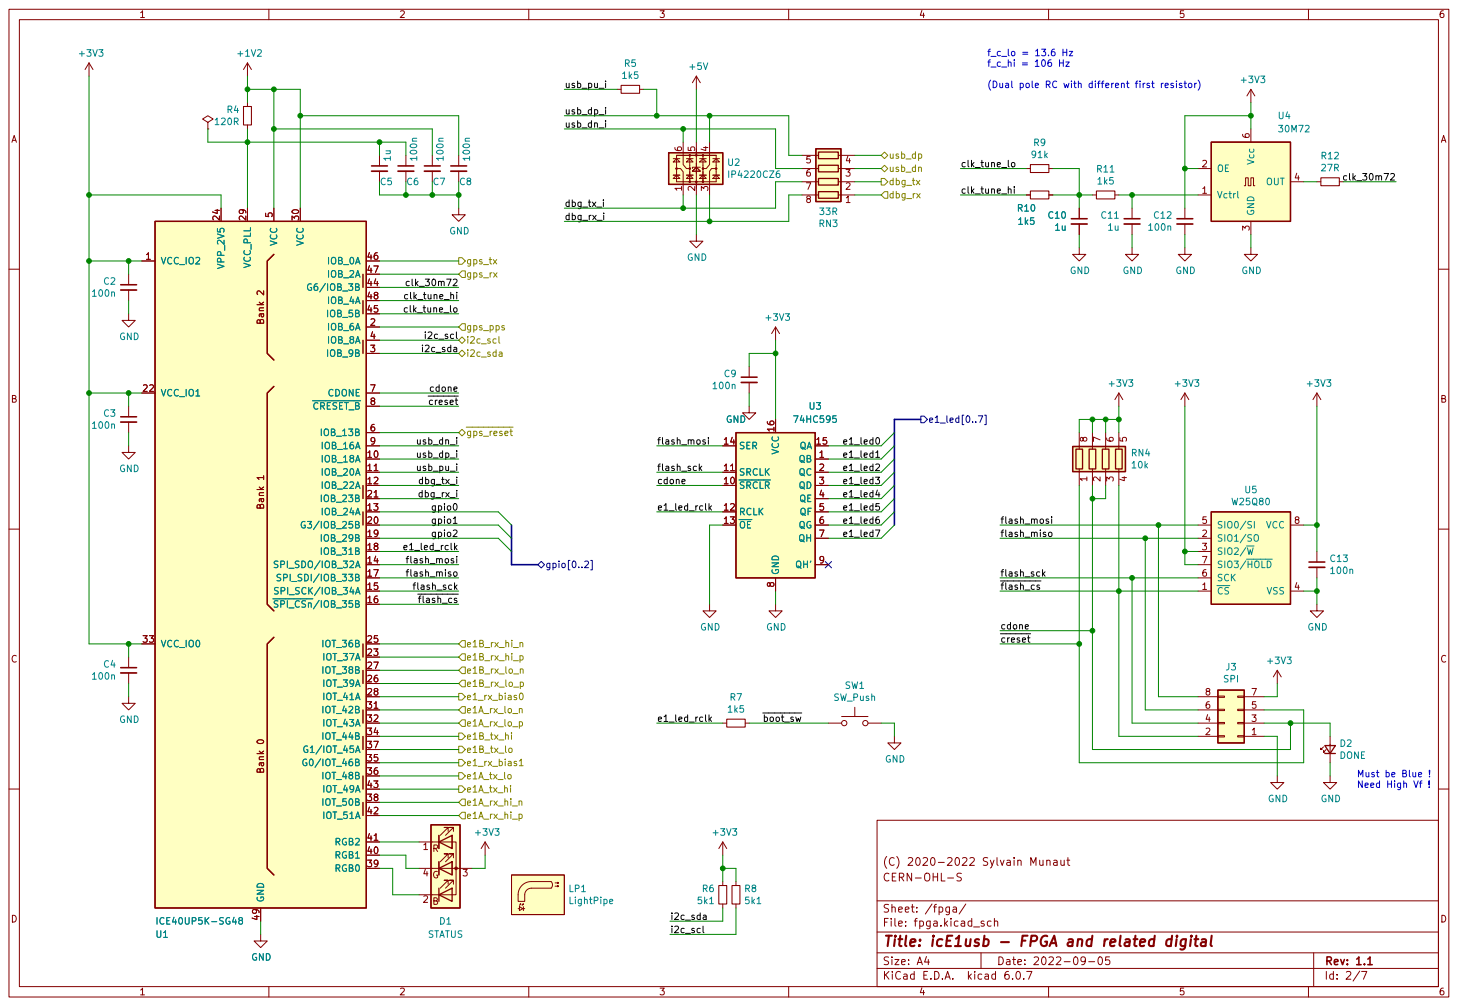
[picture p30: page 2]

(C) 2020-2022 Sylvain Munaut
Sheet: /fpga/ CERN-OHL-S

File: fpga.kicad_sch
Id: 2/7 Title: icE1usb - FPGA and related digital

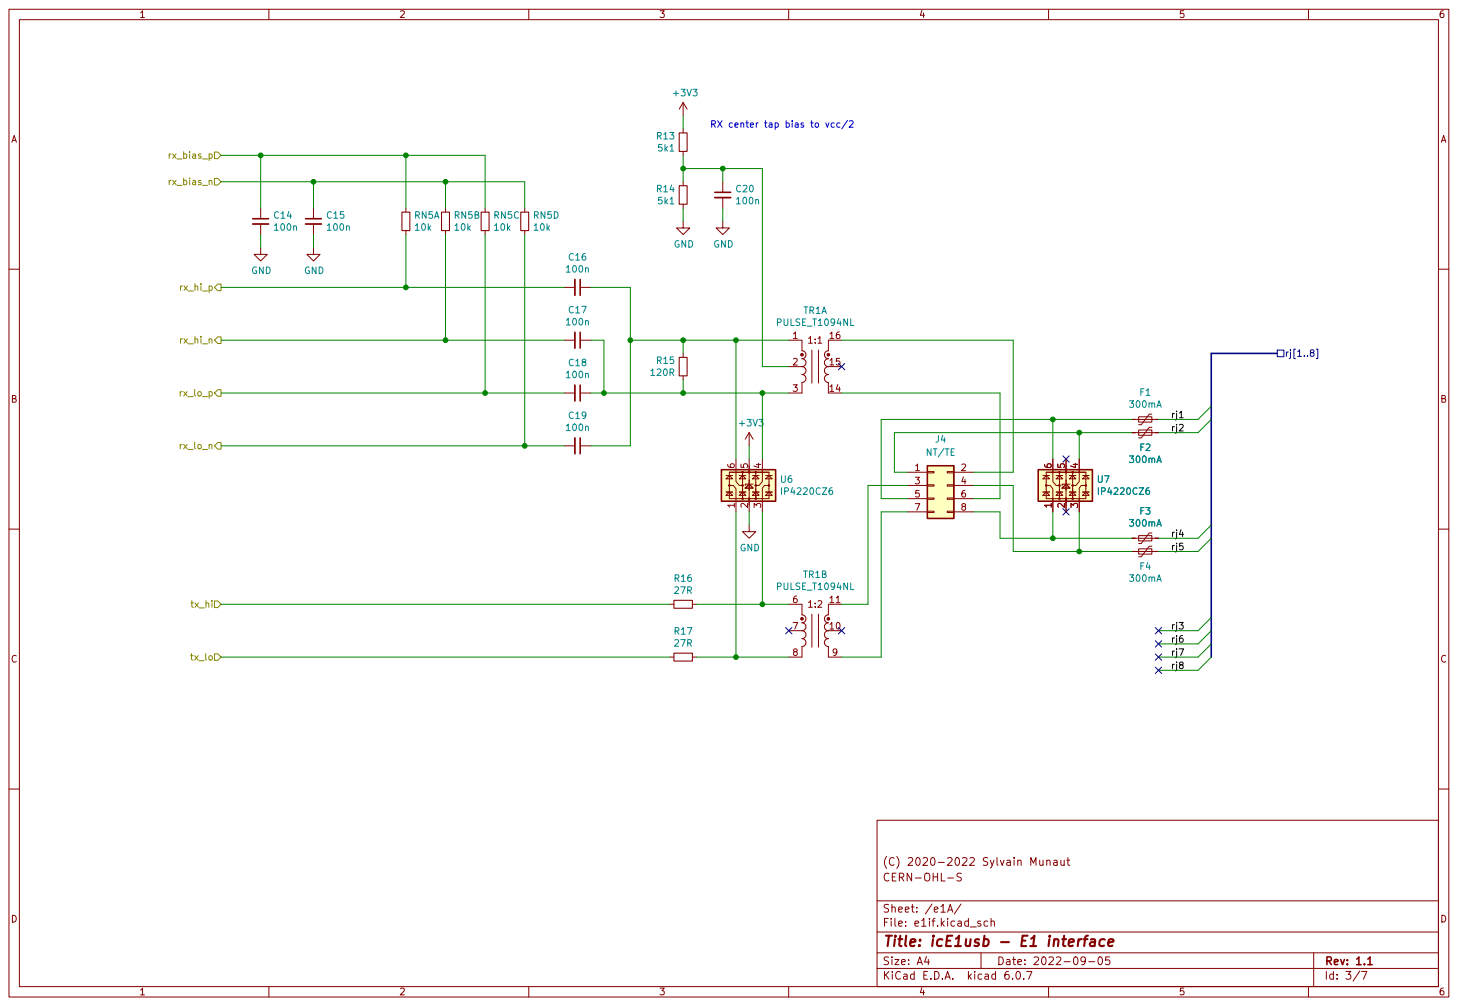
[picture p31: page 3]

(C) 2020-2022 Sylvain Munaut
File: e1if.kicad_sch Sheet: /e1A/ CERN-OHL-S

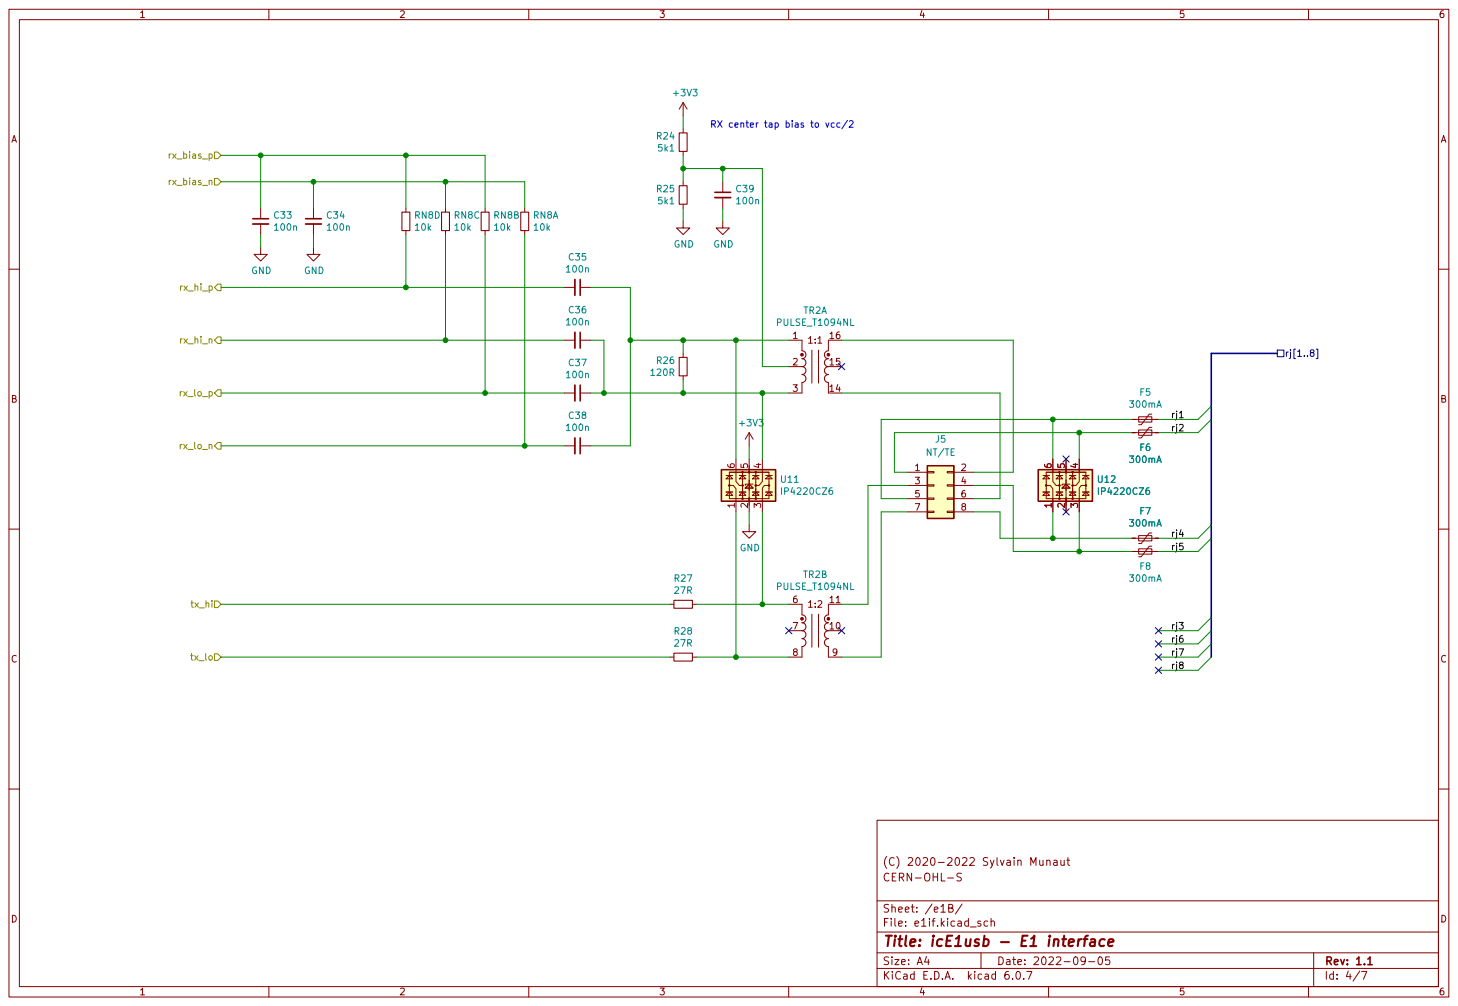
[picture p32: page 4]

(C) 2020-2022 Sylvain Munaut
File: e1if.kicad_sch Sheet: /e1B/ CERN-OHL-S

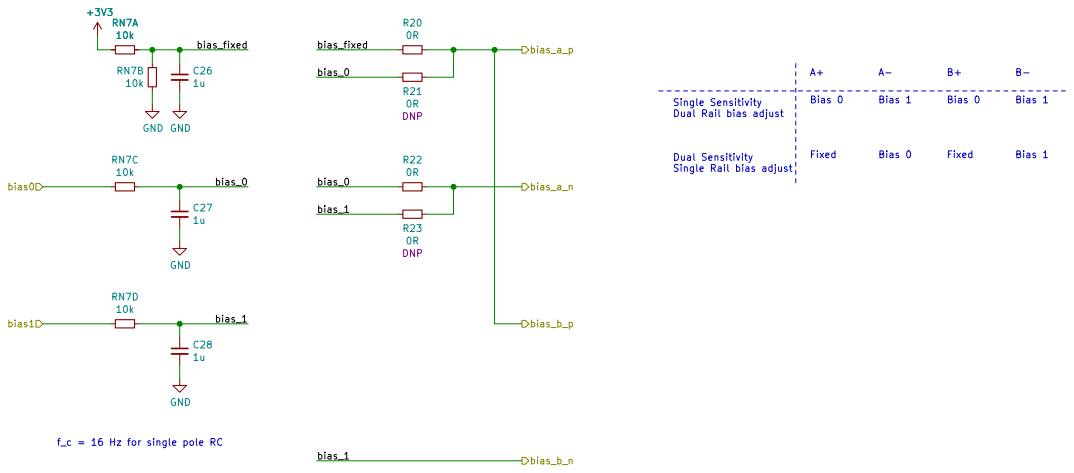
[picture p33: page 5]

f_c = 16 Hz for single pole RC

File: e1bias.kicad_sch Sheet: /e1bias/ CERN-OHL-S

Id: 5/7 Title: icE1usb - E1 interface bias generation

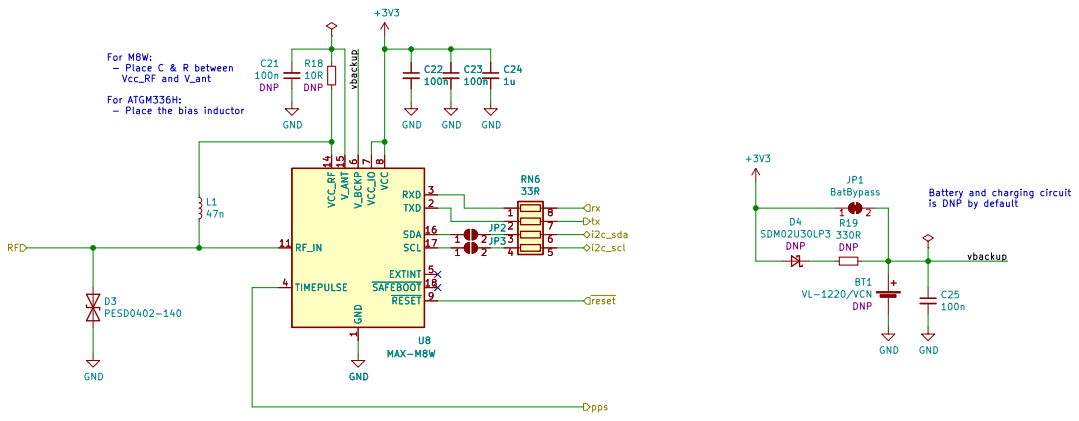
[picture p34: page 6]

is DNP by default For M8W:
- Place C & R between
100n DNP GND GND
Vcc_RF and V_ant For ATGM336H:

1 RF_IN 11 VCC_RF 14 V_ANT 15 SDA 16 SCL 17 ~{SAFEBOOT}18 TXD 2 RXD 3 TIMEPULSE 4 EXTINT 5 V_BCKP

Battery and charging circuit

(C) 2020-2022 Sylvain Munaut
Sheet: /gps/ CERN-OHL-S

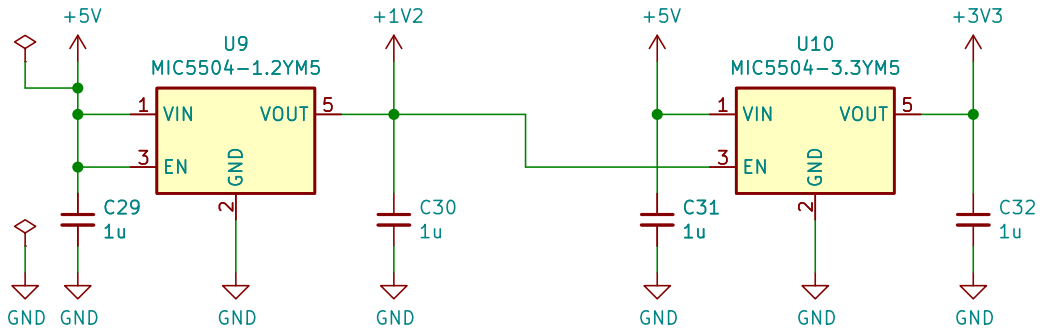
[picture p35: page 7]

Sheet: /psu/ CERN-OHL-S

File: psu.kicad_sch
Id: 7/7 Title: icE1usb - Power Supply

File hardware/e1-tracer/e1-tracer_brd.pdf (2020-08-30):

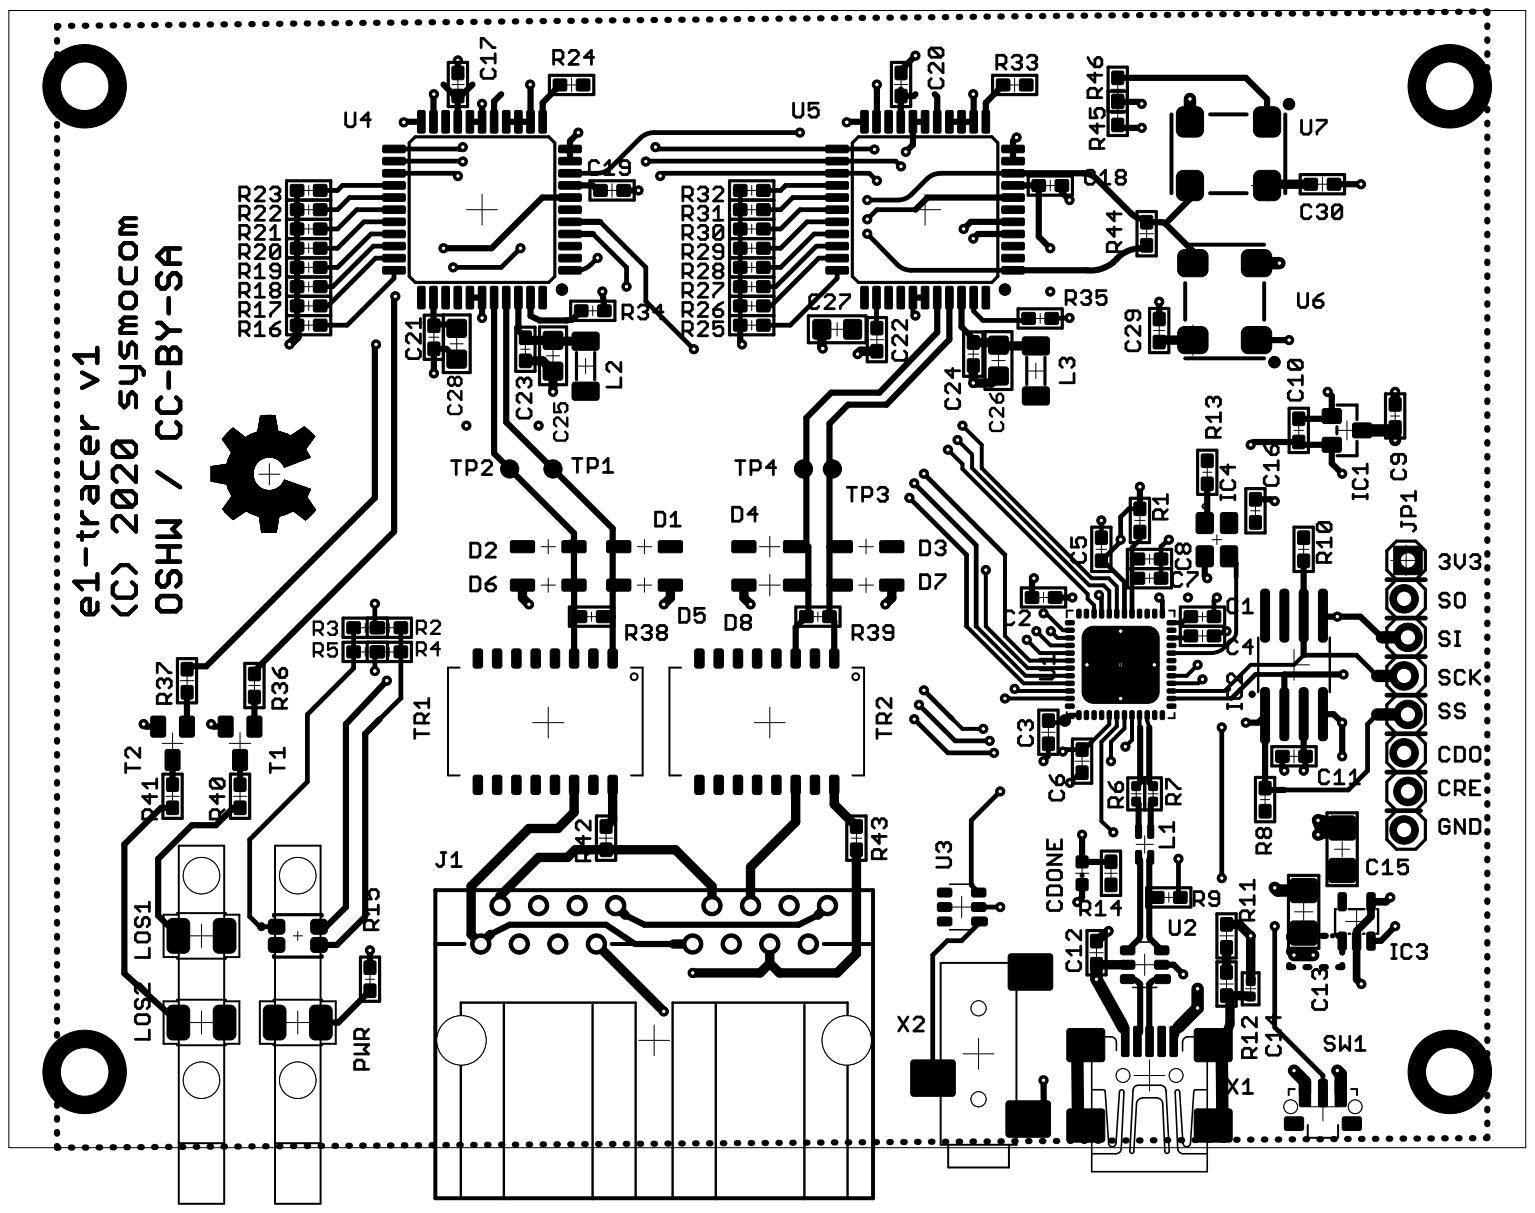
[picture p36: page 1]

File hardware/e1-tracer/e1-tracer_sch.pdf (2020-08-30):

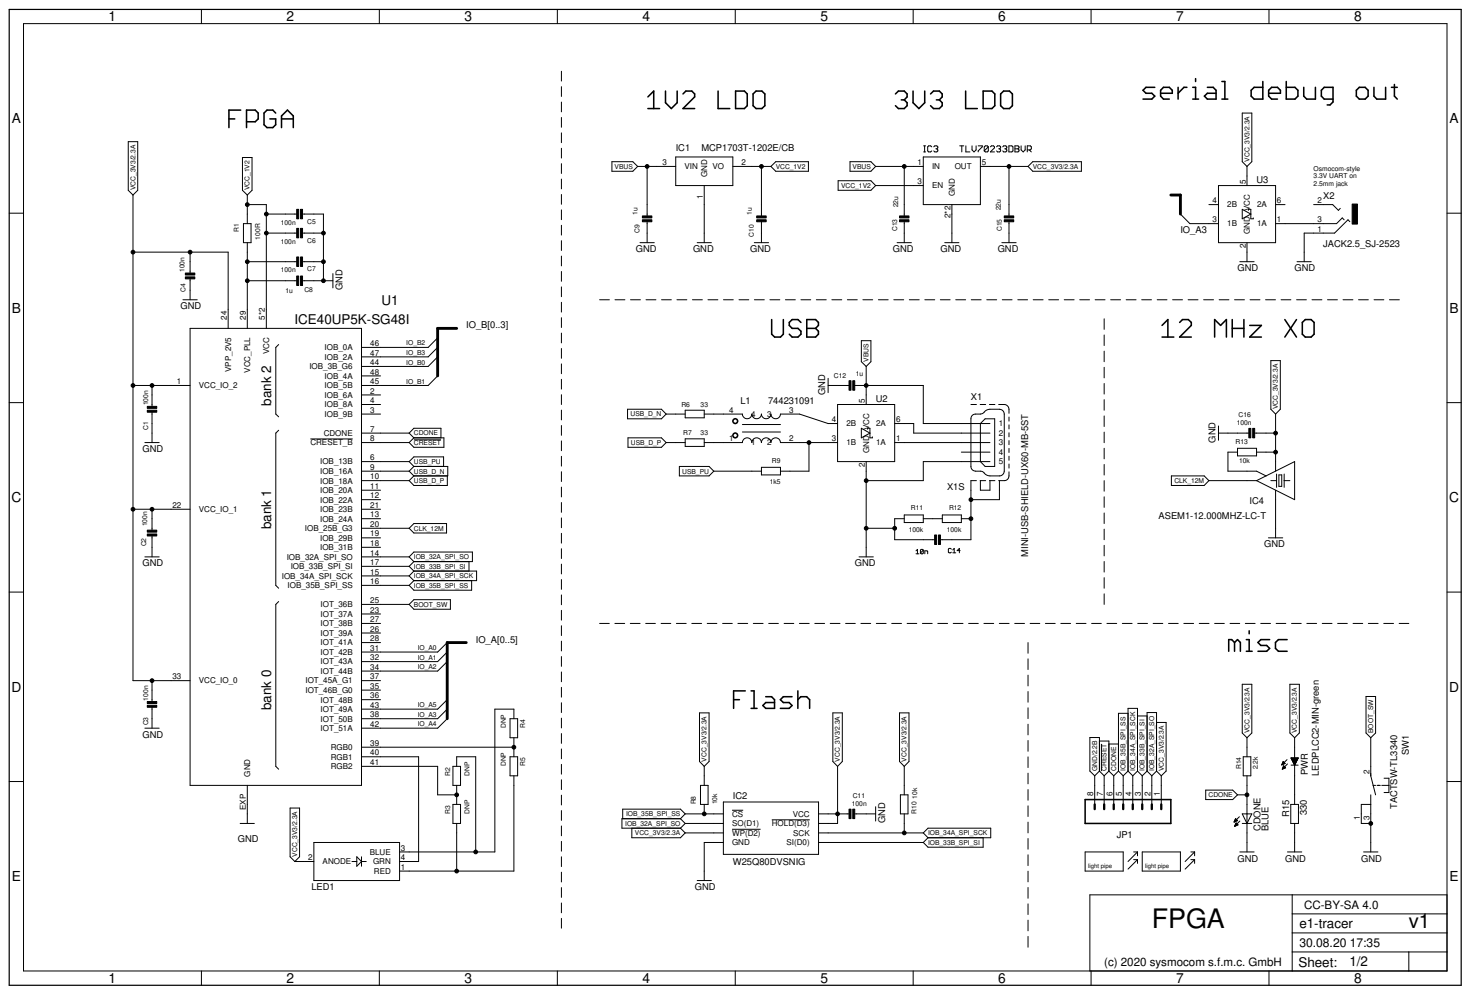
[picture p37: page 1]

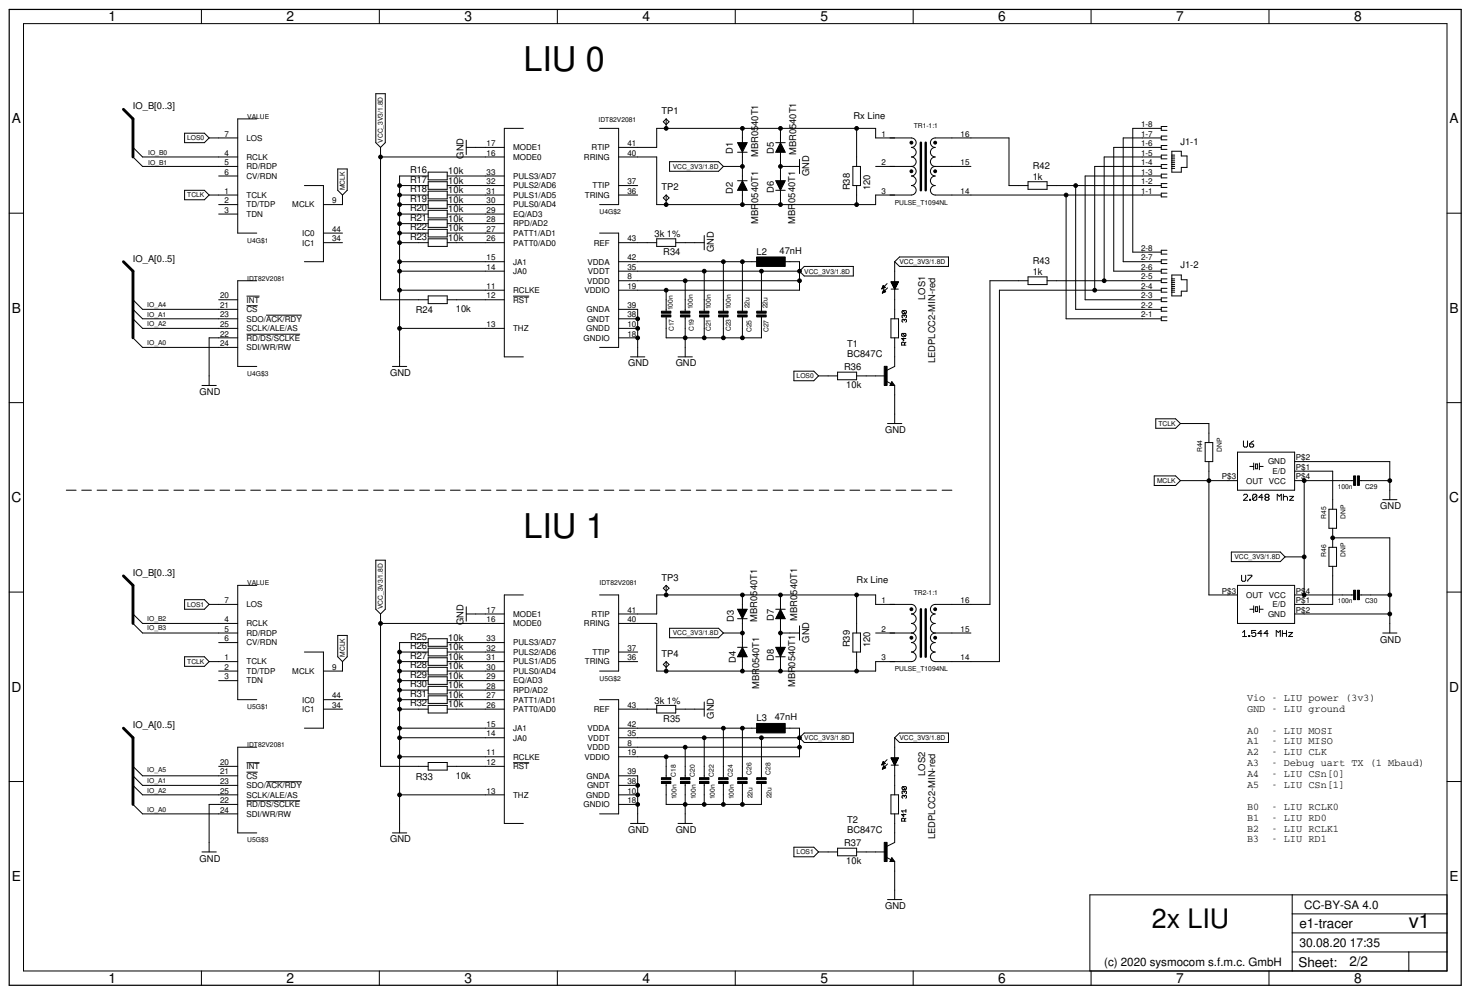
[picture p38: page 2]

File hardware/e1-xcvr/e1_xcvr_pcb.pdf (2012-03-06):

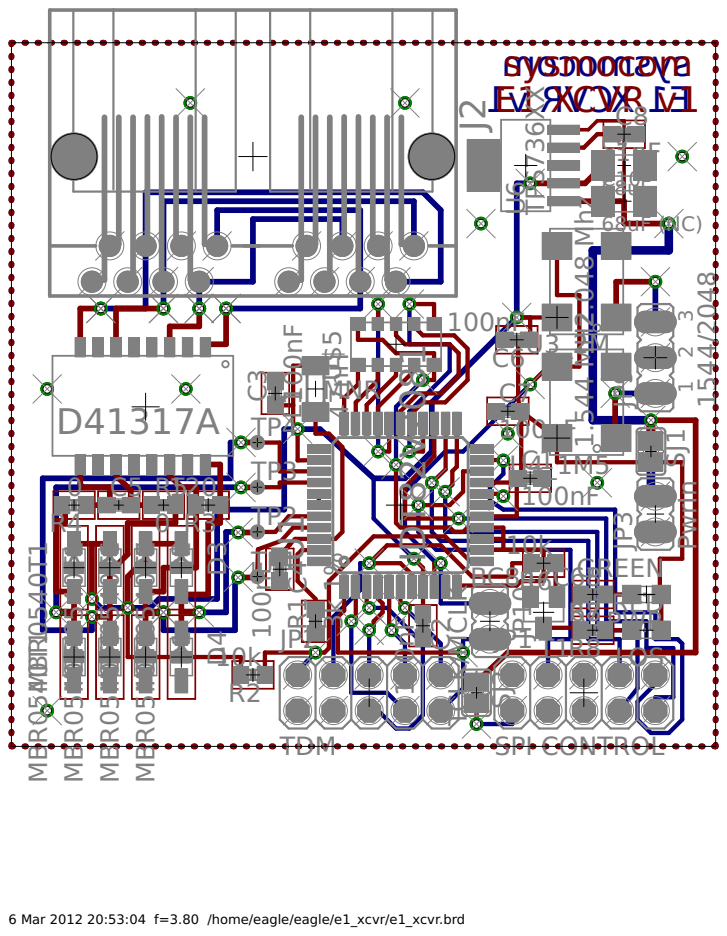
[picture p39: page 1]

6 Mar 2012 20:53:04 f=3.80 /home/eagle/eagle/e1_xcvr/e1_xcvr.brd

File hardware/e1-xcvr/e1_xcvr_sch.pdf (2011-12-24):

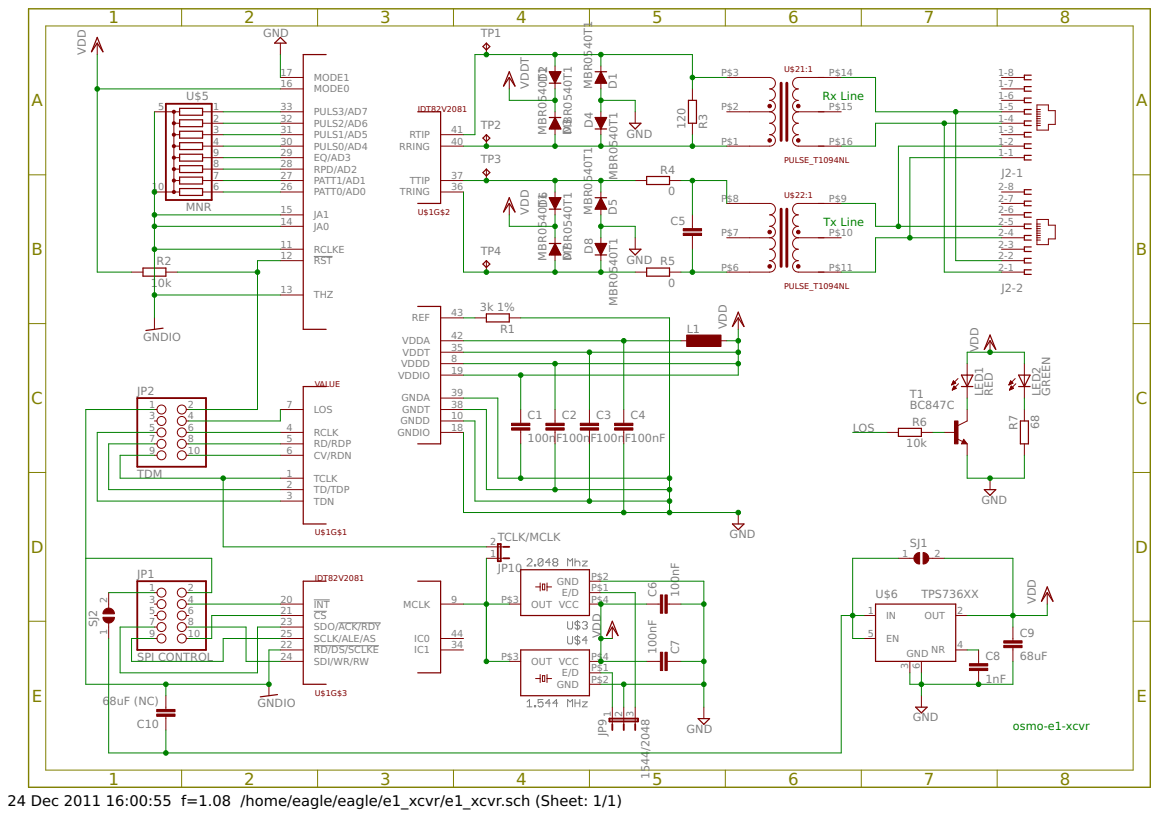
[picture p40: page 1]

24 Dec 2011 16:00:55 f=1.08 /home/eagle/eagle/e1_xcvr/e1_xcvr.sch (Sheet: 1/1)

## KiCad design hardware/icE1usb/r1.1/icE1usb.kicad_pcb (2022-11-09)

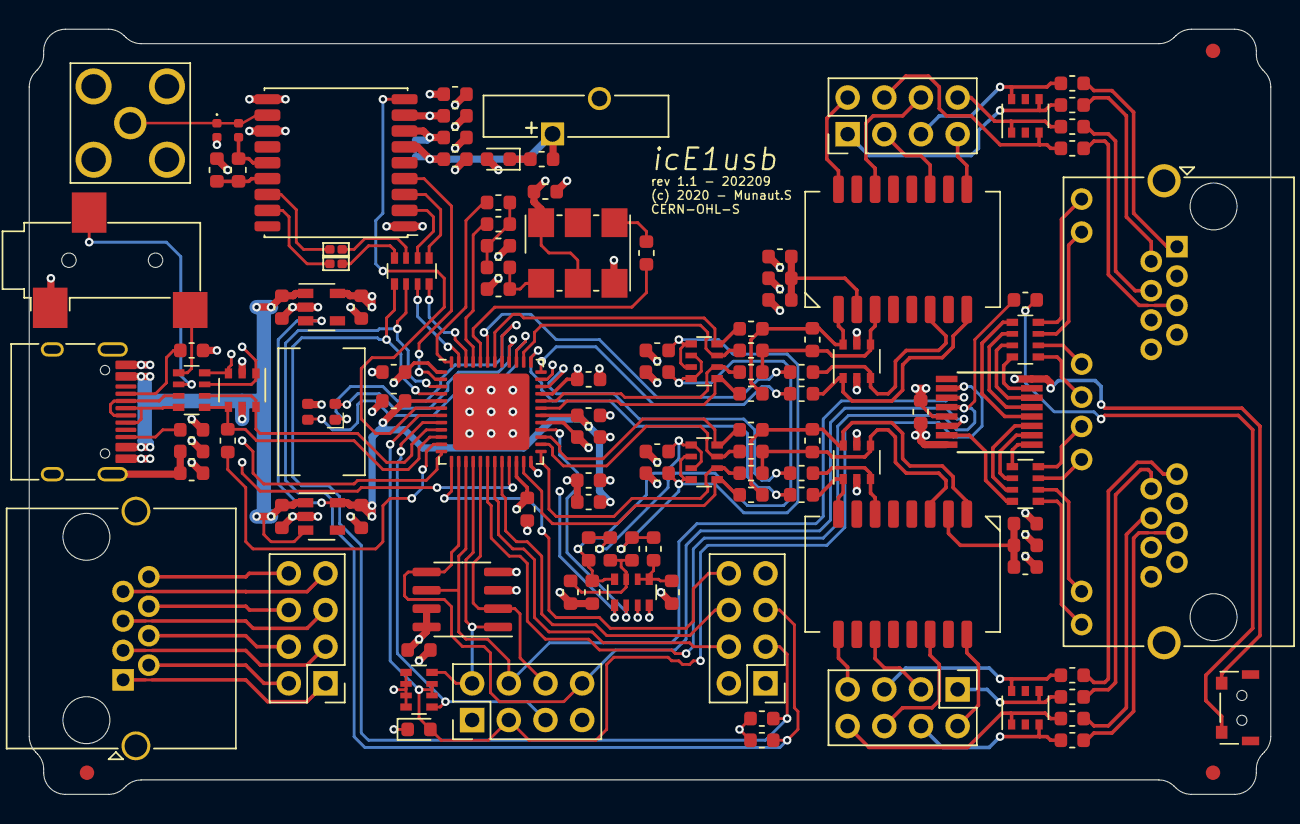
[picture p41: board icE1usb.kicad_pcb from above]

Board: 4 copper layers, 86.0 x 53.0 mm, 121 parts (1 on the bottom side), 131 nets.

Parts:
BT1: VL-1220/VCN; Battery_Panasonic_CR1220-VCN_Vertical_CircularHoles
C1, C2, C3, C4, C6, C7, C8, C9, C12, C13, C14, C15, C16, C17, C18, C19, C20, C21, C22, C23, C25, C33, C34, C35, C36, C37, C38, C39: 100n; C_0603_1608Metric
C5, C10, C11, C24, C26, C27, C28, C29, C30, C31, C32: 1u; C_0603_1608Metric
D1: STATUS; LED_RGB_2020
D2: DONE; LED_0603_1608Metric
D3: PESD0402-140; D_0402_1005Metric
D4: SDM02U30LP3; D_0603_1608Metric
F1, F2, F3, F4, F5, F6, F7, F8: 300mA; Fuse_0603_1608Metric
FID_BL: Fiducial_1mm_Mask2mm
FID_BR: Fiducial_1mm_Mask2mm
FID_TR: Fiducial_1mm_Mask2mm
J1: EXT_OUT; PinHeader_2x04_P2.54mm_Vertical
J2: EXT_IN; PinHeader_2x04_P2.54mm_Vertical
J3: SPI; PinHeader_2x04_P2.54mm_Vertical
J4, J5: NT/TE; PinHeader_2x04_P2.54mm_Vertical
JP1: BatBypass; J_NC_0603_30
JP2: GPS SDA; J_0402
JP3: GPS SCL; J_0402
L1: 47n; L_0402_1005Metric
LP1: LightPipe; LUMEX_LPF-C011303S
R1, R9: 91k; R_0603_1608Metric
R2, R3, R6, R8, R13, R14, R24, R25: 5k1; R_0603_1608Metric
R4, R15, R26: 120R; R_0603_1608Metric
R5, R7, R10, R11: 1k5; R_0603_1608Metric
R12, R16, R17, R27, R28: 27R; R_0603_1608Metric
R18: 10R; R_0603_1608Metric
R19: 330R; R_0603_1608Metric
R20, R21, R22, R23: 0R; R_0603_1608Metric
RN1, RN2, RN3, RN6: 33R; R_Array_Convex_4x0603
RN4, RN5, RN7, RN8: 10k; R_Array_Convex_4x0603
SW1: SW_Push; SW_HYP_1TS003B
TR1, TR2: PULSE_T1094NL; PULSE_BH
U1: ICE40UP5K-SG48; QFN-48-1EP_7x7mm_P0.5mm_EP5.3x5.3mm
U2, U6, U7, U11, U12: IP4220CZ6; TSOP-6_1.65x3.05mm_P0.95mm
U3: 74HC595; TSSOP-16_4.4x5mm_P0.65mm
U4: 30M72; Oscillator_SMD_VCXO-6Pin_7.0x5.0mm_P2.54mm
U5: W25Q80; SOIC-8_3.9x4.9mm_P1.27mm
U8: MAX-M8W; ublox_MAX
U9: MIC5504-1.2YM5; SOT-23-5
U10: MIC5504-3.3YM5; SOT-23-5
X1: GPS; SMA_TEConnectivity_619540-1_Horizontal
X2: Serial; Jack_2.5mm_CUI_SJ-2523-SMT_Horizontal
X3: GPIO; RJ45_Amphenol_RJHSE5380
X4: USB; USB_C_Receptacle_HRO_TYPE-C-31-M-12
X5: E1; RJ45_Amphenol_RJHSE538X-02

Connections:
+1V2: C7.1, C8.1, C30.1, R4.2, U1.5 (VCC), U1.30 (VCC), U9.5 (VOUT), U10.3 (EN)
+3V3: C2.1, C3.1, C4.1, C9.1, C12.1, C13.1, C22.1, C23.1, C24.1, C32.1, D1.3 (A), D4.2 (A), J2.7, J3.7, JP1.1 (A), R6.2, R8.2, R13.2, R24.2, RN4.5 (R4.2), RN4.6 (R3.2), RN4.7 (R2.2), RN4.8 (R1.2), RN7.8, U1.1 (VCC_IO2), U1.22 (VCC_IO1), U1.24 (VPP_2V5), U1.33 (VCC_IO0), U3.16 (VCC), U4.2 (OE), U4.6 (Vcc), U5.3 (SIO2/~W), U5.7 (SIO3/~HOLD), U5.8 (VCC), U6.5, U8.7 (VCC_IO), U8.8 (VCC), U10.5 (VOUT), U11.5
+5V: C29.1, C31.1, J2.2, U2.5, U9.1 (VIN), U9.3 (EN), U10.1 (VIN), X4.A4 (VBUS), X4.A9 (VBUS), X4.B4 (VBUS), X4.B9 (VBUS)
/dbg_rx: RN3.1 (R1.1), X2.T
/dbg_tx: RN3.2 (R2.1), X2.R
/e1A/rx_bias_n: C15.1, R22.1, R23.1, RN5.2, RN5.4
/e1A/rx_bias_p: C14.1, C33.1, R20.1, R21.1, RN5.1, RN5.3, RN8.2, RN8.4
/e1A/rx_hi_n: C17.2, RN5.7, U1.38 (IOT_50B)
/e1A/rx_hi_p: C16.2, RN5.8, U1.42 (IOT_51A)
/e1A/rx_lo_n: C19.2, RN5.5, U1.31 (IOT_42B)
/e1A/rx_lo_p: C18.2, RN5.6, U1.32 (IOT_43A)
/e1A/tx_hi: R16.2, U1.43 (IOT_49A)
/e1A/tx_lo: R17.2, U1.36 (IOT_48B)
/e1A_rj1: F1.1, X5.1
/e1A_rj2: F2.1, X5.2
/e1A_rj4: F3.1, X5.4
/e1A_rj5: F4.1, X5.5
/e1B/rx_hi_n: C36.2, RN8.6, U1.25 (IOT_36B)
/e1B/rx_hi_p: C35.2, RN8.5, U1.23 (IOT_37A)
/e1B/rx_lo_n: C38.2, RN8.8, U1.27 (IOT_38B)
/e1B/rx_lo_p: C37.2, RN8.7, U1.26 (IOT_39A)
/e1B/tx_hi: R27.2, U1.34 (IOT_44B)
/e1B/tx_lo: R28.2, U1.37 (G1/IOT_45A)
/e1B_rj1: F5.1, X5.13
/e1B_rj2: F6.1, X5.14
/e1B_rj4: F7.1, X5.16
/e1B_rj5: F8.1, X5.17
/e1_led0: RN2.8 (R1.2), U3.15 (QA)
/e1_led1: RN2.5 (R4.2), U3.1 (QB)
/e1_led2: RN2.6 (R3.2), U3.2 (QC)
/e1_led3: RN2.7 (R2.2), U3.3 (QD)
/e1_led4: RN1.5 (R4.2), U3.4 (QE)
/e1_led5: RN1.6 (R3.2), U3.5 (QF)
/e1_led6: RN1.7 (R2.2), U3.6 (QG)
/e1_led7: RN1.8 (R1.2), U3.7 (QH)
/e1bias/bias0: RN7.6, U1.28 (IOT_41A)
/e1bias/bias1: RN7.5, U1.35 (G0/IOT_46B)
/e1bias/bias_0: C27.1, R21.2, R22.2, RN7.3
/e1bias/bias_1: C28.1, C34.1, R23.2, RN7.4, RN8.1, RN8.3
/e1bias/bias_fixed: C26.1, R20.2, RN7.1, RN7.2
/fpga/cdone: D2.2 (A), J3.3, RN4.2 (R2.1), RN4.3 (R3.1), U1.7 (CDONE), U3.10 (~SRCLR)
/fpga/clk_30m72: R12.1, U1.44 (G6/IOB_3B)
/fpga/clk_tune_hi: R10.2, U1.48 (IOB_4A)
/fpga/clk_tune_lo: R9.2, U1.45 (IOB_5B)
/fpga/dbg_rx_i: RN3.8 (R1.2), U1.21 (IOB_23B), U2.3
/fpga/dbg_tx_i: RN3.7 (R2.2), U1.12 (IOB_22A), U2.1
/fpga/e1_led_rclk: R7.1, U1.18 (IOB_31B), U3.12 (RCLK)
/fpga/flash_miso: J3.6, U1.17 (SPI_SDI/IOB_33B), U5.2 (SIO1/SO)
/fpga/flash_mosi: J3.8, U1.14 (SPI_SDO/IOB_32A), U3.14 (SER), U5.5 (SIO0/SI)
/fpga/flash_sck: J3.4, U1.15 (SPI_SCK/IOB_34A), U3.11 (SRCLK), U5.6 (SCK)
/fpga/gps_pps: U1.2 (IOB_6A), U8.4 (TIMEPULSE)
/fpga/gps_rx: RN6.7 (R2.2), U1.47 (IOB_2A)
/fpga/gps_tx: RN6.8 (R1.2), U1.46 (IOB_0A)
/fpga/i2c_scl: J2.3, R8.1, RN6.5 (R4.2), U1.4 (IOB_8A)
/fpga/i2c_sda: J2.5, R6.1, RN6.6 (R3.2), U1.3 (IOB_9B)
/fpga/usb_dn_i: RN3.6 (R3.2), U1.9 (IOB_16A), U2.6
/fpga/usb_dp_i: R5.1, RN3.5 (R4.2), U1.10 (IOB_18A), U2.4
/fpga/usb_pu_i: R5.2, U1.11 (IOB_20A)
/fpga/~boot_sw: R7.2, SW1.2
/fpga/~creset: J3.5, RN4.1 (R1.1), U1.8 (~CRESET_B)
/fpga/~flash_cs: J3.2, RN4.4 (R4.1), U1.16 (~SPI_CSn/IOB_35B), U5.1 (~CS)
/fpga/~gps_reset: U1.6 (IOB_13B), U8.9 (~RESET)
/gpio0: J2.8, U1.13 (IOB_24A)
/gpio1: J2.6, U1.20 (G3/IOB_25B)
/gpio2: J2.4, U1.19 (IOB_29B)
/gps/RF: D3.1 (A1), L1.2, U8.11 (RF_IN), X1.1 (In)
/gps/vbackup: BT1.1 (+), C25.1, JP1.2 (B), R19.2, U8.6 (V_BCKP)
/usb_dn: RN3.3 (R3.1), X4.A7 (D-), X4.B7 (D-)
/usb_dp: RN3.4 (R4.1), X4.A6 (D+), X4.B6 (D+)
GND: BT1.2 (-), C1.1, C2.2, C3.2, C4.2, C5.2, C6.2, C7.2, C8.2, C9.2, C10.2, C11.2, C12.2, C13.2, C14.2, C15.2, C20.2, C21.1, C22.2, C23.2, C24.2, C25.2, C26.2, C27.2, C28.2, C29.2, C30.2, C31.2, C32.2, C33.2, C34.2, C39.2, D2.1 (K), D3.2 (A2), J2.1, J3.1, R1.2, R2.1, R3.1, R14.1, R25.1, RN7.7, SW1.1, U1.49 (GND), U2.2, U3.8 (GND), U3.13 (~OE), U4.3 (GND), U5.4 (VSS), U6.2, U8.1 (GND), U8.10 (GND), U8.12 (GND), U9.2 (GND), U10.2 (GND), U11.2, X1.2 (Ext), X2.S, X4.A1 (GND), X4.A12 (GND), X4.B1 (GND), X4.B12 (GND)
unnamed: C1.2, R1.1, X4.S1 (SHIELD)
unnamed: C5.1, C6.1, R4.1, U1.29 (VCC_PLL)
unnamed: C10.1, R9.1, R10.1, R11.2
unnamed: C11.1, R11.1, U4.1 (Vctrl)
unnamed: C16.1, C19.1, R15.2, TR1.1, U6.6
unnamed: C17.1, C18.1, R15.1, TR1.3, U6.4
unnamed: C20.1, R13.1, R14.2, TR1.2
unnamed: C21.2, R18.1, U8.15 (V_ANT)
unnamed: C35.1, C38.1, R26.2, TR2.1, U11.6
unnamed: C36.1, C37.1, R26.1, TR2.3, U11.4
unnamed: C39.1, R24.1, R25.2, TR2.2
unnamed: D1.1 (RK), U1.41 (RGB2)
unnamed: D1.2 (BK), U1.39 (RGB0)
unnamed: D1.4 (GK), U1.40 (RGB1)
unnamed: D4.1 (K), R19.1
unnamed: F1.2, J4.5, U7.6
unnamed: F2.2, J4.1, U7.4
unnamed: F3.2, J4.8, U7.1
unnamed: F4.2, J4.4, U7.3
unnamed: F5.2, J5.5, U12.6
unnamed: F6.2, J5.1, U12.4
unnamed: F7.2, J5.8, U12.1
unnamed: F8.2, J5.4, U12.3
unnamed: J1.1, X3.1
unnamed: J1.2, X3.2
unnamed: J1.3, X3.3
unnamed: J1.4, X3.4
unnamed: J1.5, X3.5
unnamed: J1.6, X3.6
unnamed: J1.7, X3.7
unnamed: J1.8, X3.8
unnamed: J4.2, TR1.16
unnamed: J4.3, TR1.11
unnamed: J4.6, TR1.14
unnamed: J4.7, TR1.9
unnamed: J5.2, TR2.16
unnamed: J5.3, TR2.11
unnamed: J5.6, TR2.14
unnamed: J5.7, TR2.9
unnamed: L1.1, R18.2, U8.14 (VCC_RF)
unnamed: R2.2, X4.A5 (CC1)
unnamed: R3.2, X4.B5 (CC2)
unnamed: R12.2, U4.4 (OUT)
unnamed: R16.1, TR1.6, U6.3
unnamed: R17.1, TR1.8, U6.1
unnamed: R27.1, TR2.6, U11.3
unnamed: R28.1, TR2.8, U11.1
unnamed: RN1.1 (R1.1), X5.12
unnamed: RN1.2 (R2.1), X5.11
unnamed: RN1.3 (R3.1), X5.10
unnamed: RN1.4 (R4.1), X5.9
unnamed: RN2.1 (R1.1), X5.24
unnamed: RN2.2 (R2.1), X5.23
unnamed: RN2.3 (R3.1), X5.22
unnamed: RN2.4 (R4.1), X5.21
unnamed: RN6.1 (R1.1), U8.3 (RXD)
unnamed: RN6.2 (R2.1), U8.2 (TXD)
unnamed: JP2.2 (B), RN6.3 (R3.1)
unnamed: JP3.2 (B), RN6.4 (R4.1)
unnamed: JP2.1 (A), U8.16 (SDA)
unnamed: JP3.1 (A), U8.17 (SCL)

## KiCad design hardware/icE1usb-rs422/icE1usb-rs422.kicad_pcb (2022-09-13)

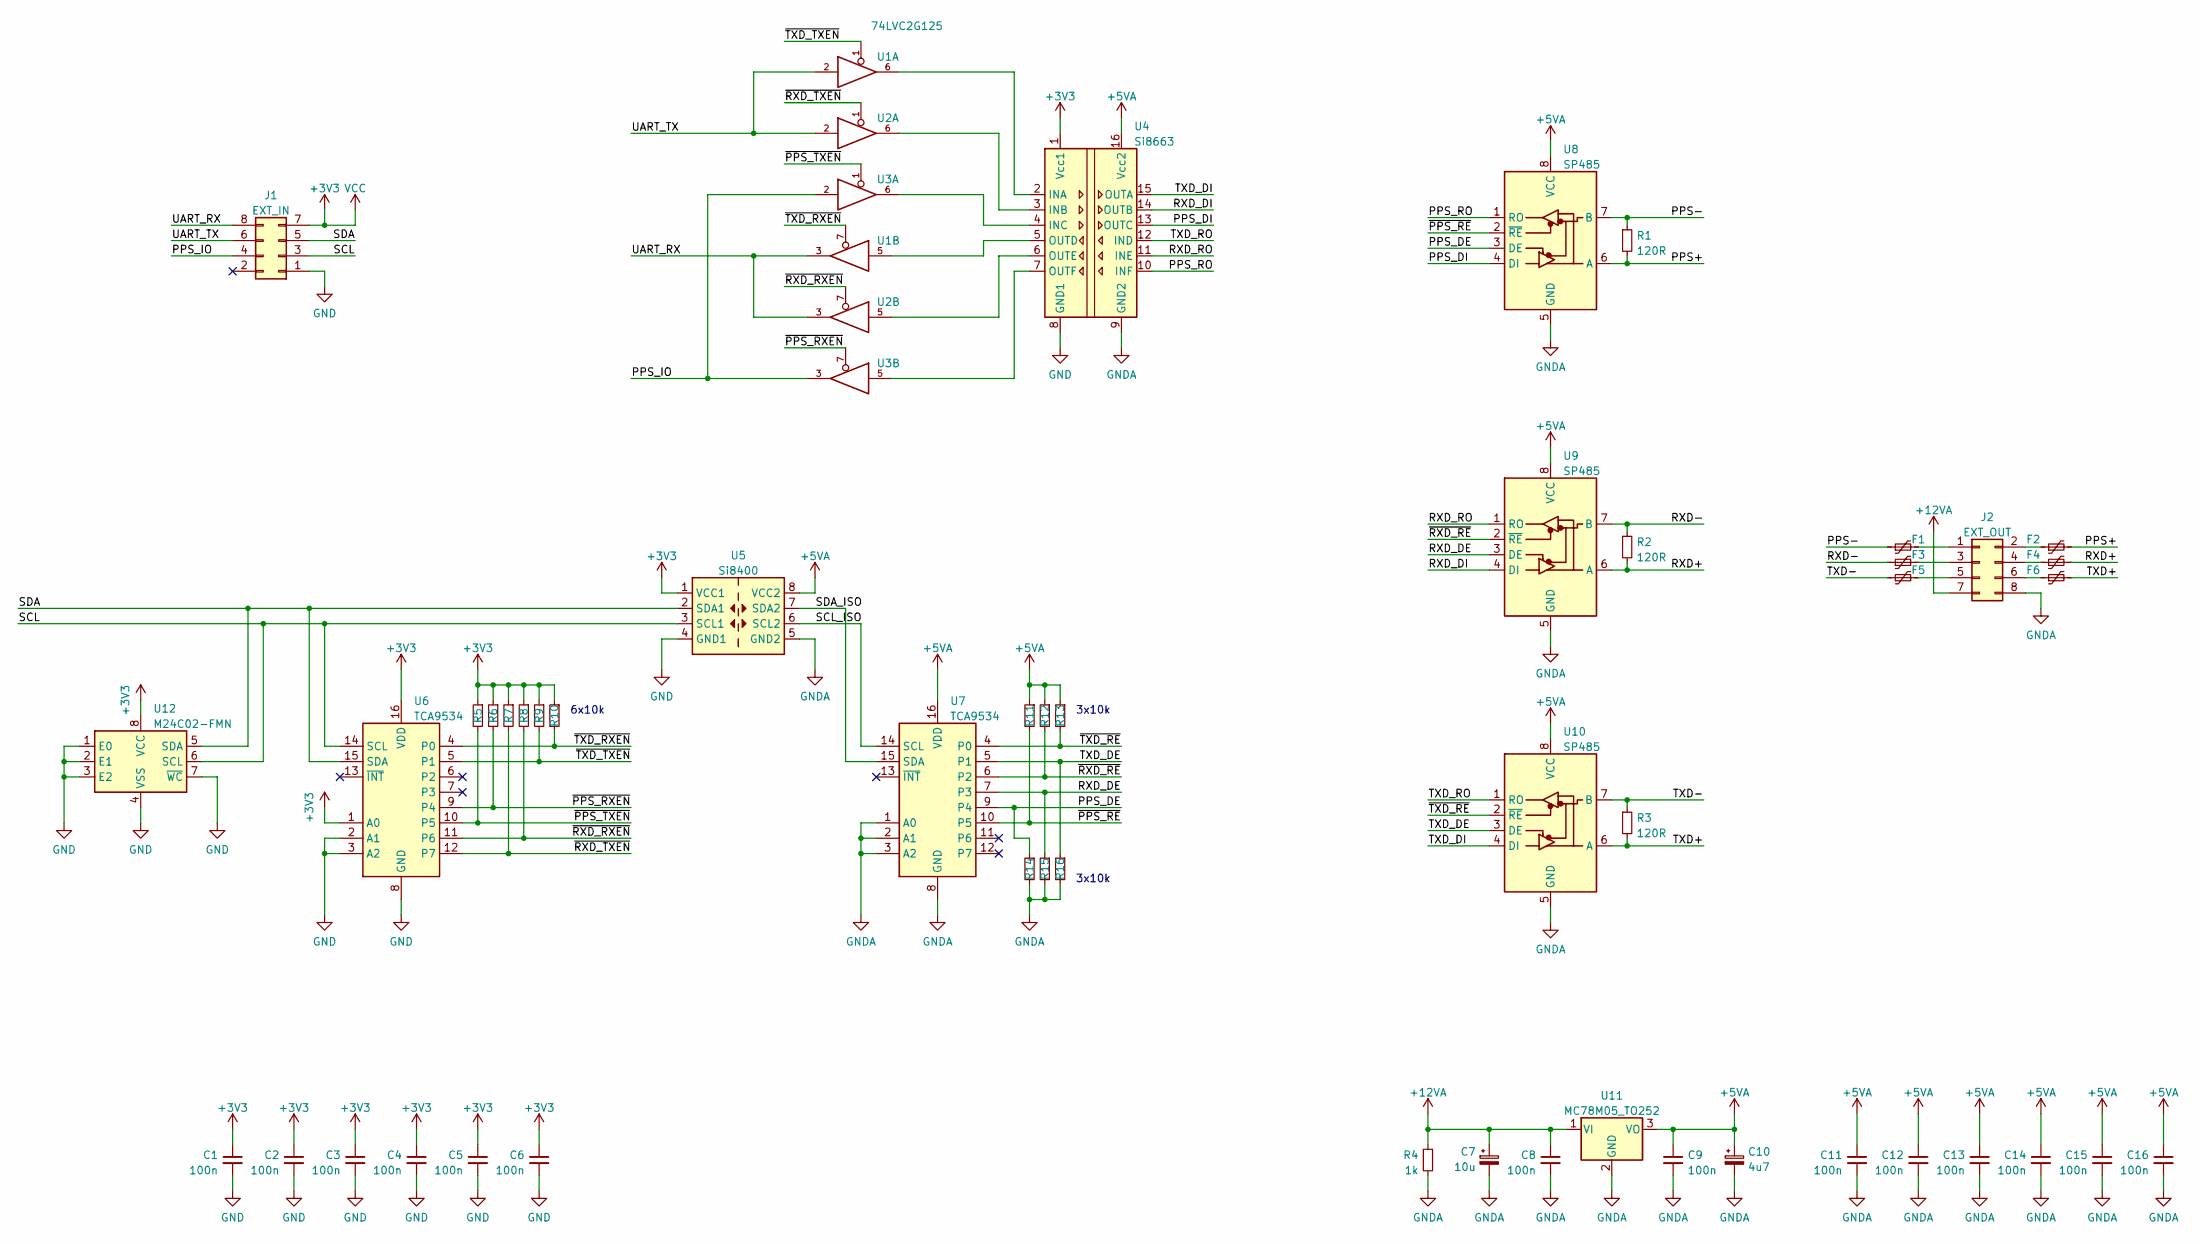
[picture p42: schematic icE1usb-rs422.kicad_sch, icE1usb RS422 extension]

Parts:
C1, C2, C3, C4, C5, C6, C8, C9, C11, C12, C13, C14, C15, C16: 100n; C_0603_1608Metric
C7: 10u; CP_EIA-3216-18_Kemet-A
C10: 4u7; CP_EIA-3216-18_Kemet-A
F1, F2, F3, F4, F5, F6: 300mA; Fuse_0603_1608Metric
J1: EXT_IN; PinSocket_2x04_P2.54mm_Vertical
J2: EXT_OUT; PinSocket_2x04_P2.54mm_Vertical
R1, R2, R3: 120R; R_0603_1608Metric
R4: 1k; R_0603_1608Metric
R5, R6, R7, R8, R9, R10, R11, R12, R13, R14, R15, R16: 10k; R_0603_1608Metric
U1, U2, U3: 74LVC2G125; TSSOP-8_3x3mm_P0.65mm
U4: Si8663; SSOP-16_3.9x4.9mm_P0.635mm
U5: Si8400; SOIC-8_3.9x4.9mm_P1.27mm
U6, U7: TCA9534; SOIC-16W_7.5x10.3mm_P1.27mm
U8, U9, U10: SP485; SOIC-8_3.9x4.9mm_P1.27mm
U11: MC78M05_TO252; TO-252-2
U12: M24C02-FMN; SOIC-8_3.9x4.9mm_P1.27mm

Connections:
+3V3: C1.1, C2.1, C3.1, C4.1, C5.1, C6.1, J1.7, R5.1, R6.1, R7.1, R8.1, R9.1, R10.1, U1.8 (VCC), U2.8 (VCC), U3.8 (VCC), U4.1 (Vcc1), U5.1 (VCC1), U6.1 (A0), U6.16 (VDD), U12.8 (VCC)
+5VA: C9.1, C10.1, C11.1, C12.1, C13.1, C14.1, C15.1, C16.1, R11.1, R12.1, R13.1, U4.16 (Vcc2), U5.8 (VCC2), U7.16 (VDD), U8.8 (VCC), U9.8 (VCC), U10.8 (VCC), U11.3 (VO)
+12VA: C7.1, C8.1, J2.7, R4.1, U11.1 (VI)
/PPS+: F2.2, R1.2, U8.6 (A)
/PPS-: F1.1, R1.1, U8.7 (B)
/PPS_DE: R14.1, U7.9 (P4), U8.3 (DE)
/PPS_DI: U4.13 (OUTC), U8.4 (DI)
/PPS_IO: J1.4, U3.2, U3.3
/PPS_RO: U4.10 (INF), U8.1 (RO)
/RXD+: F4.2, R2.2, U9.6 (A)
/RXD-: F3.1, R2.1, U9.7 (B)
/RXD_DE: R15.1, U7.7 (P3), U9.3 (DE)
/RXD_DI: U4.14 (OUTB), U9.4 (DI)
/RXD_RO: U4.11 (INE), U9.1 (RO)
/SCL: J1.3, U5.3 (SCL1), U6.14 (SCL), U12.6 (SCL)
/SCL_ISO: U5.6 (SCL2), U7.14 (SCL)
/SDA: J1.5, U5.2 (SDA1), U6.15 (SDA), U12.5 (SDA)
/SDA_ISO: U5.7 (SDA2), U7.15 (SDA)
/TXD+: F6.2, R3.2, U10.6 (A)
/TXD-: F5.1, R3.1, U10.7 (B)
/TXD_DE: R16.1, U7.5 (P1), U10.3 (DE)
/TXD_DI: U4.15 (OUTA), U10.4 (DI)
/TXD_RO: U4.12 (IND), U10.1 (RO)
/UART_RX: J1.8, U1.3, U2.3
/UART_TX: J1.6, U1.2, U2.2
/~PPS_RE: R11.2, U7.10 (P5), U8.2 (~RE)
/~PPS_RXEN: R6.2, U3.7, U6.9 (P4)
/~PPS_TXEN: R5.2, U3.1, U6.10 (P5)
/~RXD_RE: R12.2, U7.6 (P2), U9.2 (~RE)
/~RXD_RXEN: R8.2, U2.7, U6.11 (P6)
/~RXD_TXEN: R7.2, U2.1, U6.12 (P7)
/~TXD_RE: R13.2, U7.4 (P0), U10.2 (~RE)
/~TXD_RXEN: R10.2, U1.7, U6.4 (P0)
/~TXD_TXEN: R9.2, U1.1, U6.5 (P1)
GND: C1.2, C2.2, C3.2, C4.2, C5.2, C6.2, J1.1, U1.4 (GND), U2.4 (GND), U3.4 (GND), U4.8 (GND1), U5.4 (GND1), U6.2 (A1), U6.3 (A2), U6.8 (GND), U12.1 (E0), U12.2 (E1), U12.3 (E2), U12.4 (VSS), U12.7 (~WC)
GNDA: C7.2, C8.2, C9.2, C10.2, C11.2, C12.2, C13.2, C14.2, C15.2, C16.2, J2.8, R4.2, R14.2, R15.2, R16.2, U4.9 (GND2), U5.5 (GND2), U7.1 (A0), U7.2 (A1), U7.3 (A2), U7.8 (GND), U8.5 (GND), U9.5 (GND), U10.5 (GND), U11.2 (GND)
unnamed: F1.2, J2.1
unnamed: F2.1, J2.2
unnamed: F3.2, J2.3
unnamed: F4.1, J2.4
unnamed: F5.2, J2.5
unnamed: F6.1, J2.6
unnamed: U1.5, U4.5 (OUTD)
unnamed: U1.6, U4.2 (INA)
unnamed: U2.5, U4.6 (OUTE)
unnamed: U2.6, U4.3 (INB)
unnamed: U3.5, U4.7 (OUTF)
unnamed: U3.6, U4.4 (INC)

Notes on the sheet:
6x10k
3x10k

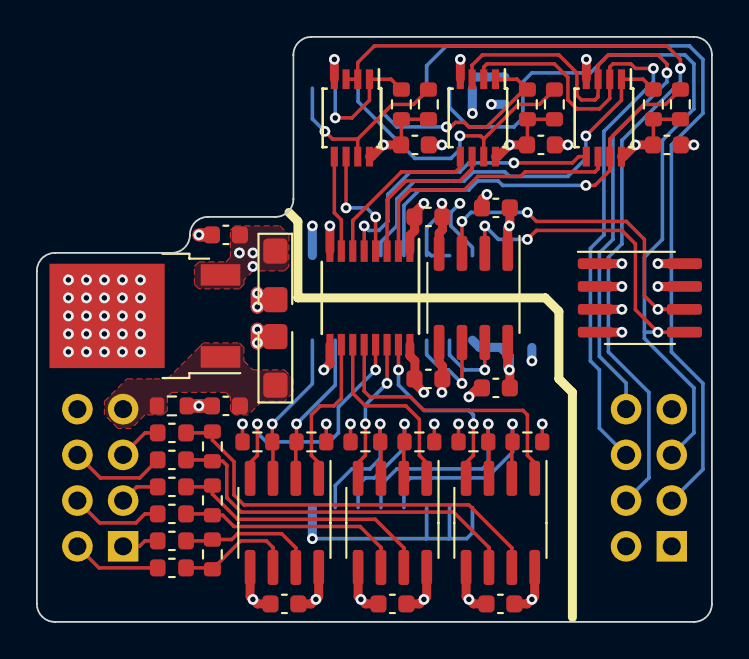
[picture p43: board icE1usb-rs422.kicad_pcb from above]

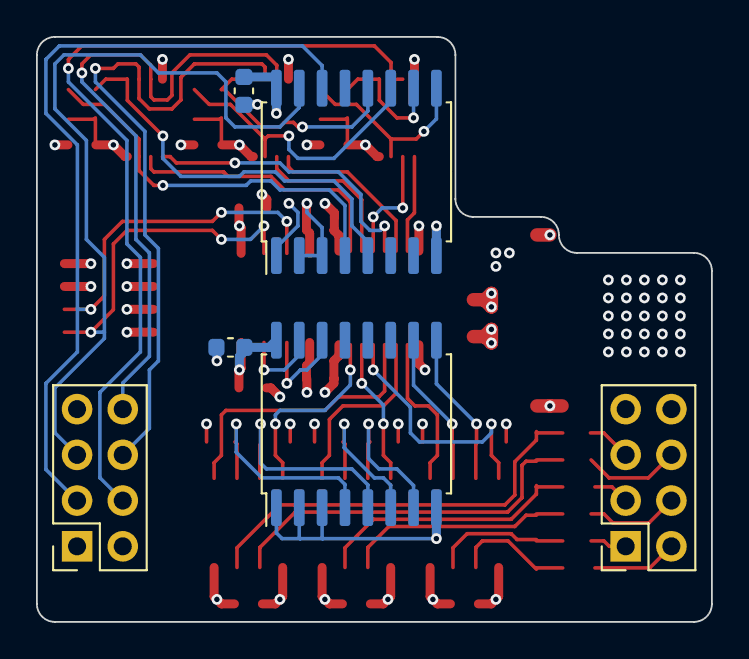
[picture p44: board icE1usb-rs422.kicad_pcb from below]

Board: 4 copper layers, 37.5 x 32.5 mm, 52 parts (6 on the bottom side), 48 nets.

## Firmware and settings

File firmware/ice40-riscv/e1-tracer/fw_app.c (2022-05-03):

/*
 * fw_app.c
 *
 * Copyright (C) 2019-2020  Sylvain Munaut <tnt@246tNt.com>
 * SPDX-License-Identifier: GPL-3.0-or-later
 */

#include <stdint.h>
#include <stdbool.h>
#include <string.h>

#include <no2usb/usb.h>
#include <no2usb/usb_dfu_rt.h>

#include "console.h"
#include "e1.h"
#include "led.h"
#include "misc.h"
#include "mini-printf.h"
#include "spi.h"
#include "usb_e1.h"
#include "utils.h"


extern const struct usb_stack_descriptors app_stack_desc;

static void
serial_no_init()
{
	uint8_t buf[8];
	char *id, *desc;
	int i;

	flash_manuf_id(buf);
	printf("Flash Manufacturer : %s\n", hexstr(buf, 3, true));

	flash_unique_id(buf);
	printf("Flash Unique ID    : %s\n", hexstr(buf, 8, true));

	/* Overwrite descriptor string */
		/* In theory in rodata ... but nothing is ro here */
	id = hexstr(buf, 8, false);
	desc = (char*)app_stack_desc.str[1];
	for (i=0; i<16; i++)
		desc[2 + (i << 1)] = id[i];
}

static void
boot_dfu(void)
{
	/* Force re-enumeration */
	usb_disconnect();

	/* Boot firmware */
	reboot(1);
}

void
usb_dfu_rt_cb_reboot(void)
{
	boot_dfu();
}



static uint8_t
liu_read_reg(unsigned chan, uint8_t reg)
{
        uint8_t cmd = reg | 0x20;
	uint8_t rv;
        struct spi_xfer_chunk xfer[2] = {
                { .data = (void*)&cmd, .len = 1, .read = false, .write = true,  },
                { .data = (void*)&rv,  .len = 1, .read = true,  .write = false, },
        };
        spi_xfer(SPI_CS_LIU(chan), xfer, 2);
	return rv;
}

static void
liu_write_reg(unsigned chan, uint8_t reg, uint8_t val)
{
        uint8_t cmd[2] = { reg, val };
        struct spi_xfer_chunk xfer[2] = {
                { .data = (void*)cmd, .len = 2, .read = false, .write = true,  },
	};
        spi_xfer(SPI_CS_LIU(chan), xfer, 1);
}



#define USB_RT_LIU_REG_WRITE	((1 << 8) | 0x42)
#define USB_RT_LIU_REG_READ	((2 << 8) | 0xc2)


static bool
_liu_reg_write_done_cb(struct usb_xfer *xfer)
{
	struct usb_ctrl_req *req = xfer->cb_ctx;
	unsigned chan = req->wIndex - 0x81;

	liu_write_reg(chan, req->wValue, xfer->data[0]);

	return true;
}

static enum usb_fnd_resp
_liu_ctrl_req(struct usb_ctrl_req *req, struct usb_xfer *xfer)
{
	unsigned chan;

	/* If this a vendor request for the E1 endpoints */
	if (USB_REQ_RCPT(req) != USB_REQ_RCPT_EP)
		return USB_FND_CONTINUE;

	if (req->wIndex < 0x81 || req->wIndex > 0x82)
		return USB_FND_CONTINUE;

	if (USB_REQ_TYPE(req) != USB_REQ_TYPE_VENDOR)
		return USB_FND_CONTINUE;

	chan = req->wIndex - 0x81;

	/* */
	switch (req->wRequestAndType)
	{
	case USB_RT_LIU_REG_WRITE:
		xfer->len = 1;
		xfer->cb_done = _liu_reg_write_done_cb;
		xfer->cb_ctx = req;
		break;

	case USB_RT_LIU_REG_READ:
		xfer->len = 1;
		xfer->data[0] = liu_read_reg(chan, req->wValue);
		break;

	default:
		goto error;
	}

	return USB_FND_SUCCESS;

error:
	return USB_FND_ERROR;
}

static struct usb_fn_drv _liu_drv = {
	.ctrl_req = _liu_ctrl_req,
};



void main()
{
	int cmd = 0;

	/* Init console IO */
	console_init();
	puts("Booting App image..\n");

	/* LED */
	led_init();
	led_state(true);

	/* SPI */
	spi_init();

	/* Enable USB directly */
	serial_no_init();
	usb_init(&app_stack_desc);
	usb_dfu_rt_init();
	usb_register_function_driver(&_liu_drv);
	usb_e1_init();

	usb_connect();
	e1_init();

	/* Main loop */
	while (1)
	{
		/* Prompt ? */
		if (cmd >= 0)
			printf("Command> ");

		/* Poll for command */
		cmd = getchar_nowait();

		if (cmd >= 0) {
			if (cmd > 32 && cmd < 127) {
				putchar(cmd);
				putchar('\r');
				putchar('\n');
			}

			switch (cmd)
			{
			case 'u':
				usb_debug_print();
				break;
			case 'e':
				e1_debug_print(false);
				break;
			case 'E':
				e1_debug_print(true);
				break;
			default:
				break;
			}
		}

		/* USB poll */
		usb_poll();

		/* E1 poll */
		e1_poll();
		usb_e1_run();
	}
}

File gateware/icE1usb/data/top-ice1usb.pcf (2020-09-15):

# E1 PHY
set_io e1A_rx_hi_p 42
set_io e1A_rx_hi_n 38
set_io e1A_rx_lo_p 32
set_io e1A_rx_lo_n 31
set_io e1A_tx_hi   43
set_io e1A_tx_lo   36

set_io e1B_rx_hi_p 23
set_io e1B_rx_hi_n 25
set_io e1B_rx_lo_p 26
set_io e1B_rx_lo_n 27
set_io e1B_tx_hi   34
set_io e1B_tx_lo   37

set_io e1_rx_bias[0] 28
set_io e1_rx_bias[1] 35

# USB
set_io usb_dp 10
set_io usb_dn  9
set_io usb_pu 11

# Flash
set_io -pullup yes flash_mosi 14
set_io -pullup yes flash_miso 17
set_io -pullup yes flash_clk  15
set_io -pullup yes flash_cs_n 16

# LED Shift register + Button input
set_io -pullup yes e1_led_rclk 18

# GPS
set_io -pullup yes gps_reset_n 6
set_io -pullup yes gps_rx 47
set_io -pullup yes gps_tx 46
set_io             gps_pps 2

# I2C
set_io i2c_sda 3
set_io i2c_scl 4

# GPIOs
set_io -pullup yes gpio[0] 13
set_io -pullup yes gpio[1] 20
set_io -pullup yes gpio[2] 19

# Clock
set_io clk_in 44

set_io clk_tune_hi 48
set_io clk_tune_lo 45

# Debug UART
set_io -pullup yes dbg_rx 21
set_io -pullup yes dbg_tx 12

# RGB LEDs
set_io rgb[0] 39
set_io rgb[1] 40
set_io rgb[2] 41

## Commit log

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2011-12-24 re-wire SPI connector to reflect pin-out of Olimex devel board UEXT
    [e1_xcvr.sch]
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2011-12-24 add solder jumper to bypass TPS736XX (if it is not populated)
    [e1_xcvr.sch]
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2011-12-24 re-route the entire board to add test pads and additional components
    [e1_xcvr.brd]
2011-12-24 add two LEDs (power and LOS) plus required transistor
    [e1_xcvr.sch]
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2011-12-26 re-route complete board, add PWR jumper, LED series resistor
    [e1_xcvr.brd, e1_xcvr.sch]
2011-12-26 remove stray GNDIO wire, add junction, approve some warnings
    [e1_xcvr.sch]
2011-12-26 approve lots of warnings about thinner wires
    Christan has routed lots of wires thinner than what the network specific
    rules state. We approve all of them as we don't care about thinner
    wires.
    [e1_xcvr.brd]
2012-01-14 give parts names without "$", use 47nH as L1 (1206)
    [e1_xcvr.brd, e1_xcvr.sch]
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2012-07-01 laforge.lbr: fix amphenol sim reader footprint
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2018-05-16 sam4s-e1.gnumeric: Avoid EXT4, add wire colors
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2018-05-29 connect LIU's pin 44 to GND (solves OSM#3247)
    [e1_xcvr.brd, e1_xcvr.sch]
2018-05-29 replace old PULSE_T1094NL footprint, repair pin assignment (solves OSM#3269)
    [e1_xcvr.brd, e1_xcvr.sch]
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2019-12-20 change font to vector / update to v2
    [e1_xcvr.brd]
2019-12-20 squash most parts and avoid silk screen overlaps all over the place
    [e1_xcvr.brd]
2019-12-20 enlarge board to have proper mounting holes for mechanical mounting
    [e1_xcvr.brd]
2019-12-20 increase clearance of ground planes; pad roundness
    [e1_xcvr.brd]
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2020-08-06 e1-tracer: PCB almost ready
    ... with some room for improvement: LEDs might go to the right of the
    2x RJ45
    [e1-tracer.brd, e1-tracer.sch]
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2020-08-11 e1-tracer: 'update' our generic rc lib again to purge '..@1' packages
    [e1-tracer.brd, e1-tracer.sch]
2020-08-11 e1-tracer: reapir missing VDD_3V3 on serial debug out's TVS
    [e1-tracer.brd, e1-tracer.sch]
2020-08-12 e1-tracer: add 2x 33R series resistors in USB wires
    and
    * update improved HC73 package
    * move upper third of PCB (LIUs and XOs) left
    [e1-tracer.brd, e1-tracer.sch]
2020-08-12 e1-tracer: improve power bypassing on LIU's VDDT and VDDA
    ...by placing 2x 22u per LIU (instead of 68u DNP), shrinking packages
    from 1206 to 0805
    [e1-tracer.brd, e1-tracer.sch]
2020-08-12 e1-tracer: add a generic 0603 blue LED type w/ Vf=2.8V
    designating LTST-C193TBKT-5A for now
    [e1-tracer.brd, e1-tracer.sch]
2020-08-14 e1-tracer: have more clearance of VBUS trace on PCB edge
    [e1-tracer.brd, e1-tracer.sch]
2020-08-14 e1-tracer: 4x 0R on R and B LED color selection wires
    [e1-tracer.brd, e1-tracer.sch]
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2020-08-14 e1-tracer: annotate jumper JP1 signals in silk screen
    [e1-tracer.brd]
2020-08-14 e1-tracer: start a last renumber (after inserting 4x 0R)
    [e1-tracer.brd, e1-tracer.sch]
2020-08-14 e1-tracer: update from ICE40 lib after minor Eagle pin dir change
    [e1-tracer.sch]
2020-08-14 e1-tracer: update again from ice40 lib
    Another pin was found with 'wrong' direction state. Severity of this
    is low as is shows only warnings in ERC, removing it anyways during
    verification.
    [e1-tracer.sch]
2020-08-14 e1-tracer: further shrink the GND and 3V3 copper inwards left and right
    ... and run a local DRC
    [e1-tracer.brd, e1-tracer.sch]
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2020-08-30 e1-tracer: denote CC-BY-SA 4.0 in schema (adds to SYS#5052)
    [e1-tracer.sch]
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2020-09-04 big hardware directory re-organization in preparation of ice40 merge
    [e1-tracer.brd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]
2020-09-04 e1-xcvr: Add missing gerber output (was uncommitted in my tree)
    [e1_xcvr.gbl, e1_xcvr.gbo, e1_xcvr.gbp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]
2020-09-13 mechanical: Import all design files for the icE1usb case
    [akg_55_24.dxf, back_panel.FCStd, back_panel.dxf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]
2020-09-14 hardware/icE1usb-proto: Import the early prototype eagle files
    For archival purposes only, shouldn't really be used to produce anything.
    [icE1usb-proto.brd, icE1usb-proto.sch]
2020-09-14 hardware/icE1usb: Initial import of the production hardware design files
    [e1bias.sch, e1if.sch, fpga.sch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]
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2020-09-15 fw/ice40-riscv: Fix reboot to bootloader
    Address was from previous gateware ...
    [fw_app.c]
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2020-10-03 gateware/icE1usb: Replace custom I2C core with SB_I2C wrapper
    The hard IP kind of sucks ... but we don't need i2c much (or at
    all really) and using the hard IP is nearly free (LC-wise).
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2020-10-09 gateware/icE1usb: Fix readback of E1 led misc register
    e1_led_run is already included in e1_led signal ... (bit 8)
2020-10-11 mechanical/e1-tracer: add rich CAD construction + stripped dxf for a faceplate
    adresses: SYS#5088
    [e1-tracer-faceplate_contruction.dxf, e1-tracer-faceplate_export.dxf]
2020-10-11 mechanical/e1-tracer: add CAD construction + stripped dxf for a fischer bgt modular faceplate. uses 2x GB4 mounting block (segor)
    [e1-tracer-faceplate_fischer_bgt_tfp_construction.dxf, e1-tracer-faceplate_fischer_bgt_tfp_export.dxf]
2020-10-21 e1-tracer faceplates: Reduce RJ45 cut-out by 0.8mm in height and 0.5mm in width
    Tests with prototypes have shown that above the RJ45 jack, there is a
    0.95mm gap, and towards both sides there's a total of 0.7mm. Let's
    reduce that to 0.15mm on top and 0.10mm on either side.
    [e1-tracer-faceplate_contruction.dxf, e1-tracer-faceplate_export.dxf, e1-tracer-faceplate_fischer_bgt_tfp_construction.dxf]
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2020-10-29 firmware/ice40-riscv: Create a reboot() function
    instead of direct access to registers.
    [fw_app.c]
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2020-10-29 firmware/ice40-riscv/e1-tracer: Remove CDC descriptors
    This was never used and doesn't really belong here, this was just
    an example descriptor in the original firmware this is based on.
2020-10-29 firmware/ice40-riscv/e1-tracer: Fix e1_tick_read()
    This was broken when moving the design to non-hacked multi channel
    E1.
2020-10-29 firmware/ice40-riscv: Fix a couple of 'mixed signedness' warnings
    [spi.c]
2020-10-29 firmware/ice40-riscv/icE1usb: Remove a obsolete debug command
    This doesn't even do anything on this SoC ...
    [fw_app.c]
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2020-12-03 e1-tracer: solve everything towards v2
    * retract light guides and RJ45 1.5mm inwards (solves SYS#5051)
    * SPI MOSI/MISO mismatch fixed (solves SYS#5050)
    * footpint mismatch to BOM for L3,L4 fixed (solves SYS#5053)
    * PCB had to get 5mm slimmer (adresses SYS#5088)
    * repaired silk on name bott side
    * DRC
    [e1-tracer.brd, e1-tracer.sch]
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2020-12-17 firmware: Rename fw_app.bin to icE1usb-fw.bin / e1_tracer-fw.bin
    This is clearly much more descriptive, and avoids mixing up firmware
    files for different boards
2020-12-17 contrib/jenkins.sh 'publish' fixes
    * don't install icE1usb files to e1-tracer directory
    * don't replicate symlinks but copy
2020-12-19 osmo_e1f.c: Fix CRC4 insertion
    When encoding the CRC bit for Frame number 0 and 8 in the multiframe,
    we must first move the CRC4 into those of the last SMF.
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2020-12-20 icE1usb fw: Use green per-port LED to indicate alignment status
    Whenever Rx is aligned, the green LED is permanently on.
    Whenever Rx is not aligned, the green LED is blinking.
    What's missing is to check for E1 clock ticks and turn the LED off
    completely if there are no clock ticks.
    [e1.h]
2020-12-27 e1-tracer: update BOM attributes to 1st v2 prod run parts
    * L2, L3 now 0805
    * R6, R7 now 0402
    * IC4 now ASEMB-12.000MHZ-LC-T
    * RoHS state enabled again in scraper, not yet used in BOM
    [e1-tracer.brd, e1-tracer.sch, e1-tracer_eBOM.csv]
2021-01-05 icE1usb fw: Expose error conditions from E1 driver
    This will allow the USB interface code to report the errors to the
    host PC.
    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
    [e1.h]
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2022-01-02 icE1usb firmware: Detect A-bit in TS0; report via USB + LED
    Scan over every odd E1 frame TS0 byte to check if the A-bit is set,
    indicating a remote alarm. If so, set yellow LED and report via the
    error flags communicated to the host by USB interrupt transfer.
    [e1.h]
2022-01-09 icE1usb fw: Fix computation of received E1 frames from USB
    Several issues :
    - The reported length includes the CRC so it's minus 6 and
    not minus 4. (2 for CRC, 4 for header)
    - Cast length to int to make it signed so the minus works
    - If the packet is empty, this would be negative (no header),
    underflow, and then try to submit a giant number of frames
    to the E1 hardware
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2022-01-09 icE1usb fw: Tweak descriptors in preparation for dual port support
    In dual port mode we can't have 388 bytes wMaxPacket size, that's
    too much reserved bandwidth.
    So we dial that back to 292 which is the minimum we can use. We need
    4 bytes for header, then 256 byte of nominal transfer size then 32
    more byte for potentially one more frame than nominal to compensate
    differences between E1 clock and USB clock.
    We obviously need to adapt the code filling up the packets to respect
    that more restricted size ...
2022-01-09 icE1usb fw: Better flow regulation mechanism
    * FIFO target level :
    - The '8 * 16' makes no sense as the FIFO was 128 so this
    is the "full" case and could never be that high.
    - We tighten up the margin around 5 * 16 which is the "target"
    level for the FIFO
    * FIFO size :
    We also increase the FIFO size to 256 frames. This doesn't
    actually affect latency since the target level is the same,
    but it allows more leeway to recover without data loss in
    case something goes wrong.
    * Ticks :
    We don't bother using ticks ... the current algo wasn't
    working (or rather not doing anything all that useful),
    because the difference between USB clock and E1 clock is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
2022-01-10 icE1usb fw: Distinguish between E1 FIFO init and reset
    Currently it's called 'reset' but really it's the init because
    it sets up the memory allocation and such. We rename that to e1f_init
    and introduce a true e1f_reset that only clears the fifo and resets
    the pointers
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2022-01-10 icE1usb fw: Update E1 core start/stop procedure
    Previously we were just doing a hard reset, calling init again.
    And to stop, it was a bit harsh as well, just calling init with
    0 as argument, not cleaning pending descriptors and such.
    Now, the HW is initialized once and there is proper startup and
    shutdown procedure, leaving things in the proper state.
    Init of e1 hardware (call to e1_init) is also delegated to usb_e1
    since it's that module that handles all state changes and config
    so it makes sense it handles init too rather than calling it from
    fw_app.c
    [e1.h, fw_app.c]
2022-01-13 icE1usb fw: Fix the E1 shutdown process
    So, once BD are submitted to hw, we have to wait for them to get
    back, and that's what the SHUTDOWN state is for. Now, this needs
    to completete before we can call e1_start() again and so in case
    it wasn't done in time, we just busy waited in e1_start().
    Problem is that in the absence of a valid signal, the RX side won't
    process anything and so we will wait forever.
    For the TX side, if we are in remote tick config and we never had
    any valid signal, this could also hang.
    So we change this. There is actually no need to wait for the shutdown
    to complete, we can resume where we left off.
    For RX: We use the 'RECOVER' which basically waits for all pending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
2022-01-13 icE1usb fw: Add function to enable/disable E1 led runner
    Also don't force enable the runner in the e1_platform_led_set
    callback.
    Due to GPIO shortage, the E1 leds control are multiplexed with
    SPI so this adds a method to temporarely stop the runner so SPI
    can be used.
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2022-01-13 icE1usb fw: New ICE1USB_INTF_GET_ERRORS control request
    This allows the host driver to obtain the current errors, as they would
    normally be reported over the IRQ endpoint. One important use case for
    this is to obtain the initial error state when the driver starts up.
2022-01-13 icE1usb fw: Import GPS module driver code
    This only initializes the GPS module and keeps track of the
    antenna and fix status
    [fw_app.c, gps.c]
2022-01-16 icE1usb doc: DAHDI driver no longer experimental
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2022-02-24 manual: add info and renders to show to set TE/NT mode
    The page break is currently a bit ugly, but I didn't see an easy way
    to fix it. The images and info text should make the process much clearer.
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2022-05-03 gateware/icE1usb: Replace local I2C core with no2misc one
    This core has been merged (and improved) upstream, so
    update the submodule, remove local copy and make the required
    tweaks.
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2022-05-03 gateware/icE1usb: Use custom I2C core by default rather than SB_I2C
    SB_I2C is apparently just a pain to use and buggy and such, so
    use our custom one.
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2022-09-05 hardware/icE1usb: Remove panelized version
    Further production runs will use another panel setup anyway
    and this one is archived in r1.0 anyway.
    But this cleans up the way for kicad 6 update
    [icE1usb-panel.kicad_pcb]
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2022-09-05 hardware/icE1usb: kicad 6 resync sch/pcb + cleanup
    Just the automated resync + the track/via cleanup pass
    [icE1usb.kicad_pcb]
2022-09-05 hardware/icE1usb: Add NO jumpers in the GPS I2C lines
    Fixes OS#5664
    [gps.kicad_sch, icE1usb.kicad_pcb, icE1usb.kicad_sch]
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2022-10-04 icE1usb fw/gpsdo: Use PID loop instead of ad-hoc algo
    The original algo is just somehting I originally came up with
    on the spot and worked and I never got the time to revisit.
    Now after some testing, I implemented a PID loop that seems to
    present faster lock time and at least as good stability.
    Parameters were not thorougly optimized just some 'hand' tuning
    trying to simulate the behavior.
2022-10-04 icE1usb fw: Add Notify PPS on Carrier Detect option
    This is disabled by default because turns out the kernel doesn't
    actually support PPS on CD for USB-CDC devices :(
    And this also increase the interrupt traffic ...
2022-10-31 import latest e1-tracer host software
    This was originally in https://github.com/smunaut/ice40-playground
    but has meanwhile been removed, only a fork at
    https://github.com/laf0rge/ice40-playground remained.
    Let's import the code here. The history is not all that exciting
    so I'm saving myself the effort of git filter-branch or the like
    to import the actual old commits.
    The commit log is here for reference:
    commit bd36d40cc30acbae68978df79eff03f0539a9a21
    Author: Harald Welte <laforge@osmocom.org>
    Date: Fri Sep 4 10:21:51 2020 +0200
    e1-recorder main.c: Don't exist just because one ISO transfer failed
    I get LIBUSB_TRANSFER_ERROR every so often (once every few hours) on my
    lapt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
    [idt82v2081_regs.h]
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2022-11-01 fw/e1-tracer: restrict dfu programming to e1-tracer devices
    Let's explicitly specify the VID/PID of the e1-tracer in the dfu-util
    invocation 'make dfuprog' to avoid accidentially programming other
    attached dfu capable devices.
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2022-11-01 fw/e1-tracer: Additional USB configuration for "osmo-e1d compatible mode"
    This adds a second USB configuration to the e1-tracer firmware. This
    configuration is closer to the USB configuration of an icE1usb and hence
    paves the way for using osmo-e1d with the tracer.
    The main conceptual difference between the existing "legacy"
    configuration and this new "e1d compatible" configuration is to have two
    USB interfaces, one for each direction of the traced E1 interface. Each
    interface has its own separate two altsettings, one for the disabled
    and one for the enabled state.
    Unmodified osmo-e1d will not work straight away with this, as it expects
    ISO OUT and ISU Feedback endpoints, which a pure rx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
2022-11-01 fw/e1-tracer: Initialize IDT82V2081 from within firmware in e1d mode
    Initially it was a good choice to keep the LIU driver in the host
    software (easier debugging/changes). However, we never really needed it
    to do anything but initialization of the LIU.
    So in order to avoid having to teach osmo-e1d or other software the
    details about the LIU initialization, let's do this from the firmware
    *if* the e1d compatible USB configuration is used.
    Closes: OS#5733
    [idt82v2081_no2spi.c, idt82v2081_regs.h]
2022-11-02 fw/e1-tracer: Fix bNumInterfaces in new configuration
    This fixes the following Linux kernel error message on the host:
    usb 1-1: config 2 has 2 interfaces, different from the descriptor's value: 3
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2022-11-09 hardware/icE1usb: Kicad file minor updates
    * Renumber schematic pages
    * Update the info cards with new data and r1.1
    [e1bias.kicad_sch, e1if.kicad_sch, fpga.kicad_sch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]
2022-11-09 hardware/icE1usb: Add production files snapshot for r1.1
    Was produced directly off the kicad files AFAIK.
    [e1bias.kicad_sch, e1if.kicad_sch, fpga.kicad_sch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]
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2024-03-06 icE1usb fw: Workaround some apparent GCC aliasing bug ...
    If the code is built either :
    * without -flto
    * with -fno-strict-aliasing
    * with that struct as 'static' (so it's not on the stack)
    Then all works fine. But in the current situation (without the
    patch), GCC seems to think there is some aliasing and just plain
    removed the `notif.bits = 1` bit of code in that functions
    (no warnings printed ...).
    Putting the struct as 'static' is the least awful workaround.
    I didn't bother reporting bug upstream, because I can't reproduce
    on a small test case and I'm sure I'd just get yelled at and that
    the compiler is right for some reason ...
    Change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
2024-04-30 icE1usb fw: Add AIS error flag and fill it along with LOS from linemon
    Now that we monitor low level line status, we can fill in a proper
    LOS signal along with the newly introduced AIS flag
    [e1.h]
2024-04-30 icE1usb fw: Rework the way LEDs are used and updated
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

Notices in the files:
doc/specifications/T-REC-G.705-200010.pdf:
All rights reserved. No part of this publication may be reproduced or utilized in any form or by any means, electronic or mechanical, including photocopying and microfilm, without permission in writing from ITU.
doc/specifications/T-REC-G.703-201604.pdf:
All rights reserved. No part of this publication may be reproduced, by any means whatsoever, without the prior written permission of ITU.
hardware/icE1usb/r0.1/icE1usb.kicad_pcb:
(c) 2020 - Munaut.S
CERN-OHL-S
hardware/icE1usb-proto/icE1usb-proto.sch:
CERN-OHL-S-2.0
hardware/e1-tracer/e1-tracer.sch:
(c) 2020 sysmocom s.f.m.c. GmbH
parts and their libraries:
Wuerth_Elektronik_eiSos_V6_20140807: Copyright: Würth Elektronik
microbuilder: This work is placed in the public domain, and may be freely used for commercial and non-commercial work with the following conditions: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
